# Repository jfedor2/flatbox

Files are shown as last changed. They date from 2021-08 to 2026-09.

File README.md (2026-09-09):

# Flatbox: Low profile hitbox-layout fightstick

This repository contains 3D-printable models, PCB design files and code needed to make an arcade controller that looks like this:

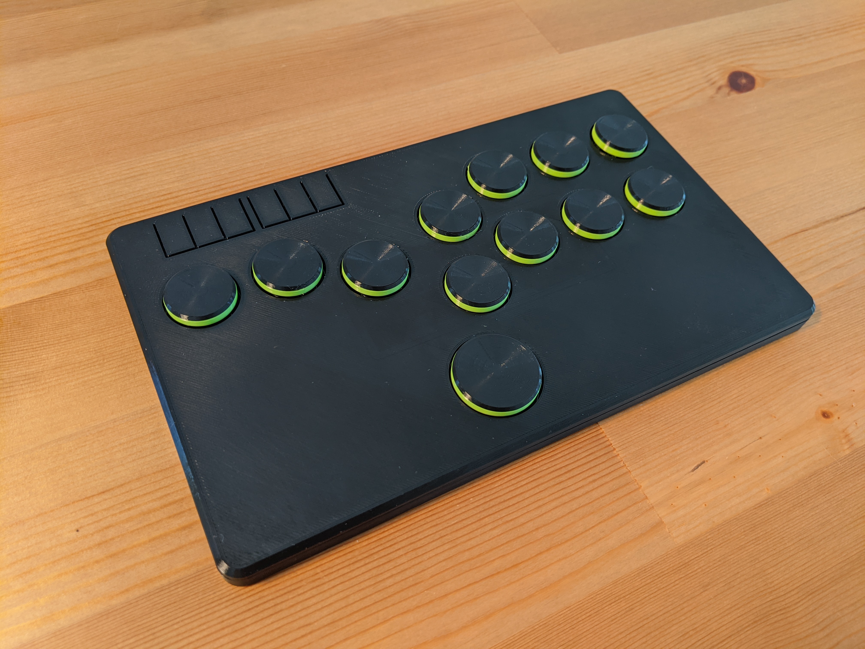
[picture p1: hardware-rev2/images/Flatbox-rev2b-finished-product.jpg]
Assembled Flatbox


There are ten major versions of the Flatbox. They all use Kailh low profile (choc v1) mechanical keyboard switches. The table below lists their main features. See the README for each version for details on how to make them.

version | case dimensions (mm) | compatibility | add-on board | onboard chip | SMT assembly required | firmware
------- | --------------- | ------------- | ------------ | ------------ | --------------------- | --------
[rev1.1](hardware-rev1.1) | 218x128x10 | PC, PS3 | Arduino Pro Micro | - | no | [ATmega32U4](firmware-atmega32u4)
[rev2](hardware-rev2) | 218x130x10 | PC, PS3 | - | ATmega32U4 | yes | [ATmega32U4](firmware-atmega32u4)
[rev3](hardware-rev3) | 218x130x10 | PC, PS3, PS4 or PC, Switch, PS3, PS4, PS5\* | [Brook PS3/PS4](https://www.brookaccessory.com/detail/58690501/) or [P5 mini](https://www.brookaccessory.com/detail/92299183/) | - | yes | [Brook](https://www.brookaccessory.com/download/)
[rev4.1](hardware-rev4.1) | 218x130x11 | PC, PS3, PS4\*, PS5\*, Switch | - | RP2040 | yes | [GP2040-CE](https://gp2040-ce.info/)
[rev5](hardware-rev5) | 218x126x10 | PC, PS3, PS4\*, Switch | [RP2040-Zero](https://www.waveshare.com/rp2040-zero.htm) | - | no | [GP2040-CE](https://gp2040-ce.info/)
[rev6](hardware-rev6) | 218x126x10 | PC, Switch | - | CH552T | yes | [CH552](firmware-ch552)
[rev7.2](hardware-rev7.2) | 218x130x11 | PC, Switch | [Xiao nRF52840 Plus](https://www.seeedstudio.com/Seeed-Studio-XIAO-nRF52840-Plus-p-6359.html) | - | no | [PGF](https://github.com/jfedor2/portable-gamepad-firmware)
[rev8](hardware-rev8) | 218x130x11 | PC, PS3, PS4\*, PS5\*, Switch | - | RP2350 | yes | [GP2040-CE](https://gp2040-ce.info/)
[rev9](hardware-rev9) | 218x130x11 | PC, Switch | - | SAMD21 | yes | [PGF](https://github.com/jfedor2/portable-gamepad-firmware)
[rev10](hardware-rev10) | 218x130x11 | PC, Switch | - | STM32G0B1 | yes | [PGF](https://github.com/jfedor2/portable-gamepad-firmware)

\* - with caveats

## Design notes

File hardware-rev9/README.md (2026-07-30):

# Flatbox rev9

This is rev9 of the Flatbox. In this version the PCB includes the microcontroller (a SAMD21 chip) - everything is built in, you only have to add the switches (and flash the firmware).

There are two variants of the case, version A uses flaps for the option buttons, version B has holes so that you can use buttoncaps on the tact switches:

Flatbox rev9 case variants

To make one you will need:

* [3D printed case parts](3d-printed-case) - top and bottom
* [the PCB](pcb)
* 12x Kailh low profile (choc v1) switches of your choice
* (optionally) 12x Kailh low profile hotswap sockets
* buttoncaps for the action buttons, either [3D printed](../3d-printed-buttoncaps) or (preferably) injection molded (make sure they're the correct size: 22.5mm and 28.5mm)
* for case variant A:
  * 6x 6x6x5mm tact switches
* for case variant B:
  * 6x 6x6x7mm tact switches
  * 6x silicone buttoncaps (like [these](https://www.aliexpress.com/item/32846395636.html) or search for "silicone button caps" on AliExpress; or you can use other caps as long as they fit, the hole diameter is 7.5mm)
* 7x M3x6 flat head (countersunk) screws
* 5x M2x4 screws to secure the PCB to the case
* some kind of rubber feet or non-slip padding for the bottom
* a soldering iron

I printed the case at 0.20mm layer height. The top part should be printed upside-down, the bottom part should be printed as-is. They don't require supports.

I used [JLCPCB](https://jlcpcb.com/) to make the PCB and assemble the SMD parts. The [included files](pcb) can be used with JLCPCB directly. If you want to use some other service, check the file formats that they expect. When ordering from JLCPCB, upload the Gerber zip, leave all the settings at default (you can choose the PCB color), then enable "PCB Assembly" and upload the BOM and CPL files in the next step. PCB thickness should be 1.6mm.

The PCB you get from JLCPCB will look like this:

Flatbox rev9 PCB with SMD parts assembled

The switches can be soldered in directly to the PCB or you can use hotswap sockets.

There are various ways that you can put firmware on the board and make it into a functional controller. Here's what I did. The relevant files are in the [binaries](binaries) folder.

1. Using an ST-Link V2 clone debug interface, put a UF2 bootloader on the board. Wire SWDIO, SWDCLK, RESET and GND lines between the ST-Link and the board and connect the board to a PC over USB for power. Then flash the bootloader with this command:<br>
`openocd -f openocd_stlink_samd21.cfg -c "init; program bootloader-flatbox_rev9-d514d82.bin verify reset; shutdown"`
2. Disconnect the ST-Link from the board.
3. Now when you connect the board to a PC, a USB drive named "FLATBOXREV9" should appear. Copy the [pgf-flatbox_rev9.uf2](https://github.com/jfedor2/portable-gamepad-firmware/releases/latest/download/pgf-flatbox_rev9.uf2) file to that drive. The board should now act as a game controller.

The UF2 firmware file used above is the [Portable Gamepad Firmware](https://github.com/jfedor2/portable-gamepad-firmware). You can find the Flatbox-specific UF2 bootloader modifications [here](https://github.com/jfedor2/uf2-samdx1/tree/flatbox-rev9). The openocd_stlink_samd21.cfg file is taken from [here](https://github.com/todbot/samd21-programming-notes).

You only have to flash the bootloader the first time. If you ever want to flash another UF2 file, press the RESET button twice quickly.

If you want to modify the case or the PCB, check out the files in the [extras](extras) folder.

Flatbox rev9 exploded view of the 3D printed case

PCB design licensed under [CC BY-SA 4.0](https://creativecommons.org/licenses/by-sa/4.0/).

PCB design uses the following libraries:

* [keyswitches.pretty](https://github.com/daprice/keyswitches.pretty) by [daprice](https://github.com/daprice) ([CC BY-SA 4.0](https://creativecommons.org/licenses/by-sa/4.0/))
* [Type-C.pretty](https://github.com/ai03-2725/Type-C.pretty) by [ai03-2725](https://github.com/ai03-2725)

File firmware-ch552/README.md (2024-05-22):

This is gamepad firmware that runs on the CH552T chip. It works with Flatbox [rev6](../hardware-rev6).

It is a minor modification of Stefan Wagner's [CH552-MouseWiggler](https://github.com/wagiminator/CH552-MouseWiggler).

To compile the firmware you need the `sdcc` compiler. To flash the firmware you need the `pyusb` Python module.

To build the firmware, run `make bin`.

To build and flash the firmware onto a board, hold the "BOOT" button while plugging the board into your computer, then run `make flash` immediately after.

To flash an existing binary, hold the "BOOT" button while plugging the board into your computer, then run `python3 tools/chprog.py gamepad.bin` immediately after.

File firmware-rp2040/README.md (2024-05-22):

This is the firmware I originally wrote for the RP2040 versions of the Flatbox ([rev4](../hardware-rev4) and [rev5](../hardware-rev5)). It is very simple and easy to understand and modify. It works with PC and PS3.

Since then, [GP2040-CE](https://gp2040-ce.info/) emerged as the de facto standard firmware for RP2040-based boards. It has many nice features like remappable buttons and configurable SOCD cleaner. You probably just want to use that instead of the firmware here. Go to the [GP2040-CE downloads page](https://gp2040-ce.info/downloads/) and get the UF2 file matching your board (Flatbox rev4 or rev5, *not* the Waveshare RP2040-Zero one, even if your rev5 board uses it).

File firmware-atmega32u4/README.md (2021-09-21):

This is Arduino code for a USB arcade controller, meant to be used with ATmega32U4-based boards like the Arduino Pro Micro.

It works with Flatbox [rev1](../hardware-rev1), [rev1.1](../hardware-rev1.1) and [rev2](../hardware-rev2).

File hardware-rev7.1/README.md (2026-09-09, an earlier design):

# Flatbox rev7.1

_**Please note**: There's a newer version of this Flatbox variant: [rev7.2](../hardware-rev7.2). It uses a Xiao Plus board and doesn't need the I/O expander._

This is rev7.1 of the Flatbox. In this version a [Seeed Studio XIAO nRF52840](https://www.seeedstudio.com/Seeed-XIAO-BLE-nRF52840-p-5201.html) board is soldered onto the main PCB.

There are two variants of the case, version A uses flaps for the option buttons, version B has holes so that you can use buttoncaps on the tact switches:

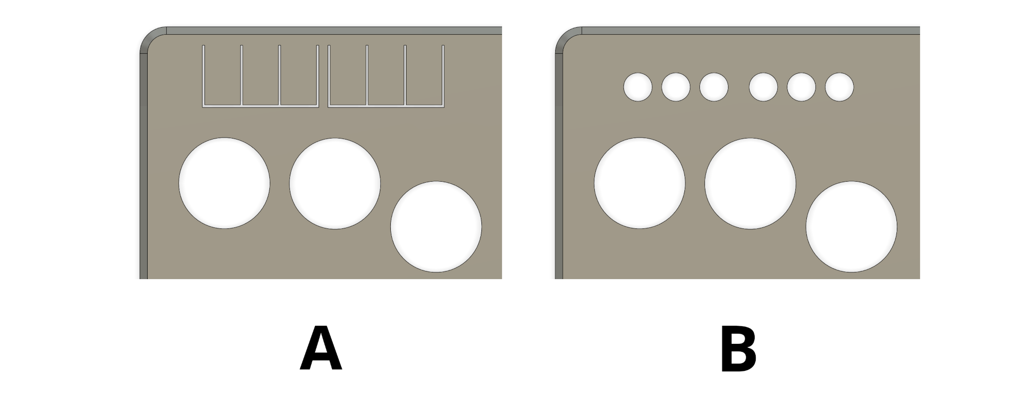
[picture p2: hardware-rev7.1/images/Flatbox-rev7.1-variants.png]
Flatbox rev7.1 case variants


To make one you will need:

* [3D printed case parts](3d-printed-case) - top and bottom
* [the Flatbox PCB](pcb)
* [Seeed Studio XIAO nRF52840](https://www.seeedstudio.com/Seeed-XIAO-BLE-nRF52840-p-5201.html)
* [MCP23S17-E/SP](https://www.microchip.com/en-us/product/mcp23s17) SPI I/O expander
* lipo battery - I used [this 1200mAh one from Pimoroni](https://shop.pimoroni.com/products/lipo-battery-pack?variant=20429082183)
* 12x Kailh low profile (choc v1) switches of your choice
* (optionally) 12x Kailh low profile hotswap sockets
* [3D printed buttoncaps](../3d-printed-buttoncaps)
* 6x 6x6x5mm tact switches
* 7x M3x6 flat head (countersunk) screws
* (optionally) 5x M2x4 screws to secure the PCB to the case
* some kind of rubber feet or non-slip padding for the bottom
* a soldering iron

I think this [lipo battery from Adafruit](https://www.adafruit.com/product/258) is the same thing as the Pimoroni one, though I'm not sure about the cable length.

Make sure you get the MCP23S17 expander in DIP package. Observe pin 1 orientation when soldering.

I printed the case at 0.20mm layer height. The top part should be printed upside-down, the bottom part should be printed as-is. They don't require supports.

The PCB can be ordered from a number of online services using the included [Gerber files](pcb), I used [JLCPCB](https://jlcpcb.com/) (leave all the settings at default, you can choose the PCB color). PCB thickness should be 1.6mm.

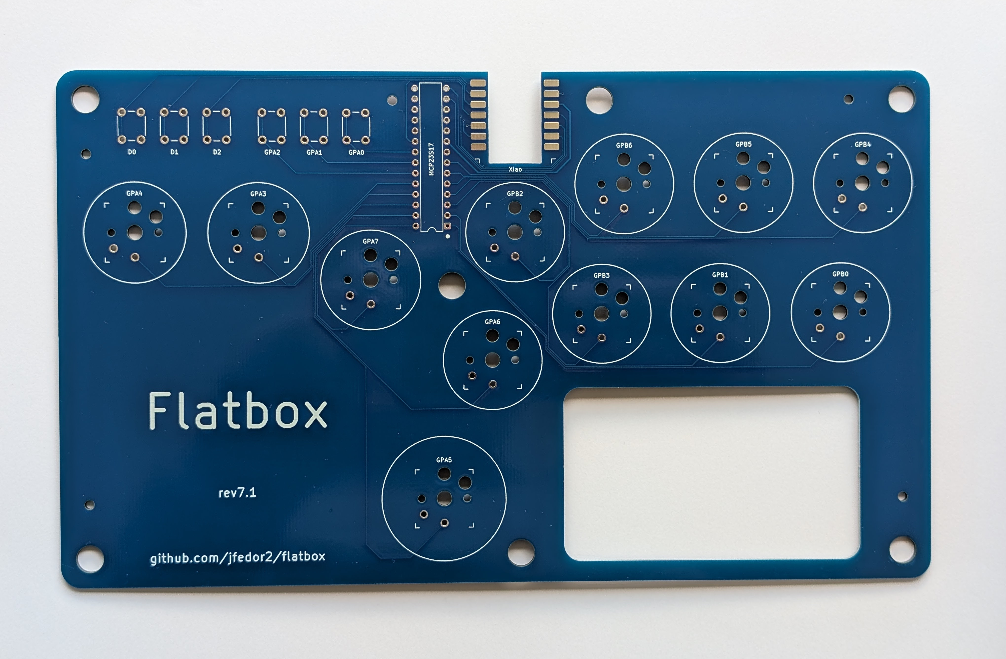
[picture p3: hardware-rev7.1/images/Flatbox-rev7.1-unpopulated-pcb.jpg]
Flatbox rev7 unpopulated PCB


The switches can be soldered in directly to the PCB or you can use hotswap sockets.

You will need to cut off the plug on the battery and solder the wires directly to pads on the bottom of the Xiao board.

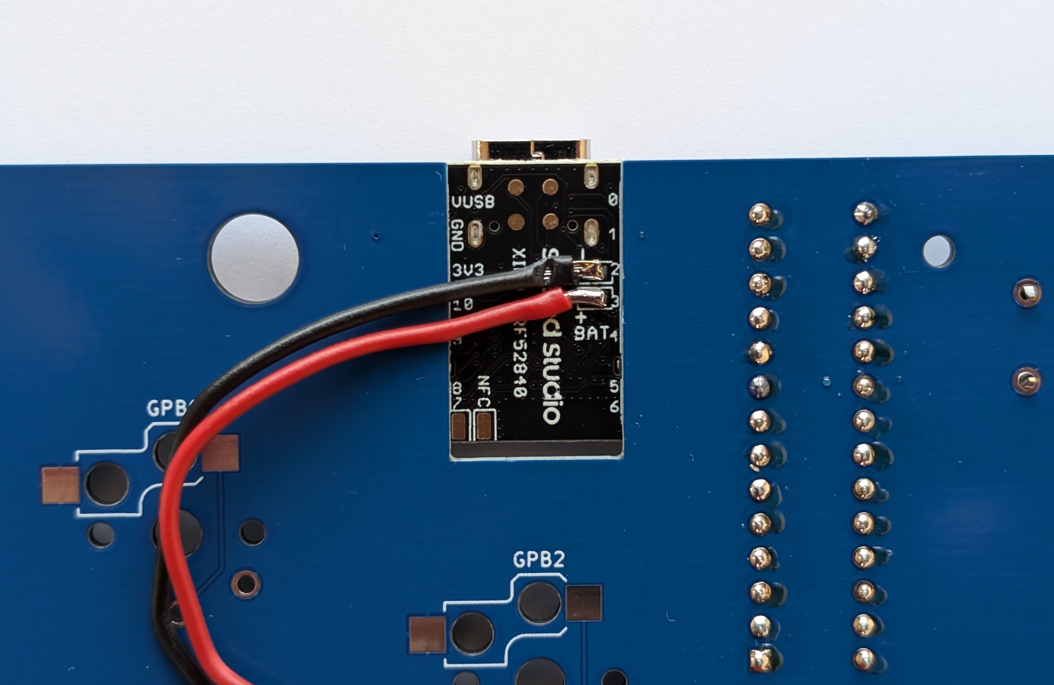
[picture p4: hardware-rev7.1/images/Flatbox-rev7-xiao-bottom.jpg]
Flatbox rev7 battery wiring


To flash the firmware, download the [pgf-flatbox\_rev7.1-nrf52840.uf2](https://github.com/jfedor2/portable-gamepad-firmware/releases/latest/download/pgf-flatbox_rev7.1-nrf52840.uf2) file from the [Portable Gamepad Firmware](https://github.com/jfedor2/portable-gamepad-firmware) repository. Then connect the board to your computer using a USB cable and press the RESET button on the Xiao board twice quickly (the RESET button is really small, next to the USB port). A USB drive should appear on your computer. Copy the `pgf-flatbox_rev7.1-nrf52840.uf2` file to that drive.

See the [Portable Gamepad Firmware](https://github.com/jfedor2/portable-gamepad-firmware) repository for general usage instructions.

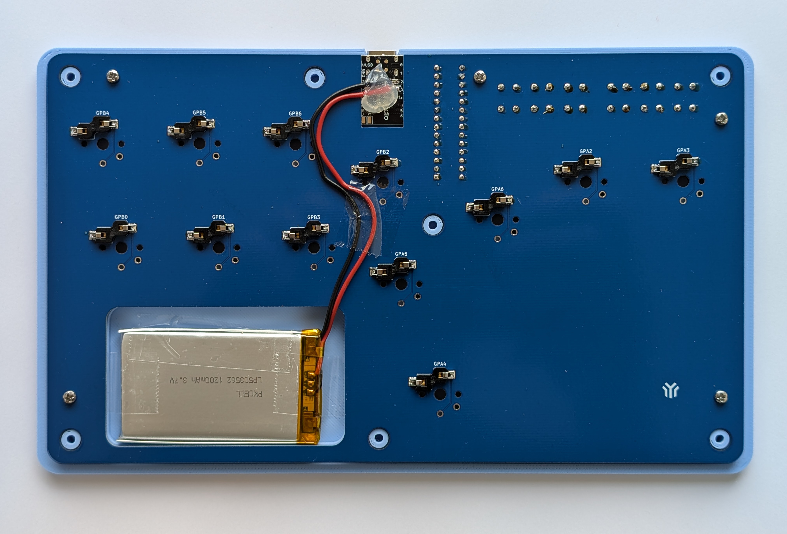
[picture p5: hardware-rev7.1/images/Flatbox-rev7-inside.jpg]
Flatbox rev7 inside the case


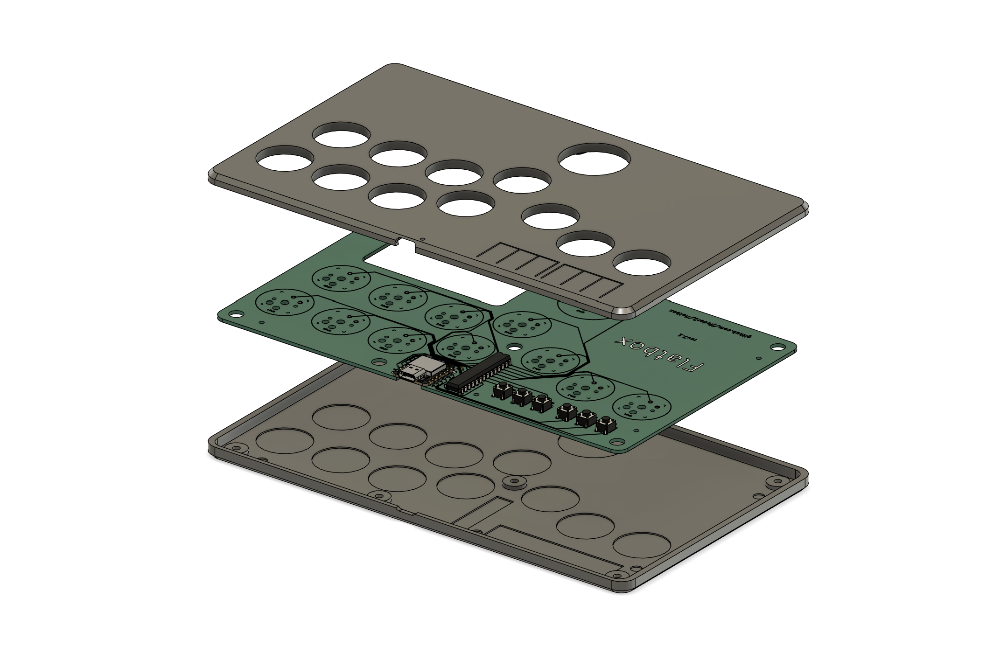
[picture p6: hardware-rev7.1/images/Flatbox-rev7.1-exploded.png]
Flatbox rev7.1 exploded view of the case


PCB design licensed under [CC BY-SA 4.0](https://creativecommons.org/licenses/by-sa/4.0/).

PCB/case design uses the following:

* [keyswitches.pretty](https://github.com/daprice/keyswitches.pretty) by [daprice](https://github.com/daprice) ([CC BY-SA 4.0](https://creativecommons.org/licenses/by-sa/4.0/))
* Xiao STEP file downloaded from [GrabCAD](https://grabcad.com/library/seeed-studio-xiao-nrf52840-sense-1)

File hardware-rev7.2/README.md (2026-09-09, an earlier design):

# Flatbox rev7.2

This is rev7.2 of the Flatbox. In this version a [Seeed Studio XIAO nRF52840 Plus](https://www.seeedstudio.com/Seeed-Studio-XIAO-nRF52840-Plus-p-6359.html) board is soldered onto the main PCB.

There are two variants of the case, version A uses flaps for the option buttons, version B has holes so that you can use buttoncaps on the tact switches:

Flatbox rev7.2 case variants

To make one you will need:

* [3D printed case parts](3d-printed-case) - top and bottom
* [the Flatbox PCB](pcb)
* [Seeed Studio XIAO nRF52840 Plus](https://www.seeedstudio.com/Seeed-Studio-XIAO-nRF52840-Plus-p-6359.html)
* lipo battery - I used [this 1200mAh one from Pimoroni](https://shop.pimoroni.com/products/lipo-battery-pack?variant=20429082183)
* 12x Kailh low profile (choc v1) switches of your choice
* (optionally) 12x Kailh low profile hotswap sockets
* [3D printed buttoncaps](../3d-printed-buttoncaps)
* 6x 6x6x5mm tact switches
* 7x M3x6 flat head (countersunk) screws
* (optionally) 5x M2x4 screws to secure the PCB to the case
* some kind of rubber feet or non-slip padding for the bottom
* a soldering iron

I think this [lipo battery from Adafruit](https://www.adafruit.com/product/258) is the same thing as the Pimoroni one, though I'm not sure about the cable length.

I printed the case at 0.20mm layer height. The top part should be printed upside-down, the bottom part should be printed as-is. They don't require supports.

The PCB can be ordered from a number of online services using the included [Gerber files](pcb), I used [JLCPCB](https://jlcpcb.com/) (leave all the settings at default, you can choose the PCB color). PCB thickness should be 1.6mm.

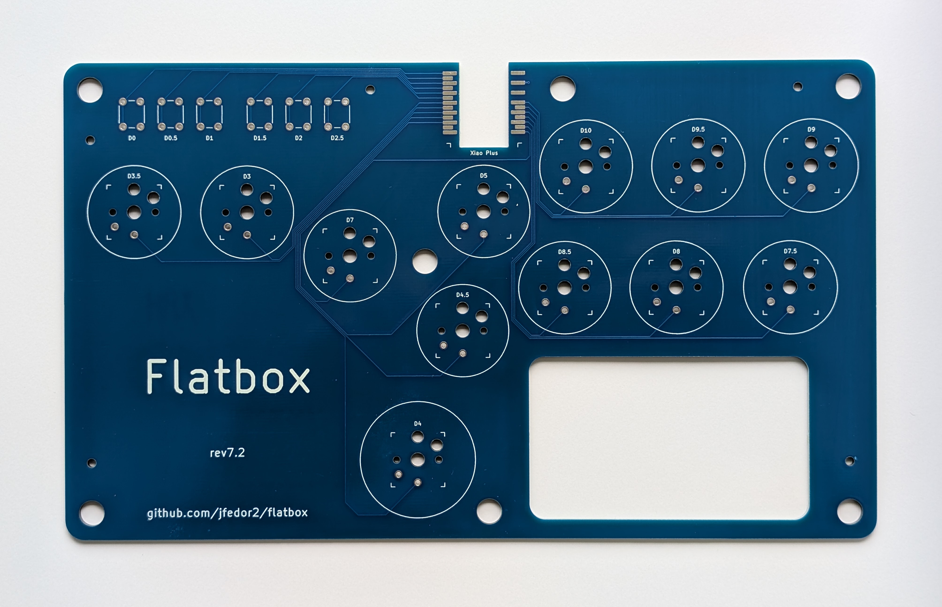
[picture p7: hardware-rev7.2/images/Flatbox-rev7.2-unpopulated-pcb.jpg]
Flatbox rev7.2 unpopulated PCB


The switches can be soldered in directly to the PCB or you can use hotswap sockets.

You will need to cut off the plug on the battery and solder the wires directly to pads on the bottom of the Xiao board.

The castellated pads on the Xiao Plus board are close together so make sure to avoid bridges. When in doubt use flux.

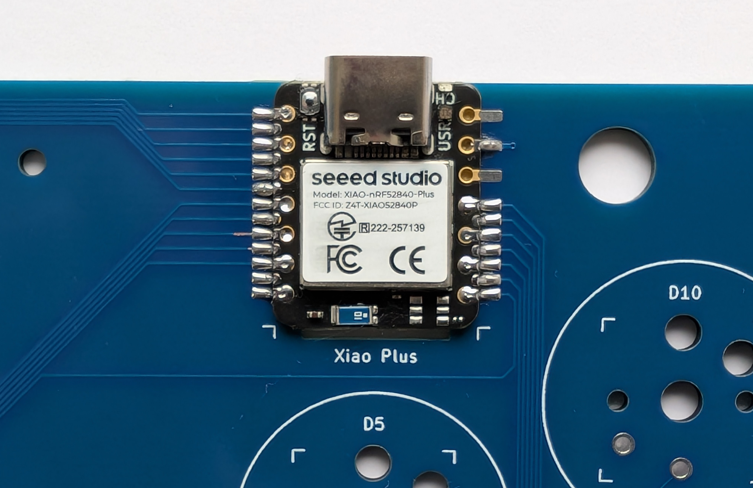
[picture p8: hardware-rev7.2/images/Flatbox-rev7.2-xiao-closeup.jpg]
Flatbox rev7.2 soldered Xiao closeup


To flash the firmware, download the [pgf-flatbox\_rev7.2-nrf52840.uf2](https://github.com/jfedor2/portable-gamepad-firmware/releases/latest/download/pgf-flatbox_rev7.2-nrf52840.uf2) file from the [Portable Gamepad Firmware](https://github.com/jfedor2/portable-gamepad-firmware) repository. Then connect the board to your computer using a USB cable and press the RESET button on the Xiao board twice quickly (the RESET button is really small, next to the USB port). A USB drive should appear on your computer. Copy the `pgf-flatbox_rev7.2-nrf52840.uf2` file to that drive.

See the [Portable Gamepad Firmware](https://github.com/jfedor2/portable-gamepad-firmware) repository for general usage instructions.

Flatbox rev7.2 exploded view of the case

PCB design licensed under [CC BY-SA 4.0](https://creativecommons.org/licenses/by-sa/4.0/).

PCB/case design uses the following:

* [keyswitches.pretty](https://github.com/daprice/keyswitches.pretty) by [daprice](https://github.com/daprice) ([CC BY-SA 4.0](https://creativecommons.org/licenses/by-sa/4.0/))
* Xiao STEP file downloaded from [GrabCAD](https://grabcad.com/library/seeed-studio-xiao-nrf52840-sense-1)

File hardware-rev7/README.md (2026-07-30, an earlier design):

# Flatbox rev7

This is rev7 of the Flatbox. In this version a [Seeed Studio XIAO nRF52840](https://www.seeedstudio.com/Seeed-XIAO-BLE-nRF52840-p-5201.html) board is soldered onto the main PCB.

To make one you will need:

* [3D printed case parts](3d-printed-case) - top and bottom
* [the Flatbox PCB](pcb)
* [Seeed Studio XIAO nRF52840](https://www.seeedstudio.com/Seeed-XIAO-BLE-nRF52840-p-5201.html)
* [MCP23017-E/SP](https://www.microchip.com/en-us/product/mcp23017) I2C I/O expander
* lipo battery - I used [this 1200mAh one from Pimoroni](https://shop.pimoroni.com/products/lipo-battery-pack?variant=20429082183)
* 12x Kailh low profile (choc v1) switches of your choice
* (optionally) 12x Kailh low profile hotswap sockets
* [3D printed buttoncaps](../3d-printed-buttoncaps)
* 6x 6x6x5mm tact switches
* 7x M3x6 flat head (countersunk) screws
* (optionally) 5x M2x4 screws to secure the PCB to the case
* some kind of rubber feet or non-slip padding for the bottom
* a soldering iron

I think this [lipo battery from Adafruit](https://www.adafruit.com/product/258) is the same thing as the Pimoroni one, though I'm not sure about the cable length.

Make sure you get the MCP23017 expander in DIP package. Observe pin 1 orientation when soldering.

I printed the case at 0.20mm layer height. The top part should be printed upside-down, the bottom part should be printed as-is. They don't require supports.

The PCB can be ordered from a number of online services using the included [Gerber files](pcb), I used [JLCPCB](https://jlcpcb.com/) (leave all the settings at default, you can choose the PCB color). PCB thickness should be 1.6mm.

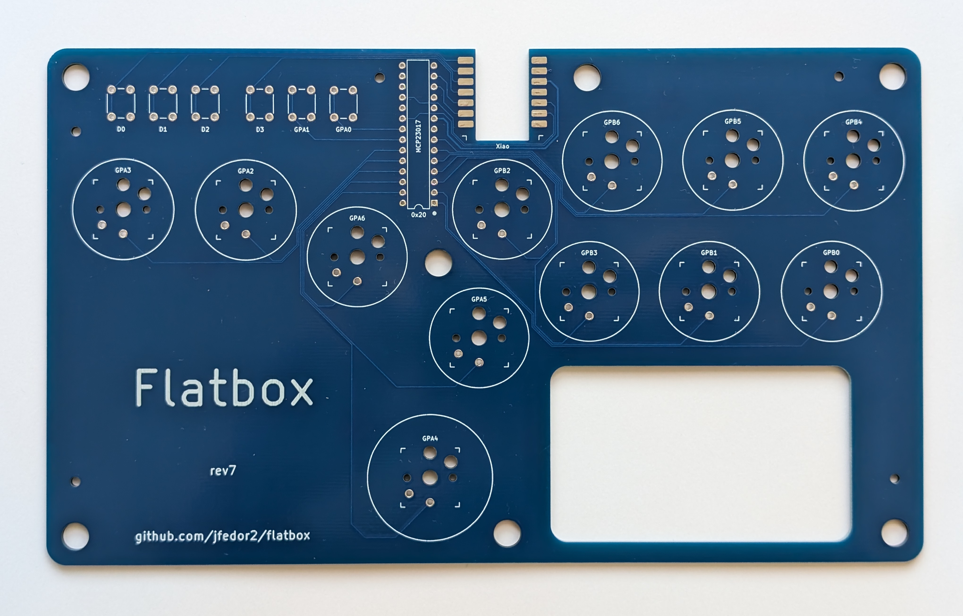
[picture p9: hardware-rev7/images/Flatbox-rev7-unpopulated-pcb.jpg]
Flatbox rev7 unpopulated PCB


The switches can be soldered in directly to the PCB or you can use hotswap sockets.

You will need to cut off the plug on the battery and solder the wires directly to pads on the bottom of the Xiao board.

Flatbox rev7 battery wiring

To flash the firmware, download the [pgf-flatbox\_rev7-nrf52840.uf2](https://github.com/jfedor2/portable-gamepad-firmware/releases/latest/download/pgf-flatbox_rev7-nrf52840.uf2) file from the [Portable Gamepad Firmware](https://github.com/jfedor2/portable-gamepad-firmware) repository. Then connect the board to your computer using a USB cable and press the RESET button on the Xiao board twice quickly (the RESET button is really small, next to the USB port). A USB drive should appear on your computer. Copy the `pgf-flatbox_rev7-nrf52840.uf2` file to that drive.

See the [Portable Gamepad Firmware](https://github.com/jfedor2/portable-gamepad-firmware) repository for general usage instructions.

Flatbox rev7 inside the case

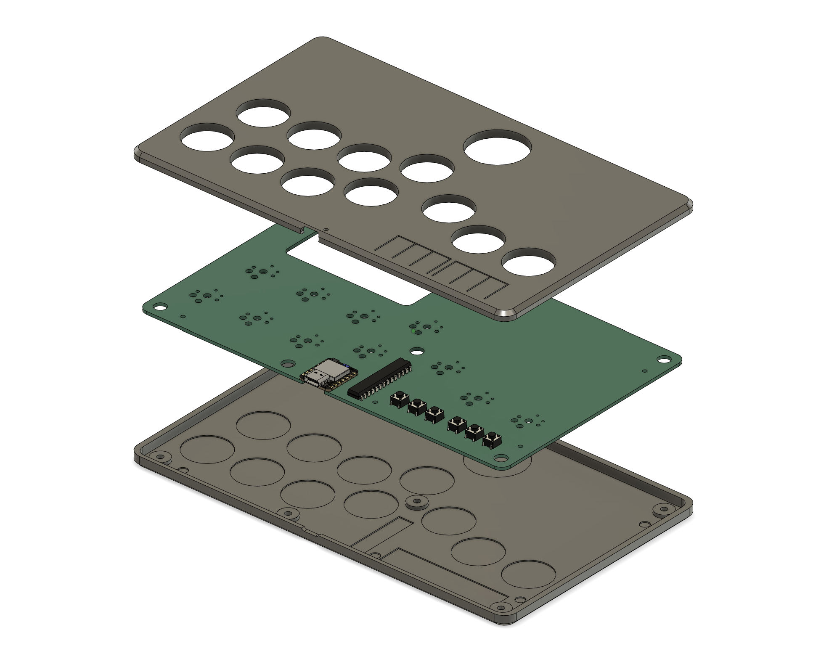
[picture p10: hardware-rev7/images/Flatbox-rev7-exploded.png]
Flatbox rev7 exploded view of the case


PCB design licensed under [CC BY-SA 4.0](https://creativecommons.org/licenses/by-sa/4.0/).

PCB/case design uses the following:

* [keyswitches.pretty](https://github.com/daprice/keyswitches.pretty) by [daprice](https://github.com/daprice) ([CC BY-SA 4.0](https://creativecommons.org/licenses/by-sa/4.0/))
* Xiao STEP file downloaded from [GrabCAD](https://grabcad.com/library/seeed-studio-xiao-nrf52840-sense-1)

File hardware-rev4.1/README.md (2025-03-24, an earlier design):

# Flatbox rev4.1

This is rev4.1 of the Flatbox. In this version the PCB includes the microcontroller - everything is built in, you only have to add the switches (and flash the firmware). It has a USB Type A host port that you can use to plug in authentication dongles or other devices if the firmware you use supports that.

There are two variants of the case, version A uses flaps for the option buttons, version B has holes so that you can use buttoncaps on the tact switches:

Flatbox rev4.1 case variants

To make one you will need:

* [3D printed case parts](3d-printed-case) - top and bottom
* [the PCB](pcb)
* 12x Kailh low profile (choc v1) switches of your choice
* (optionally) 12x Kailh low profile hotswap sockets
* buttoncaps for the action buttons, either [3D printed](../3d-printed-buttoncaps) or (preferably) injection molded (make sure they're the correct size: 22.5mm and 28.5mm)
* for case variant A:
  * 6x 6x6x5mm tact switches
* for case variant B:
  * 6x 6x6x7mm tact switches
  * 6x silicone buttoncaps (like [these](https://www.aliexpress.com/item/32846395636.html) or search for "silicone button caps" on AliExpress; or you can use other caps as long as they fit, the hole diameter is 7.5mm)
* 7x M3x6 flat head (countersunk) screws
* 5x M2x4 screws to secure the PCB to the case
* some kind of rubber feet or non-slip padding for the bottom
* a soldering iron

I printed the case at 0.20mm layer height. The top part should be printed upside-down, the bottom part should be printed as-is. They don't require supports.

I used [JLCPCB](https://jlcpcb.com/) to make the PCB and assemble the SMD parts. The [included files](pcb) can be used with JLCPCB directly. If you want to use some other service, check the file formats that they expect. When ordering from JLCPCB, upload the Gerber zip, leave all the settings at default (you can choose the PCB color), then enable "PCB Assembly" and upload the BOM and CPL files in the next step. PCB thickness should be 1.6mm.

The PCB you get from JLCPCB will look something like this:

Flatbox rev4.1 PCB with SMD parts assembled

The switches can be soldered in directly to the PCB or you can use hotswap sockets.

For the firmware you probably want to use [GP2040-CE](https://gp2040-ce.info/). Go to the [GP2040-CE downloads page](https://gp2040-ce.info/downloads/) and get the UF2 file for Flatbox rev4.

To flash the firmware, connect the PCB to a computer with a USB cable, then press the RESET button while holding the BOOT button on the PCB. A drive named "RPI-RP2" should appear. Copy the UF2 file you downloaded to that drive. That's it.

(Of course you can also use any other RP2040-compatible firmware if you want.)

If you want to use the USB host port and you need to configure it in your firmware, D+ is connected to GPIO20 and D- to GPIO21.

If you want to modify the case or the PCB, check out the files in the [extras](extras) folder.

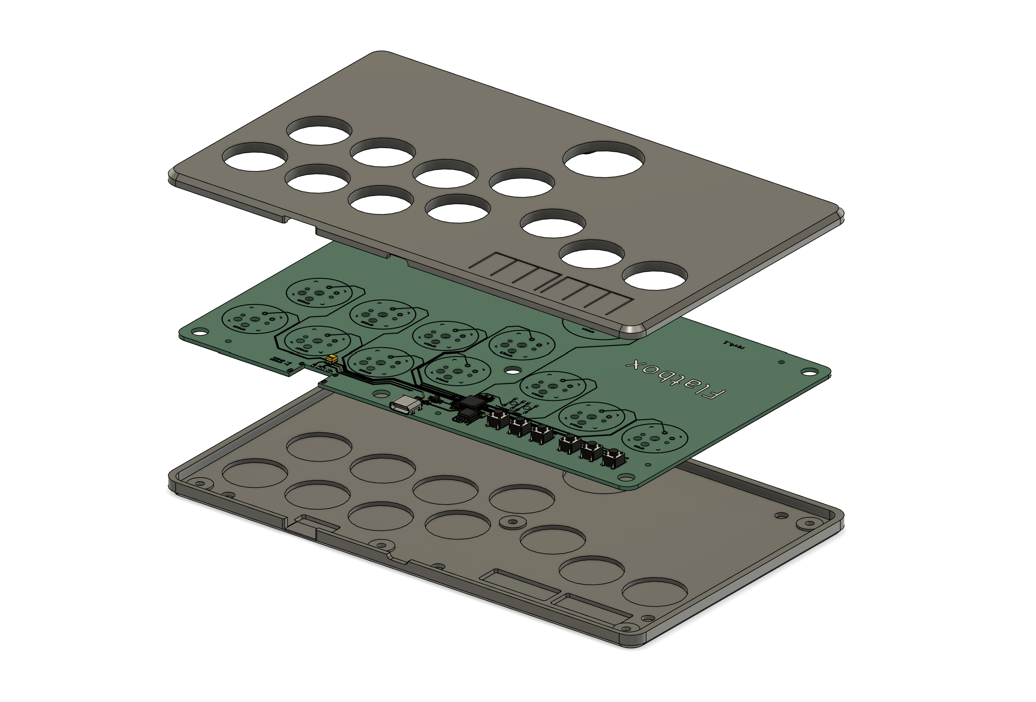
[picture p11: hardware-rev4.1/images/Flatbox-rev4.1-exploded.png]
Flatbox rev4.1 exploded view of the 3D printed case


PCB design licensed under [CC BY-SA 4.0](https://creativecommons.org/licenses/by-sa/4.0/).

PCB design uses the following libraries:

* [keyswitches.pretty](https://github.com/daprice/keyswitches.pretty) by [daprice](https://github.com/daprice) ([CC BY-SA 4.0](https://creativecommons.org/licenses/by-sa/4.0/))
* [Type-C.pretty](https://github.com/ai03-2725/Type-C.pretty) by [ai03-2725](https://github.com/ai03-2725)
* RP2040 library from the [minimal design example](https://datasheets.raspberrypi.org/rp2040/Minimal-KiCAD.zip) from the [Hardware design with RP2040](https://datasheets.raspberrypi.org/rp2040/hardware-design-with-rp2040.pdf) document

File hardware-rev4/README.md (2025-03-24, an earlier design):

# Flatbox rev4

_**Please note**: There's a newer version of this Flatbox variant: [rev4.1](../hardware-rev4.1). If you're starting fresh, it's probably better to make that one._

This is rev4 of the Flatbox. In this version the PCB includes a microcontroller and USB port. Everything is built in, you only have to add the switches (and flash the firmware).

To make one you will need:

* [3D printed case parts](3d-printed-case) - top and bottom
* [the PCB](pcb)
* 12x Kailh low profile (choc v1) switches of your choice
* (optionally) 12x Kailh low profile hotswap sockets
* [3D printed buttoncaps](../3d-printed-buttoncaps)
* 6x 6x6x5mm tact switches
* 7x 3x10mm wood screws
* some kind of rubber feet or non-slip padding for the bottom
* a soldering iron

I printed the case at 0.20mm layer height. The top part should be printed upside-down, the bottom part should be printed as-is. They don't require supports.

I used [JLCPCB](https://jlcpcb.com/) to make the PCB and assemble the SMD parts. The [included files](pcb) can be used with JLCPCB directly. If you want to use some other service, check the file formats that they expect. When ordering from JLCPCB, upload the Gerber zip, leave all the settings at default (you can choose the PCB color), then select "SMT Assembly" and upload the BOM and CPL files. PCB thickness should be 1.6mm.

The PCB you get from JLCPCB will look like this:

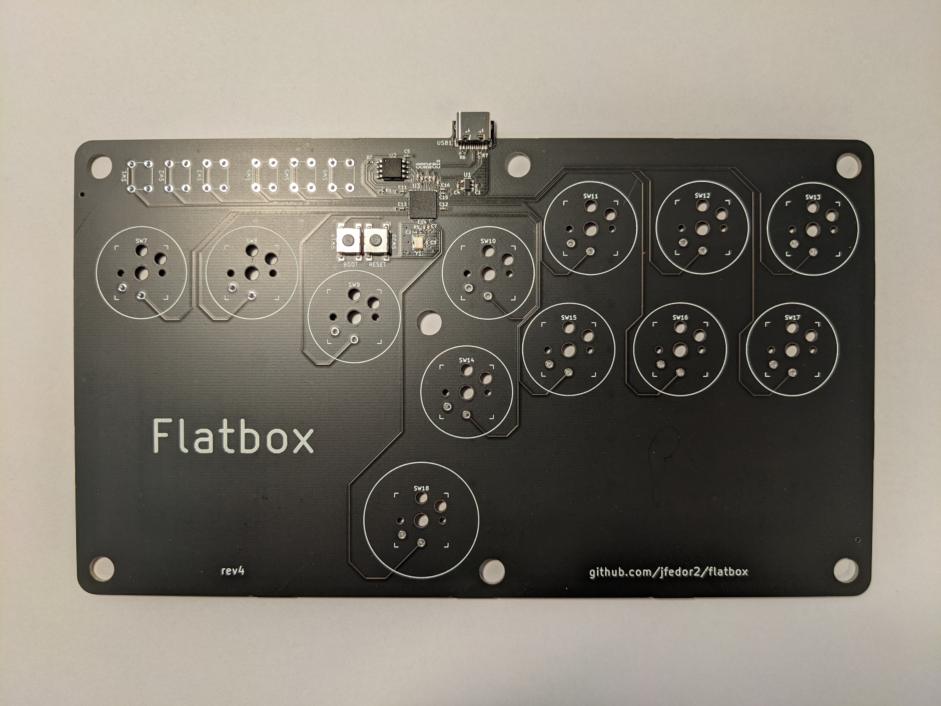
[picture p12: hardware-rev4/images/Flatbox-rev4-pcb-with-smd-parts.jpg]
Flatbox rev4 PCB with SMD parts assembled


The switches can be soldered in directly to the PCB or you can use hotswap sockets. If you want to use hotswap sockets, you will have to print the appropriate bottom part of the case (it's 1mm thicker).

For the firmware you probably want to use [GP2040-CE](https://gp2040-ce.info/). Go to the [GP2040-CE downloads page](https://gp2040-ce.info/downloads/) and get the UF2 file for Flatbox rev4.

To flash the firmware, connect the PCB to a computer with a USB cable, then press the RESET button while holding the BOOT button on the PCB. A drive named "RPI-RP2" should appear. Copy the UF2 file you downloaded to that drive. That's it.

(Of course you can also use any other RP2040-compatible firmware if you want.)

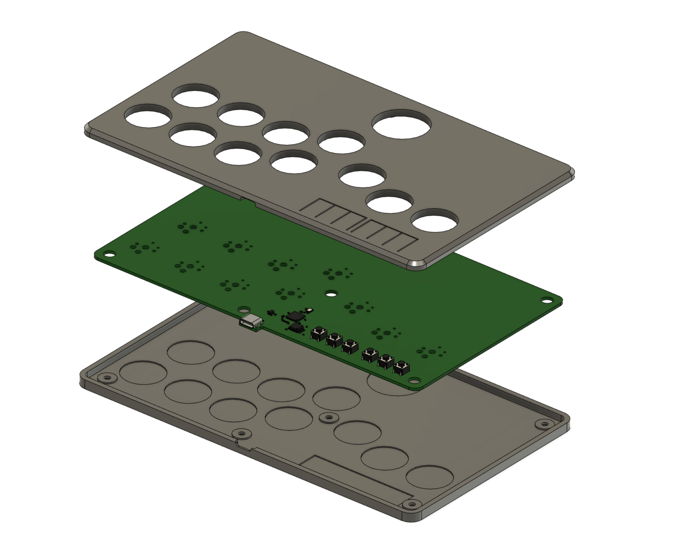
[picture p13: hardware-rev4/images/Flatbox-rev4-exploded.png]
Flatbox rev4 exploded view of the 3D printed case


PCB design licensed under [CC BY-SA 4.0](https://creativecommons.org/licenses/by-sa/4.0/).

PCB design uses the following libraries:

* [keyswitches.pretty](https://github.com/daprice/keyswitches.pretty) by [daprice](https://github.com/daprice) ([CC BY-SA 4.0](https://creativecommons.org/licenses/by-sa/4.0/))
* [Type-C.pretty](https://github.com/ai03-2725/Type-C.pretty) by [ai03-2725](https://github.com/ai03-2725)
* RP2040 library from the [minimal design example](https://datasheets.raspberrypi.org/rp2040/Minimal-KiCAD.zip) from the [Hardware design with RP2040](https://datasheets.raspberrypi.org/rp2040/hardware-design-with-rp2040.pdf) document

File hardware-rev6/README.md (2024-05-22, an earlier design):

# Flatbox rev6

This is rev6 of the Flatbox. In this version the PCB includes a microcontroller and USB port. Everything is built in, you only have to add the switches (and flash the firmware).

To make one you will need:

* [3D printed case parts](3d-printed-case) - top and bottom
* [the PCB](pcb)
* 12x Kailh low profile (choc v1) switches of your choice
* (optionally) 12x Kailh low profile hotswap sockets
* [3D printed buttoncaps](../3d-printed-buttoncaps)
* 2x 6x6x5mm tact switches
* 7x M3x6 flat head (countersunk) screws
* (optionally) 5x M2x4 screws to secure the PCB to the case
* some kind of rubber feet or non-slip padding for the bottom
* a soldering iron

I printed the case at 0.20mm layer height. The top part should be printed upside-down, the bottom part should be printed as-is. They don't require supports.

I used [JLCPCB](https://jlcpcb.com/) to make the PCB and assemble the SMD parts. The [included files](pcb) can be used with JLCPCB directly. If you want to use some other service, check the file formats that they expect. When ordering from JLCPCB, upload the Gerber zip, leave all the settings at default (you can choose the PCB color), then select "SMT Assembly" and upload the BOM and CPL files. PCB thickness should be 1.6mm.

The PCB you get from JLCPCB will look like this:

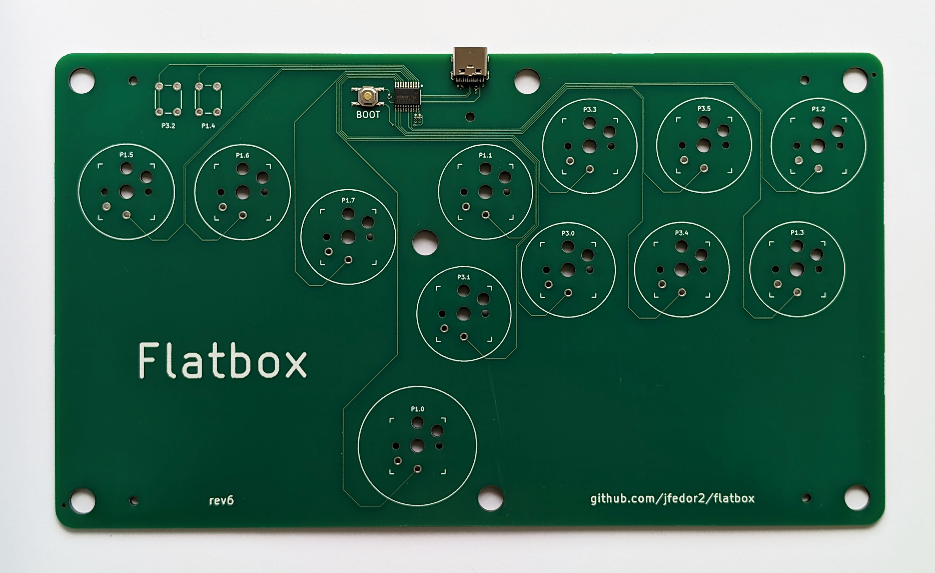
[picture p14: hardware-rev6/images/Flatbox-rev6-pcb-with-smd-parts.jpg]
Flatbox rev6 PCB with SMD parts assembled


The switches can be soldered in directly to the PCB or you can use hotswap sockets. If you want to use hotswap sockets, you will have to print the appropriate bottom part of the case (it's 1mm thicker).

See [here](../firmware-ch552) for firmware information.

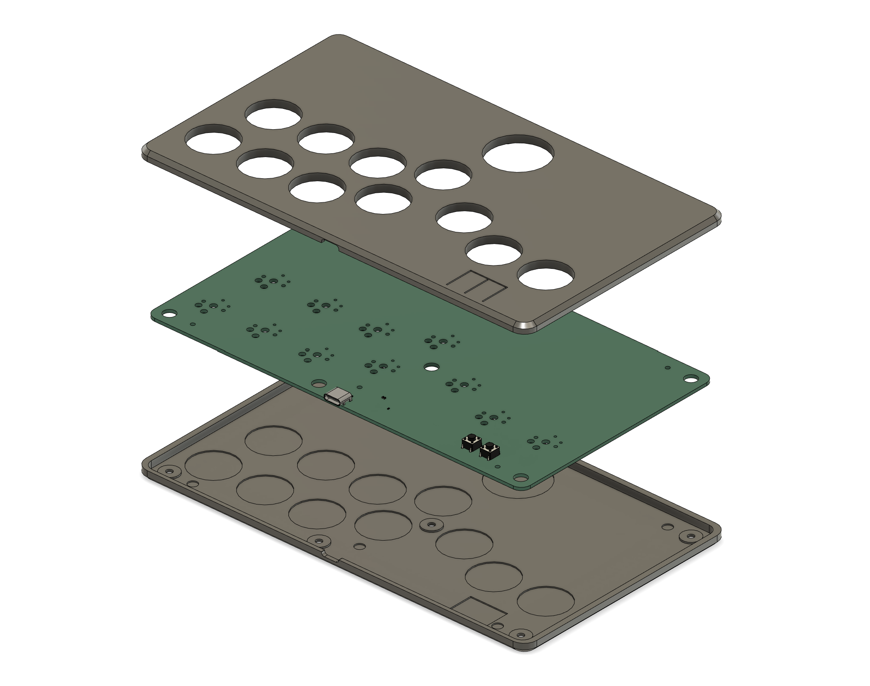
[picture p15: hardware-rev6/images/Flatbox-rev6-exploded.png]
Flatbox rev6 exploded view of the 3D printed case


PCB design licensed under [CC BY-SA 4.0](https://creativecommons.org/licenses/by-sa/4.0/).

PCB design uses the following libraries:

* [keyswitches.pretty](https://github.com/daprice/keyswitches.pretty) by [daprice](https://github.com/daprice) ([CC BY-SA 4.0](https://creativecommons.org/licenses/by-sa/4.0/))
* [Type-C.pretty](https://github.com/ai03-2725/Type-C.pretty) by [ai03-2725](https://github.com/ai03-2725)

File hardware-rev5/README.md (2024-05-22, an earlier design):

# Flatbox rev5

This is rev5 of the Flatbox. In this version an [RP2040-Zero](https://www.waveshare.com/rp2040-zero.htm) board is soldered onto the main PCB.

To make one you will need:

* [3D printed](3d-printed-case) or [CNC machined](cnc-machined-case) case parts - top and bottom
* [the Flatbox PCB](pcb)
* [RP2040-Zero](https://www.waveshare.com/rp2040-zero.htm)
* 12x Kailh low profile (choc v1) switches of your choice
* (optionally) 12x Kailh low profile hotswap sockets
* [3D printed buttoncaps](../3d-printed-buttoncaps)
* 6x tact switches: 6x6x5mm for the 3D printed case and 6x6x7mm or 6x6x8mm for the CNC machined case
* 7x M3x6 flat head screws
* some kind of rubber feet or non-slip padding for the bottom
* a soldering iron

I printed the case at 0.20mm layer height. The top part should be printed upside-down, the bottom part should be printed as-is. They don't require supports.

The CNC machined case can be ordered at [JLCPCB](https://jlcpcb.com/). I used 6061 aluminum. There are various surface finish options like bead blasting and anodizing that you can select. Be sure to select the "threads" option for the top part and upload the PDF file.

The PCB can be ordered from a number of online services using the included [Gerber files](pcb), I used [JLCPCB](https://jlcpcb.com/) (leave all the settings at default, you can choose the PCB color). PCB thickness should be 1.6mm.

The switches can be soldered in directly to the PCB or you can use hotswap sockets. If you want to use hotswap sockets, you will have to print the appropriate bottom part of the case (it's 1mm thicker). The CNC machined case is also hotswap compatible.

For the firmware you probably want to use [GP2040-CE](https://gp2040-ce.info/). Go to the [GP2040-CE downloads page](https://gp2040-ce.info/downloads/) and get the UF2 file for Flatbox rev5. Do not get the file for the Waveshare RP2040-Zero, even though your stick uses it (it has a different pinout).

To flash the firmware, connect the board to a computer with a USB cable, then press the RESET button while holding the BOOT button on the RP2040-Zero. A drive named "RPI-RP2" should appear. Copy the UF2 file you downloaded to that drive. That's it.

(Of course you can also use any other RP2040-compatible firmware if you want.)

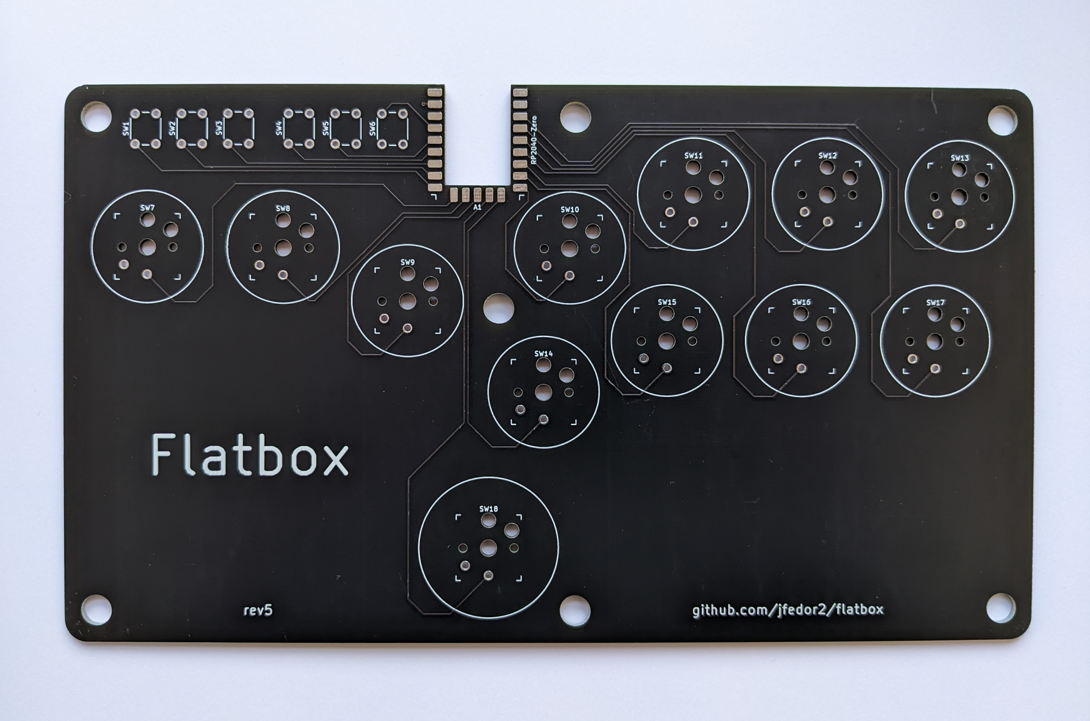
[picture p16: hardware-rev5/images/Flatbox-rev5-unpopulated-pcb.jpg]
Flatbox rev5 unpopulated PCB


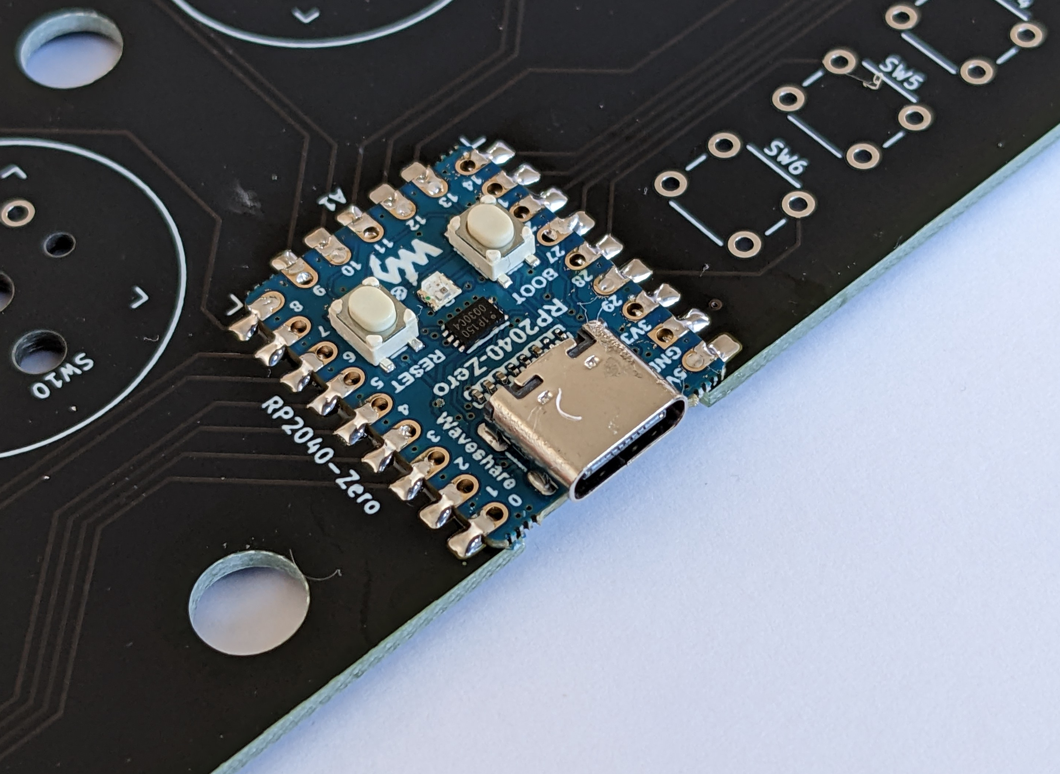
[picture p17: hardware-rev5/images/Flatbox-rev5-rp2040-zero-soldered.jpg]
RP2040-Zero soldered on top of the PCB


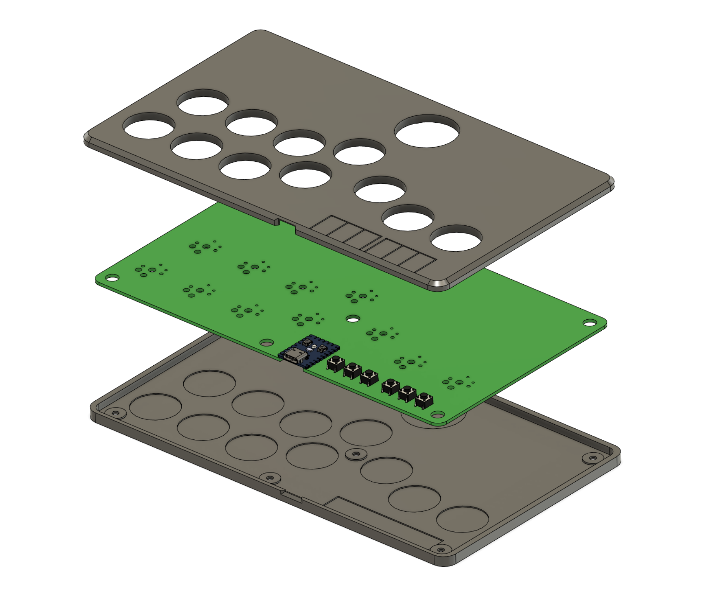
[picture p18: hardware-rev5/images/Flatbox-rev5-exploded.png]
Flatbox rev5 exploded view of the 3D printed case


PCB design licensed under [CC BY-SA 4.0](https://creativecommons.org/licenses/by-sa/4.0/).

PCB design uses the following:

* [keyswitches.pretty](https://github.com/daprice/keyswitches.pretty) by [daprice](https://github.com/daprice) ([CC BY-SA 4.0](https://creativecommons.org/licenses/by-sa/4.0/))
* RP2040-Zero STEP file downloaded from [Waveshare wiki](https://www.waveshare.com/wiki/RP2040-Zero)

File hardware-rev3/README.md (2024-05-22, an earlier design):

# Flatbox rev3

This is rev3 of the Flatbox. In this version the PCB only includes a USB port and you solder a [Brook PS3/PS4 fighting board](https://www.brookaccessory.com/detail/58690501/) or a [Brook P5 mini Fighting Board](https://www.brookaccessory.com/detail/92299183/) onto it (the small 40x40mm ones). That way you get PlayStation compatibility.

To make one you will need:

* [Brook PS3/PS4 fighting board PCB](https://www.brookaccessory.com/detail/58690501/) or [Brook P5 mini Fighting Board](https://www.brookaccessory.com/detail/92299183/)
* [3D printed case parts](3d-printed-case) - top and bottom
* [the Flatbox PCB](pcb)
* 12x Kailh low profile (choc v1) switches of your choice
* (optionally) 12x Kailh low profile hotswap sockets
* [3D printed buttoncaps](../3d-printed-buttoncaps)
* 6x 6x6x5mm tact switches
* 7x 3x10mm wood screws
* some kind of rubber feet or non-slip padding for the bottom
* a soldering iron

I printed the case at 0.20mm layer height. The top part should be printed upside-down, the bottom part should be printed as-is. They don't require supports.

I used [JLCPCB](https://jlcpcb.com/) to make the PCB and assemble the SMD parts. The [included files](pcb) can be used with JLCPCB directly. If you want to use some other service, check the file formats that they expect. When ordering from JLCPCB, upload the Gerber zip, leave all the settings at default (you can choose the PCB color), then select "SMT Assembly" and upload the BOM and CPL files. PCB thickness should be 1.6mm.

The PCB you get from JLCPCB will look like this:

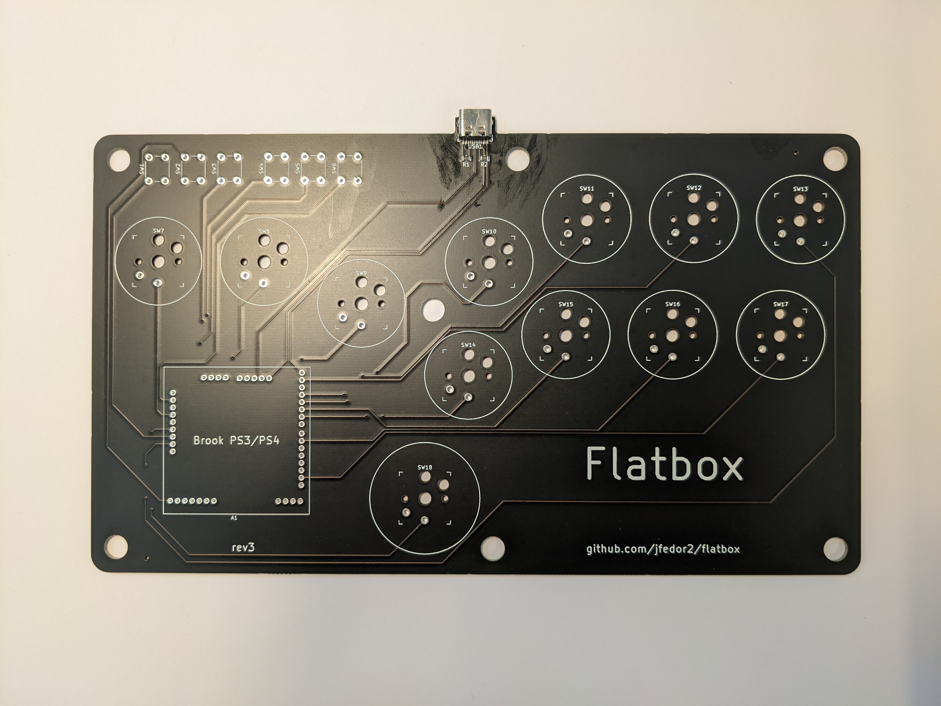
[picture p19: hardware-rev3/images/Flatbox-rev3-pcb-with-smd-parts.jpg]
Flatbox rev3 PCB with SMD parts assembled


The switches can be soldered in directly to the PCB or you can use hotswap sockets. If you want to use hotswap sockets, you will have to print the appropriate bottom part of the case (it's 1mm thicker).

The Brook board has to be soldered directly on top of the PCB, otherwise it won't fit in the case (the plastic base of the pin header can't go between the Brook board and the PCB).

Since this version uses a Brook board, it doesn't use my firmware or any open source firmware, go to [Brook's website](https://www.brookaccessory.com/download/) for firmware updates.

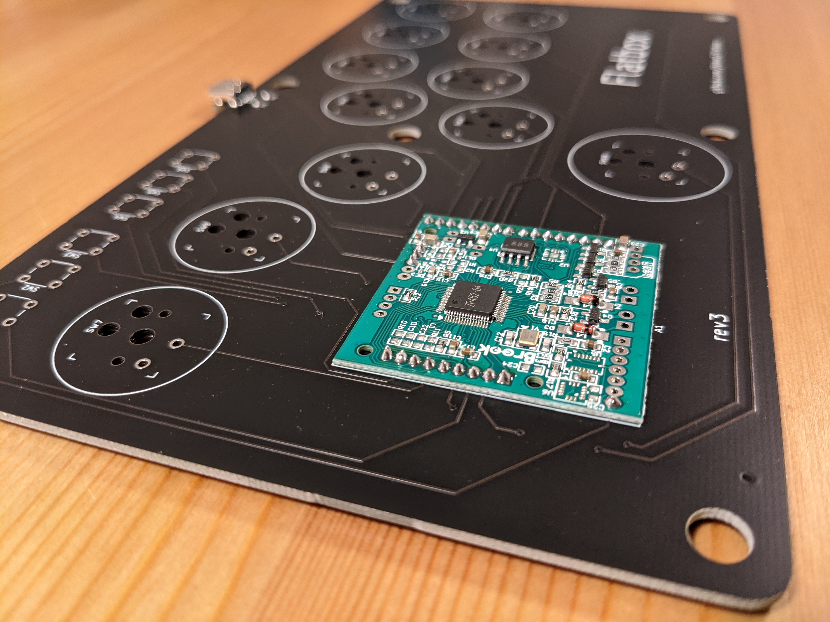
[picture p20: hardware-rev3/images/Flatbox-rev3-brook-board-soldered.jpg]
Flatbox rev3 Brook board soldered onto the PCB


Flatbox rev3 exploded view of the 3D printed case

PCB design licensed under [CC BY-SA 4.0](https://creativecommons.org/licenses/by-sa/4.0/).

PCB design uses the following libraries:

* [keyswitches.pretty](https://github.com/daprice/keyswitches.pretty) by [daprice](https://github.com/daprice) ([CC BY-SA 4.0](https://creativecommons.org/licenses/by-sa/4.0/))
* [Type-C.pretty](https://github.com/ai03-2725/Type-C.pretty) by [ai03-2725](https://github.com/ai03-2725)

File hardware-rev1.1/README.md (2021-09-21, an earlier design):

# Flatbox rev1.1

This is rev1.1 of the Flatbox. In this version an Arduino Pro Micro is soldered onto the main PCB.

To make one you will need:

* [3D printed case parts](3d-printed-case) - top and bottom
* [the Flatbox PCB](pcb)
* Arduino Pro Micro
* 12x Kailh low profile (choc v1) switches of your choice
* (optionally) 12x Kailh low profile hotswap sockets
* [3D printed buttoncaps](../3d-printed-buttoncaps)
* 6x 6x6x5mm tact switches
* 7x 3x10mm wood screws
* some kind of rubber feet or non-slip padding for the bottom
* a soldering iron

I printed the case at 0.20mm layer height. The top part should be printed upside-down, the bottom part should be printed as-is. They don't require supports.

The PCB can be ordered from a number of online services using the included [Gerber files](pcb), I used [JLCPCB](https://jlcpcb.com/) (leave all the settings at default, you can choose the PCB color). PCB thickness should be 1.6mm.

The switches can be soldered in directly to the PCB or you can use hotswap sockets. If you want to use hotswap sockets, you will have to print the appropriate bottom part of the case (it's 1mm thicker).

The Arduino has to be soldered directly on top of the PCB, otherwise it won't fit in the case (the plastic base of the pin header can't go between the Arduino and the PCB).

You don't have to use the [code](../firmware-atmega32u4) included here, you can use any other ATmega32U4-compatible firmware. The included firmware works with the PS3 and PC.

Flatbox rev1.1 unpopulated PCB

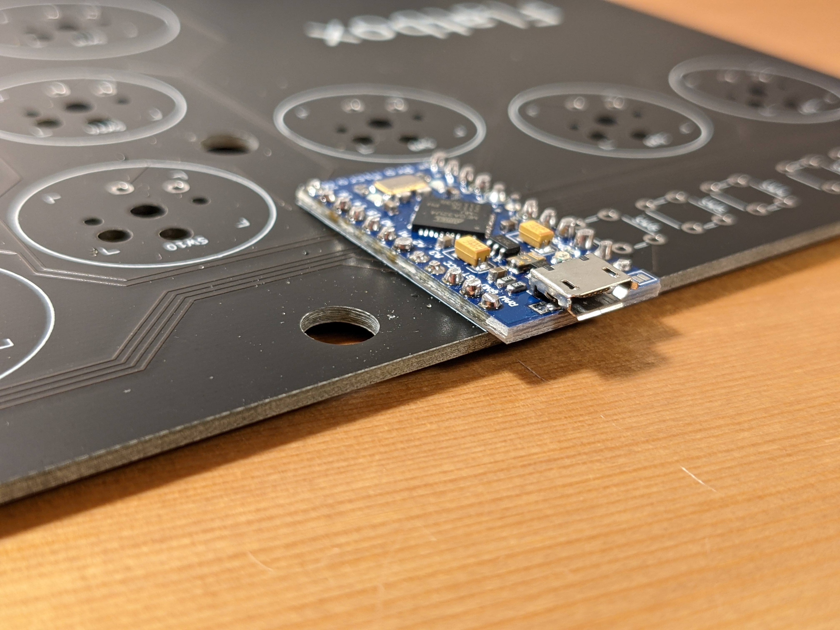
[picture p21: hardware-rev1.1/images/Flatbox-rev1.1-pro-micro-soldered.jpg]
Arduino Pro Micro soldered on top of the PCB


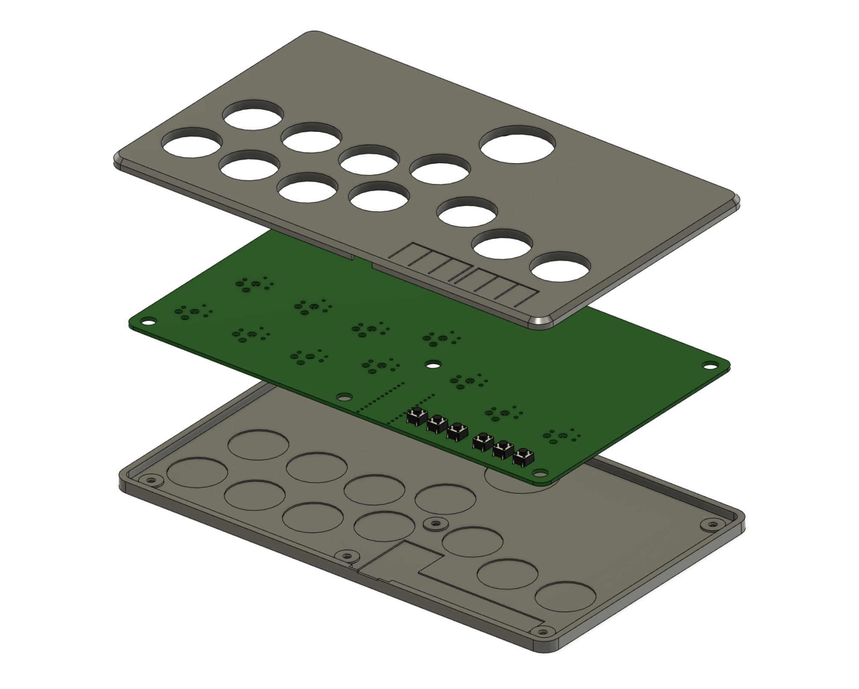
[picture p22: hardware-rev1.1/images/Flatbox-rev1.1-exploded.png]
Flatbox rev1.1 exploded view of the 3D printed case


PCB design licensed under [CC BY-SA 4.0](https://creativecommons.org/licenses/by-sa/4.0/).

PCB design uses the following libraries:

* [keyswitches.pretty](https://github.com/daprice/keyswitches.pretty) by [daprice](https://github.com/daprice) ([CC BY-SA 4.0](https://creativecommons.org/licenses/by-sa/4.0/))
* [ProMicroKiCad](https://github.com/Biacco42/ProMicroKiCad) by [Biacco42](https://github.com/Biacco42), derived from [teensy\_library](https://github.com/XenGi/teensy_library) by Ricardo Band ([MIT License](https://opensource.org/licenses/mit-license.php))

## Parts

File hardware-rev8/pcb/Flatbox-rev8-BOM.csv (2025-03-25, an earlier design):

Value | Reference | Footprint | LCSC
100n | C1,C3,C4,C5,C6,C7,C8,C9,C10,C18 | Capacitor_SMD:C_0402_1005Metric | C1525
4.7u | C2,C11,C12,C13 | Capacitor_SMD:C_0402_1005Metric,lib:C_0402_1005Metric_small_pads | C23733
1u | C14,C15 | Capacitor_SMD:C_0402_1005Metric | C52923
15p | C16,C17 | Capacitor_SMD:C_0402_1005Metric | C1548
100u | C19 | Capacitor_Tantalum_SMD:CP_EIA-3528-21_Kemet-B | C16133
500m | F1 | Fuse:Fuse_0805_2012Metric | C2833485
3.3u | L1 | lib:L_pol_2016 | C42411119
33 | R1 | Resistor_SMD:R_0402_1005Metric | C25105
27 | R2,R3 | Resistor_SMD:R_0402_1005Metric | C138021
1k | R4,R6,R8 | Resistor_SMD:R_0402_1005Metric | C11702
22 | R5,R7 | Resistor_SMD:R_0402_1005Metric | C102906
10k | R9 | Resistor_SMD:R_0402_1005Metric | C25744
5.1k | R10,R11 | Resistor_SMD:R_0402_1005Metric | C25905
SW_Push | SW19,SW20 | SW:C318884 | C318884
RP2350_60QFN | U1 | lib:RP2350-QFN-60-1EP_7x7_P0.4mm_EP3.4x3.4mm_ThermalVias | C42411118
TLV73333PDBV | U2 | SOT-23-5:SOT-23-5 | C134139
W25Q128JVS | U3 | SOIC:SOIC-8_5.23x5.23mm_P1.27mm | C97521
~ | U4 | ECMF02-4CMX8:ECMF02-4CMX8 | C717678
HRO-TYPE-C-31-M-12 | USB1 | Type-C:HRO-TYPE-C-31-M-12-Assembly | C165948
USB_A | USB2 | Type-A:C2763302 | C2763302
ABM8-272-T3 | Y1 | Crystal:Crystal_SMD_3225-4Pin_3.2x2.5mm | C20625731

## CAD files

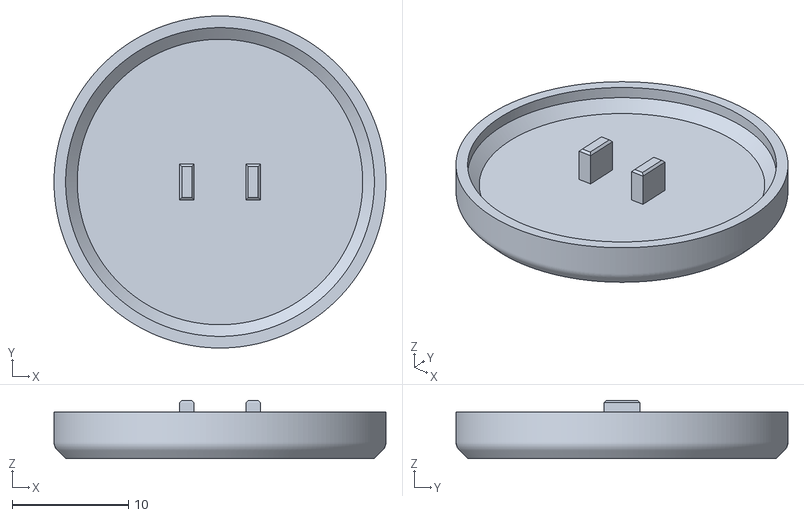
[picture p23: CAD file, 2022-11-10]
3d-printed-buttoncaps/ButtoncapBig.stl
28.5 x 28.5 x 5.00

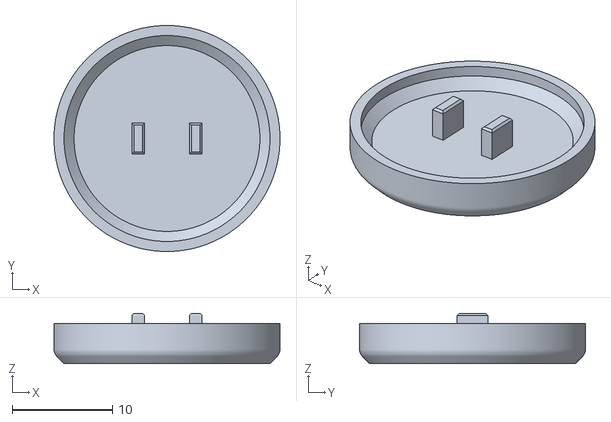
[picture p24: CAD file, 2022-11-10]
3d-printed-buttoncaps/Buttoncap.stl
22.5 x 22.5 x 5.00

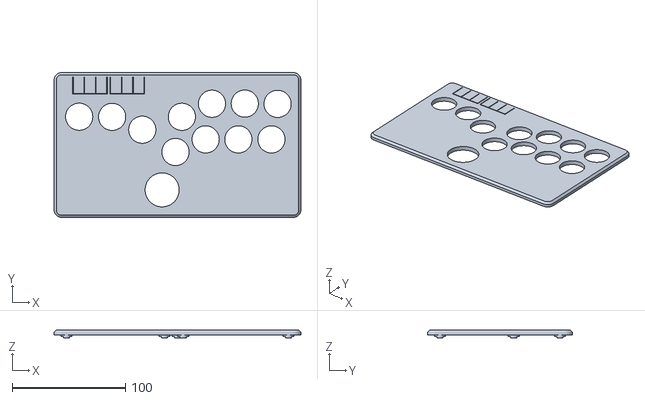
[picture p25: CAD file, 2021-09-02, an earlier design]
hardware-rev1.1/3d-printed-case/Flatbox-rev1.1-Top.stl
218.0 x 128.0 x 7.20

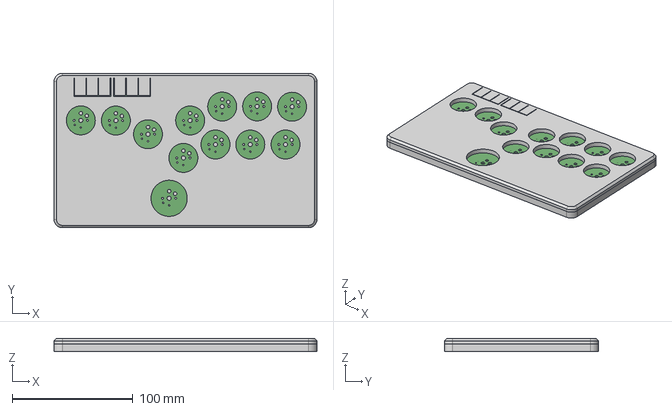
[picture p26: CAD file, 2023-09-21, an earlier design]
hardware-rev1.1/extras/Flatbox-rev1.1-case-hotswap.step
218.0 x 128.0 x 10.8 mm

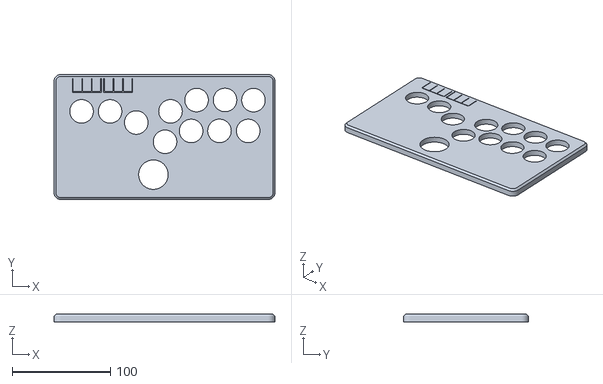
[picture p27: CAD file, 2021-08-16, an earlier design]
hardware-rev1/3d-printed-case/Flatbox-rev1b-Top.stl
225.2 x 127.4 x 7.80

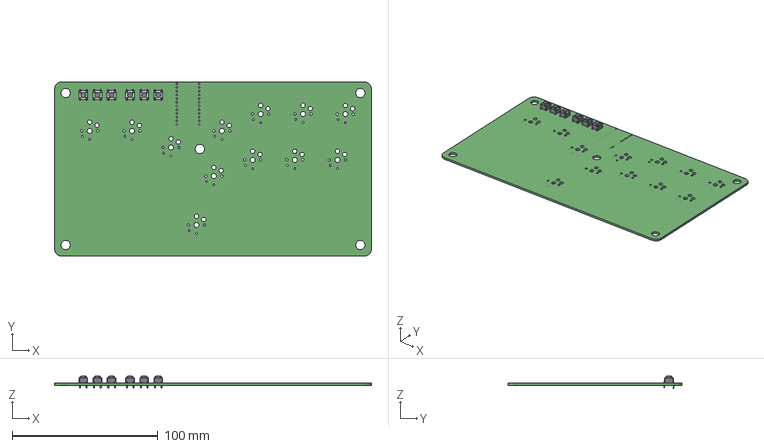
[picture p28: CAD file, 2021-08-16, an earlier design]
hardware-rev1/extras/Flatbox-rev1b-pcb.step
217.2 x 119.4 x 8.50 mm

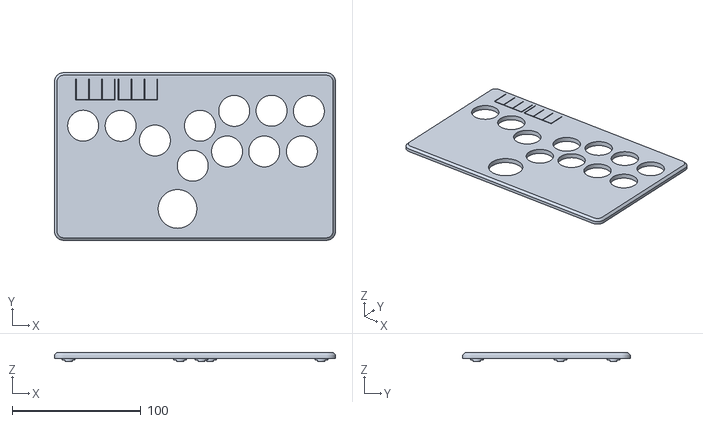
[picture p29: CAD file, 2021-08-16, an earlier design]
hardware-rev2/3d-printed-case/Flatbox-rev2b-Top.stl
218.0 x 130.1 x 7.20

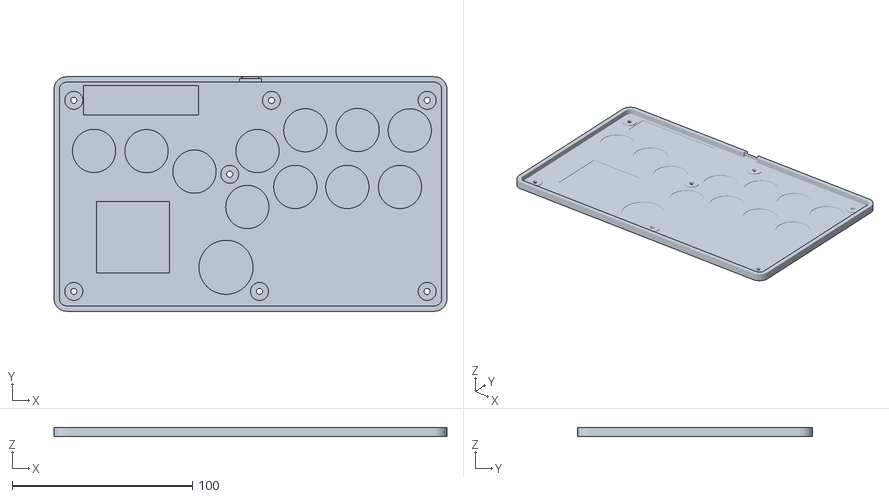
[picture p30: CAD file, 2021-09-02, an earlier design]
hardware-rev3/3d-printed-case/Flatbox-rev3-Bottom.stl
218.0 x 130.1 x 5.20

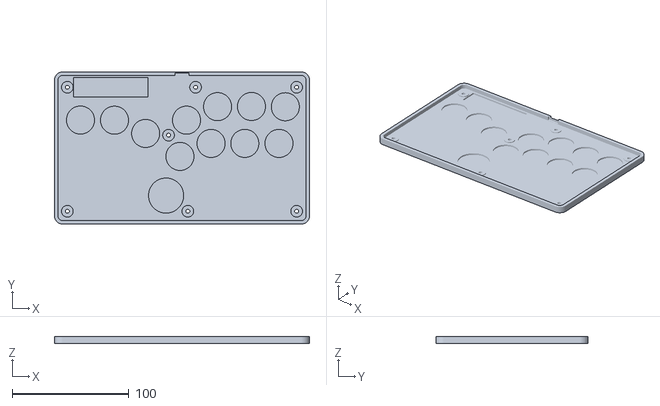
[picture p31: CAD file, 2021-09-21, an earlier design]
hardware-rev4/3d-printed-case/Flatbox-rev4-Bottom-hotswap.stl
218.0 x 130.1 x 6.20

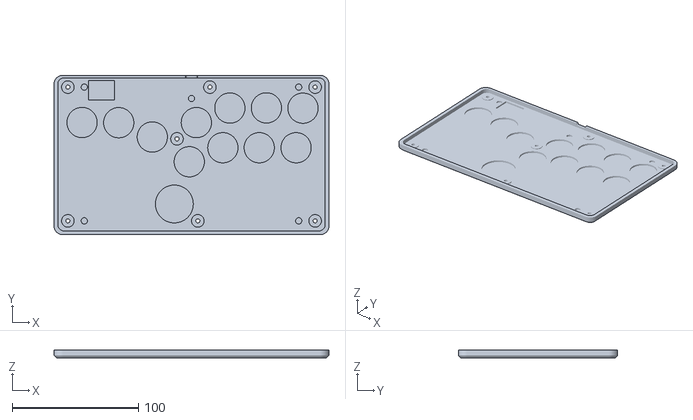
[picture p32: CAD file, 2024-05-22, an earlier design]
hardware-rev6/3d-printed-case/Flatbox-rev6-Bottom-hotswap.stl
218.0 x 126.4 x 6.20

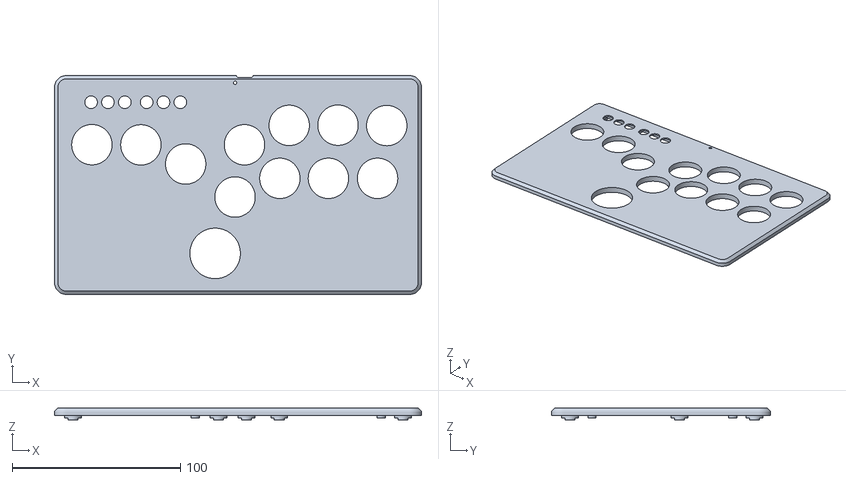
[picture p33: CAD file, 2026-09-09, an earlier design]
hardware-rev7.1/3d-printed-case/Flatbox-rev7.1-Top-B.stl
218.0 x 130.0 x 7.20

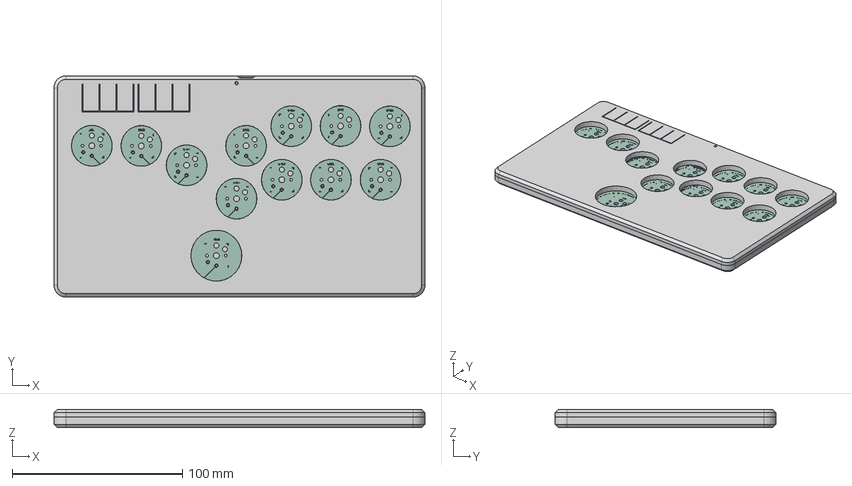
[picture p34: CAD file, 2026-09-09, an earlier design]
hardware-rev7.1/extras/Flatbox-rev7.1-case-A.step
218.0 x 130.0 x 10.8 mm
BOSS-EXTRUDE14_8_
BOSS-EXTRUDE7_4_
BOSS-EXTRUDE7_3_
BOSS-EXTRUDE14_4_
BOSS-EXTRUDE14_2_
BOSS-EXTRUDE14_11_
BOSS-EXTRUDE7_7_
BOSS-EXTRUDE14_9_
BOSS-EXTRUDE14_3_
BOSS-EXTRUDE14_7_
MIRROR2
BOSS-EXTRUDE14_5_
BOSS-EXTRUDE14_12_
BOSS-EXTRUDE7_8_
BOSS-EXTRUDE7_1_
BOSS-EXTRUDE14_10_
BOSS-EXTRUDE7_9_
BOSS-EXTRUDE14_6_
BOSS-EXTRUDE14_1_
BOSS-EXTRUDE7_6_
BOSS-EXTRUDE7_2_
CUT-EXTRUDE5
BOSS-EXTRUDE7_5_
Shield
Pins
CAP x 2
ANT1
Silkscreen
CAP 3
LED
USR
MSM261D3526H1CPM
SW_PUSH_6mm_h5mm_6 x 6
DIP-28_W7.62mm_1
FlaAA14_copper
FlaAA14_pad
FlaAA14_via
FlaAA14_silkscreen
FlaAA14_silkscreen_1
FlaAA14_PCB

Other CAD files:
hardware-rev2/extras/Flatbox-rev2b-case-hotswap.step
hardware-rev3/extras/Flatbox-rev3-case-hotswap.step
hardware-rev4/extras/Flatbox-rev4-case-hotswap.step
hardware-rev5/3d-printed-case/Flatbox-rev5-Top.stl
hardware-rev5/cnc-machined-case/Flatbox-rev5-CNC-Top.step
hardware-rev6/extras/Flatbox-rev6-case-hotswap.step
hardware-rev1.1/3d-printed-case/Flatbox-rev1.1-Bottom-hotswap.stl
hardware-rev1.1/3d-printed-case/Flatbox-rev1.1-Bottom.stl
hardware-rev1.1/extras/Flatbox-rev1.1-case.step
hardware-rev1.1/extras/Flatbox-rev1.1-pcb.step
hardware-rev1/3d-printed-case/Flatbox-rev1b-Bottom-hotswap.stl
hardware-rev1/3d-printed-case/Flatbox-rev1b-Bottom.stl
hardware-rev2/3d-printed-case/Flatbox-rev2b-Bottom-hotswap.stl
hardware-rev2/3d-printed-case/Flatbox-rev2b-Bottom.stl
hardware-rev2/extras/Flatbox-rev2b-case.step
hardware-rev3/3d-printed-case/Flatbox-rev3-Bottom-hotswap.stl
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

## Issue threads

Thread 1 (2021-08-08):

Hi. will be there a 218mm version? for ender3

neoyagami, 2021-08-08:
Hi.
the new design is great. sadly my ender3 is 8mm too small to print it,
so...

will be there a revison for ender 3 and similar (in size) printers?

jfedor2, 2021-08-08:
Rev2 case is 218mm wide and should fit on an Ender 3 (you might have to disable skirt/brim). It is only compatible with rev2 PCB though.

I'm not currently planning to do a 218mm rev1, but who knows.

jfedor2, 2021-08-28:
I actually did a redesign of the rev1 PCB to fit a 218mm wide case. I'm currently waiting for the PCBs to arrive and will post the files once I verify everything works. Should be in a week or so.

jfedor2, 2021-09-02:
I just published rev1.1 with a 218mm wide case. Hopefully it fits on your printer. Good luck.

Closed 2021-08-28.

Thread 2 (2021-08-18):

Repo history rewrite..?

JonnyHaystack, 2021-08-18:
Hi there, it appears you just rewrote the repo history 2 days ago erasing everything from before? I notice that you changed the tactile buttons to be 5x5x5mm now, with the case being redesigned to have parts that flex and act as button tops. Are there any other changes?

Would have been a lot nicer to preserve history and have commit messages describing what has changed, because I didn't even realise for a while. I just ordered 5 of the rev1 PCB the other day and I also ordered 5x5x8mm tactile switches already, so the new case design won't work with those and the old one seems to be gone now.

Thanks for sharing this project by the way, it's really awesome!

jfedor2, 2021-08-18:
Hi, yes, the repository's history has been rewritten and I'm sorry about that.

It's not that I'm not aware how git works, it was done specifically to stop hosting certain files.

If you're halfway through building the original version and don't want to switch to the new one I'm sure you'll figure something out. There were no other changes aside from the buttons. The PCB files weren't modified.

Again, sorry for the trouble.

JonnyHaystack, 2021-08-18:
Thanks for the reply, I understand :)

Closed 2021-08-18.

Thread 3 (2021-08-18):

Error to compile the firmware.

levibarrocas, 2021-08-18:
It's probably my mistake somewhere BUT when I try to compile I am getting this issue.

```
Flatbox.ino: In function 'void sendReport()':

Flatbox:192:5: error: 'HID' was not declared in this scope

     HID().SendReport(1, &report, sizeof(report));

     ^~~

Flatbox.ino:192:5: note: suggested alternative: 'PIND'

     HID().SendReport(1, &report, sizeof(report));

     ^~~

     PIND

Flatbox.ino: In function 'void setup()':

Flatbox:198:10: error: 'HIDSubDescriptor' does not name a type; did you mean 'hidReportDescriptor'?

   static HIDSubDescriptor node(hidReportDescriptor, sizeof(hidReportDescriptor));

          ^~~~~~~~~~~~~~~~

          hidReportDescriptor

Flatbox:199:3: error: 'HID' was not declared in this scope

   HID().AppendDescriptor(&node);

   ^~~

Flatbox.ino:199:3: note: suggested alternative: 'PIND'

   HID().AppendDescriptor(&node);

   ^~~

   PIND

Flatbox:199:27: error: 'node' was not declared in this scope

   HID().AppendDescriptor(&node);

                           ^~~~

Flatbox.ino:199:27: note: suggested alternative: 'tone'

   HID().AppendDescriptor(&node);

                           ^~~~

                           tone

exit status 1

'HID' was not declared in this scope

```

jfedor2, 2021-08-18:
Did you install the SparkFun Pro Micro board definition (addon) and select the Pro Micro as the board in the "Tools" menu?

Here's a walkthrough from SparkFun:

https://learn.sparkfun.com/tutorials/pro-micro--fio-v3-hookup-guide#installing-windows

(Not sure if all the driver stuff is necessary as I'm not using Windows for this. But the addon in the Board Manager is definitely necessary.)

Closed 2022-01-12.

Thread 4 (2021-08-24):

Any recomendations for 3d filaments?

neoyagami, 2021-08-24:
Hi, im havinhg some troubles with the buttons.?

pla+ one week of use were enoght to break some
petg is hard to put them (those little thingys that secure them on the switch breaks a lot)

any tips in this regard?

jfedor2, 2021-09-03:
I'm afraid I don't have any silver bullet solutions to this problem.

However I have noticed that I have made the stems (legs) on the buttoncaps a little too long. They are 4mm when they should probably be 3mm long. This means that the caps don't go into the switches fully and when pressed they don't rest on the switch, instead putting more stress on the stems than necessary. I'm not sure how much of a difference this makes in practice, but shortening the stems might help with durability. I will try and update the models after I do some more testing, but in the meantime it's easy to do with side cutters.

When it comes to precise fit, every printer might be calibrated differently so it might be worthwhile to try and scale the models a few percent up or down (possibly using the "XY size compensation" function).

hurik, 2022-09-20:
@neoyagami
I used ABS for the button caps, but I can't say anything about the durability at the moment.
I had problems with PLA, PETG and Resin. The legs were always not printed very good and I had to use a scalpel to get them to fit. Don't know why it is working so good with ABS ...

hurik, 2022-09-22:
> However I have noticed that I have made the stems (legs) on the buttoncaps a little too long. They are 4mm when they should probably be 3mm long. This means that the caps don't go into the switches fully and when pressed they don't rest on the switch, instead putting more stress on the stems than necessary. I'm not sure how much of a difference this makes in practice, but shortening the stems might help with durability. I will try and update the models after I do some more testing, but in the meantime it's easy to do with side cutters.

I made some the legs of the buttons 0,5mm shorter, to prevent problems because of not perfect prints. Here are the files: [3d-printed-buttoncaps_3p5mm_legs.zip](https://github.com/jfedor2/flatbox/files/9621085/3d-printed-buttoncaps_3p5mm_legs.zip) (Had to upload them as ZIP, because .stl is not allowed. @jfedor2 I also can make an pull request when you want ...)

Soundtoxin, 2023-02-19:
I haven't broken any caps during use yet (although I have yet to really spend a lot of time playing with the Flatbox), but I have broken 3 caps while removing them from switches. One or both of the stems breaks off in the switch. It seems I cannot safely remove the caps at all once they're on. Also, to get the broken plastic out of the switch, I've been melting the side of the broken keycap to the part of the plastic inside the switch with a soldering iron (Pinecil v2) set to 220C. After 10 seconds or so cooling it should be solid enough to pull out the broken bit of plastic (takes a lot of force). May need to attempt the melting part a couple times.
I made the Flatbox rev5, not sure if the keycaps differed between revisions. Looking at the commit history, I think I already used the updated buttoncaps with the shorter stems (I did my builds this year). I've been using Inland brand PLA+ in various colors and printing on an Ender 3 v2 (I have not tried printing other materials on this printer before).

jfedor2, 2023-03-12:
To anyone having issues with printing the buttoncaps on FDM printers, here's another option, order these from JLCPCB:

https://github.com/TheTrainGoes/GP2040-Projects/blob/main/Open%20Source%20Buttons/Choc%20v1/Flatbox%20JLC%20sprue.stl

Choose 9000R or Black resin. It should be very cheap, like 2 or 3 USD for a whole set.

(Unfortunately you can't combine shipping when ordering PCBs and 3D prints at JLCPCB.)

jfedor2, 2024-12-02:
For anyone still having issues with 3D printed buttoncaps, you can now get correctly sized injection-molded buttoncaps on AliExpress.

For example I've had success with these:

https://www.aliexpress.com/item/1005006980269582.html

Make sure you get the 22.5/28.5mm ones.

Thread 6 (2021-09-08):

Differences between Rev1 and Rev1.1

KaneBlueriverCL, 2021-09-08:
I saw the model was updated, I assume at a quick glance that the size of the case was standarized vs. newer revisions? If so, is the PCB size also changed? Thanks for your time!

jfedor2, 2021-09-08:
That's right. Compared to rev1 the case is slightly narrower so it should now fit on Ender 3 printers. The PCB size also changed to accommodate this (rev1 and rev1.1 aren't compatible with regard to cases). There's more mounting screw holes and slightly more clearance above and below the PCB in the case.

Closed 2021-09-20.

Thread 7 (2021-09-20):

Rev 2 additional material requirements

huynhwi, 2021-09-20:
when making the rev2, the list of materials needed seem incomplete. It looks like you need a usb-c female header. Is there any other materials needed to make this board?

jfedor2, 2021-09-20:
The USB connector is part of the SMT assembly BOM along with the ATmega32U4 chip and all the other components. If you order the PCB with SMT assembly from JLCPCB (or some other place) then you don't need to get those individual parts yourself. If you want to do the assembly yourself then sure, add the entire BOM to the list of parts needed.

Closed 2021-09-20.

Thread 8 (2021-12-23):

Consider RP2040-Zero variant

JonnyHaystack, 2021-12-23:
I've just seen this tiny Pico alternative https://www.aliexpress.com/item/1005003504006451.html which looks like it should be easy to design around and would allow for a much cheaper non-SMD RP2040 version of the flatbox. It has a variant that comes with pin headers as well, which would make the soldering really easy because if you had holes for all the pins on your PCB the builder would only have to solder on one side. Also it has USB C!

jfedor2, 2022-11-10:
An RP2040-Zero based rev5 is now released!

d75cce5

mytokat84, 2022-11-10:
Hello, why you dont use 0.96 inç screen and leds?

TheTrainGoes, 2023-02-21:
@mytokat84 with a 0.96" OLED screen added you would need to adjust the pinout to ensure a good I2C pair.

With the current setup you would be limited to choosing either OLED or RGB but not both as you would be short one pin.

There are additional pads on the back of the Zero you could use for this but they are a pain to tap into.

mytokat84, 2023-02-21:
but you can add oled and rgb same time if you cancell L3 and R3 Buttons. Isnt it? L3 and R3 is not necessary to playing any fighting game.. Actually I draw a PCB with oled and I just couldnt add RGB because I dont know which SMD part must be used on rp2040 zero. I researced pico fighting boards rgb outputs on pcb bu I couldnt understand that why there is no connections 2 pieces of 5 volt outputs on 4 pin rgb outputs.

TheTrainGoes, 2023-02-21:
@mytokat84 you can replace L3 and R3 with an OLED if you like.  I would need to check the pins and make sure they can be used as a proper pair for the I2C line.  You would also need to add two resistors on the SDA and SCL lines (I use 4.7k).

For the RGB line you need to to have a 5v logic shifter on the data line (move from 3.3v to 5v).  You will also need a cap and a resistor (100nF and 10k).

Closed 2022-11-10.

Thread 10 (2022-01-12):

release the working files for the cases?

satorusaka, 2022-01-12:
I'm building a few of rev 1.1 Flatboxes but I've bought usb-c version of the pro micro. it is slightly longer than the original pro micro so it wont fit. im thinking if you can release the working files so i can modify it to fit. thanks!

jfedor2, 2022-01-12:
I added STEP files for the case models. You should be able to work with that.

satorusaka, 2022-01-13:
Alright! Thanks a lot!

JonnyHaystack, 2022-02-05:
@satorusaka Did you make that modification successfully yet? When you do, please could you share it? 😄 I also wanted to use some of the USB C pro micros I bought, because I used Elite Cs in the first one I made but those are very expensive.

satorusaka, 2022-02-06:
> @satorusaka Did you make that modification successfully yet? When you do, please could you share it? 😄 I also wanted to use some of the USB C pro micros I bought, because I used Elite Cs in the first one I made but those are very expensive.

yeah I've made a few other adjustments to the case including making it compatible with a USB-C Pro Micro. The screw holes have been changed to use m3x8 screws, I've also changed the holes to fit a round-head hex screw flush to the bottom of the case, because of that the case is thicker at 12mm instead of 10mm.

I've also added a lip around the side walls for it to align it self when I put it together.

Here's the .3mf and .step files.
[Flatbox-rev1.1-case usb-c.zip](https://github.com/jfedor2/flatbox/files/8010622/Flatbox-rev1.1-case.usb-c.zip)

JonnyHaystack, 2022-02-06:
Thanks! Will check it out :smile:

natsumi, 2023-02-18:
@satorusaka Are you able to make the screw hold changes to the rev4 case?  It would be nice if the rev4 was also able to use m3x8 screws and have a flush screw

Closed 2022-01-13.

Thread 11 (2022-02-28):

Could this be updated to support either Lailh v2/Cherry/Gateron low profile?

CallMeAreks, 2022-02-28:
These switches can use the keycap with the cross-style form. This opens much more options to choose from, like [these](https://es.aliexpress.com/item/1005003327722072.html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,scm-url:1007.40050.266918.0,pvid:8e6ef45b-c3c9-4167-b235-4970c6424a87,tpp_buckets:668%232846%238107%231934&pdp_ext_f=%257B%2522sku_id%2522%253A%252212000026795931939%2522%252C%2522sceneId%2522%253A%252230050%2522%257D&pdp_pi=-1%253B212.84%253B-1%253B-1%2540salePrice%253BMXN%253Brecommend-recommend):

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

tdpssn, 2022-03-10:
+1 to this suggestion.

Looking at the specs, the V1's appear to be 13.8mm x 13.8mm, so I'm assuming thats the opening on the current box?

V2's are 13.95mm x 13.95mm so it's not too much of a change, but I'm not sure if I'm reading the specs right, as I've never CAD'd anything.

Specs at bottom of respective pages
V1 http://www.kailh.com/en/Products/Ks/CS/321.html vs
V2 http://www.kailh.com/en/Products/Ks/CS/755.html

CallMeAreks, 2022-03-10:
The size I don't think it's too big of a change but probably  it also requires changing the position of the holes where the hotswap sockets/switches are inserted and soldered.

StdVectorBool, 2022-10-29:
The regular [footprint overlay](https://deskthority.net/wiki/Kailh_PG1353_series) shows the V2 actuator pins are compatible with V1 but:
1. Central pin is larger (5mm diameter)
2. Extra unconnected stabilizer pin (opposite corner from actuators)

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

Other libraries support dual V1/V2 footprints by enlarging the central pin and adding the extra stabilizer:
* [V1 / V2 solder](https://github.com/perigoso/keyswitch-kicad-library/blob/main/library/footprints/Switch_Keyboard_Kailh.pretty/SW_Kailh_Choc_V1V2.kicad_mod)
* [V1 / V2 hotswap](https://github.com/perigoso/keyswitch-kicad-library/blob/main/library/footprints/Switch_Keyboard_Hotswap_Kailh.pretty/SW_Hotswap_Kailh_Choc_V1V2.kicad_mod)

but this overlay example shows the new stabilizer unfortunately interferes with the elegant Optional Hotswap design:
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

Instead of producing two variants (solder vs hotswap) of a new Rev (for Choc V2), it might be faster to just enlarge that center drill to 5mm and flush cut the new stabilizer (or disassemble the switch and remove it).

StdVectorBool, 2022-11-10:
Will update with photos after my JLCPCB order arrives. :crossed_fingers:

StdVectorBool, 2022-11-15:
Manually removed the 3rd unconnected pin rather than flush cutting:
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

Lines up flush with the 5mm center:
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

@jfedor2 would you prefer a PR for the rev4 directory instead of forking? Thinking about committing the KiCAD ZIP extracted so it's clear this is a footprint-only change.

StdVectorBool, 2022-11-15:
Still missing a soldering iron but will post photos of dry-assembly when my buttons arrive.  I didn't modify the 3D printed button caps and ordered the Sinoaracde buttons linked by the OP.

StdVectorBool, 2022-11-18:
Dry assembly, still waiting on a soldering iron:
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

Don't have the V1s button/switch to compare but the Sinoarcade buttons protrude 4-6 mm from the 3D printed case.
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

@jfedor2 Any chance you can provide the source CAD files for the STL? Trying to think about how to raise the surface to recess the Sinoarcade caps while still allowing the tact switches to work.

jfedor2, 2022-11-18:
@StdVectorBool Thank you for the pictures. There's a STEP file of the case in the "extras" folder, let me know if that works for you. I can probably get you the Fusion 360 file as well if that's what you're using.

StdVectorBool, 2022-11-27:
@tdpssn @CallMeAreks
Updated Gerber file available in my fork:
https://github.com/StdVectorBool/flatbox/tree/master/hardware-rev4

You'll need to remove the 3rd unconnected pin.

SuperPrower, 2022-12-15:
Are those low-profile v2 switches compatible with old ('choc') hotswap sockets?

StdVectorBool, 2022-12-15:
Yes, Choc V1 and Choc V2 use same hotswap sockets.  Only minor difference is PCB footprint for stabilizers.

SuperPrower, 2022-12-16:
Good to know, thanks. Did you have a chance to solder the switches on? I wonder how stable they are without that pin.

StdVectorBool, 2022-12-16:
I stuck with the hotswap sockets and did not solder the switches.  The socket keeps them flat against the PCB so they're stable on 2-axis, but if you intentionally twist the button there is a small amount of play in the 3rd direction.  Time will tell.

SuperPrower, 2022-12-16:
Thanks, that's what I wanted to hear. I've ordered all the components and the boards, will write about my experience once I've built everything

SuperPrower, 2023-01-19:
Okay, it took a few attempts to get a 3d-printed case done, but I have finished my build of @StdVectorBool 's version.
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

I've used FreeCAD to modify the top part of the case from the step file. I've did three things:
1. Raised the walls (and the mounts) by 3mm, so that the buttons won't stick too high above the surface and so that you could do moves like sliding your finger across multiple buttons with comfort and not pop the switch out of sockets. For why this could be useful, see https://www.youtube.com/watch?v=6OULtbPO4fw

This, however, proved to be too much of a raise, at least a little bit. I'm by no means a sophisticated leverless controller user, so I don't know which height level would be comfortable, but I'm going to try and sand the walls back down a little bit over time:
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
I imagine that 2-2.5mm additional height would be a sweet spot.

2. Made a cutout in the cylinder parts to fit a brass inserts. I don't like the idea of using a wood screw, since I imagine that the controller would need maintenance, fixes or improvements over time. I've managed to comfortably fit an m2 brass insert and connect the pieces with m2x6mm screws.

3. Since the buttons from Sinoarcade are smaller than the holes, I've reduced the size of their holes slightly - they are now 22mm and 27.8mm for the small buttons and large button respectively. That was just enough tolerance to have almost no visible gaps between the case and the buttons, while still giving enough room to press and tilt the buttons and not have them stuck under the case. I imagine that there is a good scientific way to calculate that tolerance, but it worked out for me, with average quality PETG printing.

There are a few problems that I couldn't solve with my limited CAD knowledge:
1. The printed flap buttons couldn't reach tactile switches anymore, duh. I've ordered a set of tactile switches that are 9.5mm tall from the PCB to the top of the button, this was too tall. I should've measure proper height in the CAD, buuut I just nibbled and sanded them with cutters and files.
2. USB-C port now has a hole on top of it, since I couldn't easily raise it's 'arch' along with the rest of the walls, with how its cutout integrated into the rest of the case:
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

So, in the end, I don't think it's just enough to have a modified PCB. There is some (more) work that would need to go into making a case fit a proposed combination of switches and buttons. If anyone is interested, I'm attaching my FreeCAD file, though there is nothing much of interest:
[top.zip](https://github.com/jfedor2/flatbox/files/10452340/top.zip)

SuperPrower, 2023-01-20:
Here is a v2 of the top part of the case. It's a bit more organized for a FreeCAD file, should be easier to edit (hopefully...). Don't know when I'll get to print it and try it out, since I don't own a 3D printer and did the printing at local hackspace, but if anyone wants to give it a try, here are the FreeCAD and stl files:
[top2.zip](https://github.com/jfedor2/flatbox/files/10462079/top2.zip)

Changes:
1. The case is only risen by 2mm instead of 3mm. Don't like the feel of 3mm, and that I can't slide across the buttons without my finger catching the edge of the button hole. And, judging by how other people's flatboxes (with v1 switch) look, I think this should be more or less optimal without buttons sticking out too much. I still have no idea how tall buttons "should" be above the case. Regardless, this can be easily adjusted.
2. Through the magic of the druids, I covered up old USB-C cutout and recreated it a bit higher. Since it's only higher by the same 2mm, it should cover the USB-C just fine, like before, without getting in the way or leaving a hole:
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
3. Slightly adjusted the paddings for button holes, increased it not by much (around ~0.05mm), just halved the difference between button radius and the hole radius. Didn't like how close the tolerance turned out with the PETG. Again, should be easy to adjust if needed.

(On that topic, I find the keys somewhat small for my larger fingers. If anyone knows where to buy larger, proper 24 and 30mm keys, on Ali or in Europe, please let me know. Yes, printing them is an option, but I like the quality of manufactured buttons)

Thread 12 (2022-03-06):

What is the pcb size for the rev 4?

suyash691, 2022-03-06:
The printing service I am using is asking for PCB size (dimensions) but it isn't listed anywhere on the repo

jfedor2, 2022-03-06:
The dimensions are 210x124.5mm.

suyash691, 2022-03-07:
Thanks!

Closed 2022-03-07.

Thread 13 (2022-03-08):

PCB design alternatives?

PutPasswordHere, 2022-03-08:
Don't have much experience with PCB design. I've been checking JLCPCB the past couple months, and a couple parts have been out of stock. Would it be possible to replace some of the parts with alternatives? Would it require a new gerber file?
(this is specifically for rev4)
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

jfedor2, 2022-04-11:
If it's a part in a standard package like the resistor (or even the voltage regulator) then you can search JLCPCB inventory for a replacement with the same package and specs. For common parts it shouldn't be a problem and you can use the same Gerber files. If it's the RP2040 or the USB connector that's out of stock then I'm afraid the only option is to wait until it's in stock again.

PutPasswordHere, 2022-04-11:
Appreciate the response. Wasn't sure how lenient some of the parts could be (probably something I could have researched more myself, sorry). Was able to find a time when everything was in stock and snagged them. Thanks for the designs and effort.

Closed 2022-11-10.

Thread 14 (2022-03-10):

Any chance for a Rev5 with Brook Zero PI Fighting Board

tdpssn, 2022-03-10:
It's a little cheaper to source than the Brook PS4/PS3 board and more current, though would take some work on the PCB design

jfedor2, 2022-03-11:
From what I can see that board is PC/PS3/Switch only? Also quite large.

MukiEX, 2022-09-22:
Yeah, the Fighting Zero board is better for assembling a full fightstick, as it's an easy manual setup with screw-in terminals. Kind of a moot point if you already have one with an Arduino or RP2040 option available.

Conceivably, one potential runner would be a LOLIN32 variant w/ a tiny LiPo battery for a wireless Switch/PC version.

Closed 2022-11-10.

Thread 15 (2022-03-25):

3D Printing Question

LuminarySC, 2022-03-25:
Hi,

Just a quick question about 3D printing the case. Did you opt for 100% infil on the print or did you find a lower infill % was good enough?

Many thanks,

Lumi

jfedor2, 2022-03-25:
Hi,

High infill is not necessary. I used whatever the default was in my slicer profile (15% I think).

LuminarySC, 2022-03-25:
Hi that's great, thank you very much. Can't wait to get this all set up

Closed 2022-03-25.

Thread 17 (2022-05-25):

Won't Detect or Power After Firmware Flash and Unplug

ktrieun, 2022-05-25:
### Expected Behavior:
After flashing the firmware, I should be able to unplug the controller and have the controller be detected once it is plugged in again.

### Actual Behavior:
It initially detects the controller immediately after flashing the firmware according to the instructions. Once device is unplugged form PC, Flatbox is not detected by computer.

### Steps to Reproduce the Problem:
1. Plug USB into Flatbox PCB and PC
2. Press the RESET switch while holding down the BOOT switch
3. Mount and open "RPI-RP2"
4. Copy "flatbox-rev4.uf2" to "RPI-RP2"
5. Unplug controller from PC
6. Plug controller back into PC

### Specifications
Version: Flatbox Rev4
Platform: Windows 10 21H2 & EndeavourOS

jfedor2, 2022-05-25:
Perhaps an issue with the flash chip on your board?

ktrieun, 2022-05-25:
I believe this might be the issue. I've gotten 2 out of the 5 board to work and am waiting on parts to replace.

Closed 2022-07-28.

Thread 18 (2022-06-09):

About the choice of switch

swhan111, 2022-06-09:
hello.
Thanks to your work, I am having fun making controllers.
I have a question about the choice of switch.
Please forgive me for my lack of knowledge about PCB.
1. Can I use Kailh Low Profile Backlight Switch on your PCB?
2. If 1 is possible, does the LED work normally?

Wait for your reply.
thank you

jfedor2, 2022-06-09:
Do you have a link for the switch you have in mind?

In any case, this PCB has no support for LEDs so that's unlikely to work.

swhan111, 2022-06-09:
Thank you so much for your quick reply.

https://www.aliexpress.com/item/4000419542482.html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

I purchased "choc red" from the products in the link above.
And I think this shouldn't be a problem.

However, I have one more question.
First of all, I don't know much about PCBs.
I have nevertheless completed my order with JLCPCB according to your
detailed description, but I have a question about an unresolved issue while
talking to JLCPCB today.

JLCPCB has sent me an email with the following contents.

================
Hi Sir or madam,
Well got your order with many thanks.
Sorry to bother you, but there is one thing that we want to confirm with
you about your SMT order before proceeding.
Since we are not so sure about the polarities of the components are correct
or not. Could you please kindly check if the polarities and placements of
the components are correct in the below picture? Is it okay to proceed with
production?
Your early reply will be highly appreciated, thank you so much!
================

JLCPCB sent the image I attached along with the above e-mail content.
When you check the image sent by JLCPCB, please check whether it is
configured correctly in terms of "polarity" and "placement".

Thanks again for your reply.

2022년 6월 9일 (목) 오후 8:29, Jacek Fedoryński ***@***.***>님이 작성:

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

jfedor2, 2022-06-09:
The switch should work fine (again, no LED).

As for JLCPCB, I didn't have this issue when I ordered my PCBs, they just fixed the orientations and placement of the components on their side without consulting with me. (It's a necessary step because JLCPCB uses a different convention for their parts library than KiCAD.)

I'm not seeing the image you attached, perhaps post it via GitHub's web interface instead of email.

swhan111, 2022-06-09:
I will upload the image through GitHub's web interface. I ask for your confirmation.
thank yo
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
u

jfedor2, 2022-06-09:
Orientation of U3 looks wrong, pin 1 (red dot) should be top-left.

The rest looks OK I think.

swhan111, 2022-06-10:
Sorry, but I want to ask you one more question.

Are cherry MX switches completely incompatible with current PCB layouts?

If it is not possible to use cherry MX switches in your PCB layout, is it okay if I try to modify your work so that the cherry MX switches are compatible?

thank you

jfedor2, 2022-06-10:
They're incompatible, the footprint of the switch is different.

And sure, go ahead, that's why I provide the files!

Closed 2022-06-10.

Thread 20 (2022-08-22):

More of a question

jh0nny2k, 2022-08-22:
How snug is the PCB inside the case? I would like to use your 1.1 design, but with an Arduino pro micro with USB C. This one is 1 mm taller than the micro b connector one.

Do you think it would fit?

Thanks for the great design files, really love your work.

jfedor2, 2022-08-23:
Vertical space above the (Flatbox) PCB is 4 mm. I'd try it, worst case scenario you will have to make the cutout bigger with a file or something.

jh0nny2k, 2022-08-23:
Thank you. Appreciate the reply. One last question. How slow is the arduino? Is it that slow compared to the other 2? I want to pick this option because it is the cheapest. The board asembly is 45 euros plus 15 euros the boards. Just the boards is 15 euros.

Am i trading that much?

jh0nny2k, 2022-08-23:
i was looking trough your design for the rev 4 :) you must have a big brain:))) you must be really smart. the design is so great. congrats dude, this is some piece of art.

jfedor2, 2022-08-24:
I'm not sure if I ever tested input lag on the Pro Micro version. I'd have to check. In any case, if you want the verified as-good-as-it-gets latency of the RP2040 version, but keep the cost down, you could probably use the rev1.1 PCB with an RP2040-based board that has a Pro Micro-compatible shape. Both Adafruit and SparkFun make one, probably others as well:

https://www.adafruit.com/product/5302

https://www.sparkfun.com/products/18288

I haven't tested this, but I think it should work. You'd probably have to reconfigure the pin numbers in the firmware, but if you use GP2040 you can do that without recompiling anything.

I'm currently considering a variant that would use an RP2040-Zero board (as suggested in #8), which should also be a cheap option.

jh0nny2k, 2022-08-24:
Thank you for the advices. Really appreciate it. I'll give it a try. See how it fits

jh0nny2k, 2022-08-31:
If i may ask, are the buttons 24's and 30 for the jump? I found a shop in Spain selling buttons for kaihl's 11 24's and one 30 for 8 euro. That is mighty cheap. Cheaper than jlcpcb

jfedor2, 2022-08-31:
Yeah, the small ones are 24 and the big one is 30.

Can you post a link to the store?

When ordering on JLCPCB it would probably be better to combine all buttons into one model. I haven't tried but I've seen people do it.

jh0nny2k, 2022-08-31:
https://karboxarcade.com/products/karbox-button-keycaps-set?variant=43003221770479 take a look

jfedor2, 2022-08-31:
As far as I can tell these should work great. Their controller uses the same type of switches.

Closed 2022-11-10.

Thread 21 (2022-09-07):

Just a question

Blkcofkaiju, 2022-09-07:
Just wondering if you'd do a noir style for the button layout? Or would changing the pcb be a hassle?
Sorry if it's a silly question

jfedor2, 2022-09-07:
It's enough of a hassle that I won't do it for you, but all the necessary files are available if you want to attempt it yourself. It would be a matter of dragging some footprints in KiCad to get the layout you want and modifying the case models so that the holes are in the right places.

Blkcofkaiju, 2022-09-07:
Ill give it a go :) thanks for the quick response!
Appreciate your design here, looks really nifty

Soundtoxin, 2023-02-19:
@Blkcofkaiju
> Ill give it a go :) thanks for the quick response! Appreciate your design here, looks really nifty

Did you ever make this change? I would be interested for future builds. (I have already built 10 of the current Flatbox rev5)

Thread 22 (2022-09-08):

Quick Question Regarding Resistors

piuzera, 2022-09-08:
Greetings!

First of all, thank you for this great project. I recently ordered 5 units from JLCPCB and unfortunately, they seem to be missing the R3 and R4 resistors. I can't power up and flash the memory because of this, most likely. I wish the reason is this, otherwise I just lost a ton of money :(

Below is an image of the PCB:

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

Can you enlighten me on what resistor to buy for these slots? I will solder them myself to save the PCBs.

Thanks in advance!

jfedor2, 2022-09-08:
My guess is that it won't make a difference.

Closed 2022-09-08.

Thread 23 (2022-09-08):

flat box rev4 not detected as controller after firmware loaded

SudoKelvi, 2022-09-08:
After loading firmware onto the rev4 flatbox, it simply loops back to opening as RPI-RP2 rather than being detected as a controller.

So to reproduce:

1. Connect rev4 via USB
2. Bolt boot + reset
3. Copy pre-compiled firmware to RPI-RP2
4. Windows unmounts and remounts RPI-RP2
5. Disconnect and reconnect simply re-mounts RPI-RP2 rather than being detected as a controller

Another bizarre thing is that I dont actually need to hold boot and reset, it always just opens RPI-RP2 by default?

jfedor2, 2022-09-09:
Maybe something wrong with the flash chip? Or I guess it would also behave like that if the BOOT button was stuck in the pressed position or shorted somehow, but it seems less likely. Do you have another board to see if it acts the same?

SudoKelvi, 2022-09-09:
I checked the boot and reset buttons and they seem good? Basically did a simple continuity check and I only get a beep when the button was pressed. I'll check other boards and see what might be up.

SudoKelvi, 2022-10-09:
Okay, so it was definitely the board. Trying another and it worked so I'll figure it out later.

If I can pivot to a new problem: using the latest firmware, sw2 doesn't seem to work? Using a continuity tester, the switch works, and when pressed I get a signal from ground to the RP2040. I think the input is not being used in firmware?

jfedor2, 2022-10-10:
> If I can pivot to a new problem: using the latest firmware, sw2 doesn't seem to work? Using a continuity tester, the switch works, and when pressed I get a signal from ground to the RP2040. I think the input is not being used in firmware?

Yeah, I guess I ran out of ideas for what to map that button to so it's unused in the default firmware.

But it's connected to the RP2040 so it's usable if you flash some other firmware.

Closed 2022-11-10.

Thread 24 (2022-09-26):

Soldering PCB of rev3

JarTheHead, 2022-09-26:
I saw that you need to directly solder the Brook pcb. Will using connecting pins interfere with the case?

jfedor2, 2022-09-26:
Use pins, but without the plastic spacer thing between the boards. The Brook board has to sit directly on the Flatbox PCB or it will not fit in the case.

Closed 2022-11-10.

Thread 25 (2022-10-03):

Flatbox detected, buttons presses not registering

MorroMorro, 2022-10-03:
Hi J,

Put a switch on the board to test.  I added the firmware just fine. Windows is detecting it as flatbox rev4.

Was detecting the button press just fine and then suddenly stopped. Now I've tried 3 boards, 5-6 switches, and non register the button presses. It was working then all of a sudden stopped, so I don't think it's a hardware issue. Any ideas I can try to troubleshoot this issue?

When I pull up the controller as a drive, should the uf2 file still be there? When I add it, it closes the drive. If I reopen it and it's no longer present. Not sure if that's as intended.

jfedor2, 2022-10-04:
Yeah, the UF2 file copying works as you described, that's normal.

Are you testing the buttons in joy.cpl?

Have you tried alternative firmware like GP2040?

MorroMorro, 2022-10-04:
Morning J. Yeah, I've been testing in joy.cpl. Flatbox looks amazing btw.

Will try alternate firmware and report back. For GP2040, hate to bother but I'm terrible at this stuff, do I just drop all the files and src folder from https://github.com/jfedor2/flatbox/tree/master/firmware-rp2040 onto the controller "drive"?

MorroMorro, 2022-10-04:
No issue at all. I'm just bad at applying switches. J is a hero.

jfedor2, 2022-10-04:
Glad to hear you got it working.

For future reference, the alternative GP2040 firmware can be downloaded from here:

https://github.com/FeralAI/GP2040/releases/download/v0.4.3/GP2040-FlatboxRev4_v0.4.3.uf2

And then you flash it the same way.

Let me know when you make the video!

Closed 2022-10-04.

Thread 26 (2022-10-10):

start button not getting detected rev1.1

jh0nny2k, 2022-10-10:
Hi,

I have soldered 2 pcb's and on both of them the start buttons is not getting detected. Being that anyway i have to configure these in steam i just skipped the button in the configuration process. The button presses are also not registered on the micro itself. for all other buttons the led flashes for the start button there is no flash.

Thing is i connected the button directly to the pin (ran a wire) and it still didn't register, Wich is weird. Any suggestions?

Side question, can't the micro be coded to be detected as a 360 controller by windows?

Kind regards

jfedor2, 2022-10-12:
I don't really have any ideas. Does this happen on two different Pro Micros? Do the other pins work as they should? Do you have "Pro Micro" selected in the boards menu?

As for emulating a 360 controller, there are firmwares that run on a Pro Micro and support XInput. I haven't tried them, but here's an example: https://github.com/fluffymadness/ATMega32U4-XINPUT-Fightstick

jh0nny2k, 2022-10-12:
/*
 *  Project     Arduino XInput Library
 *  @author     David Madison
 *  @link       github.com/dmadison/ArduinoXInput
 *  @license    MIT - Copyright (c) 2019 David Madison
 *
 * Permission is hereby granted, free of charge, to any person obtaining a copy
 * of this software and associated documentation files (the "Software"), to deal
 * in the Software without restriction, including without limitation the rights
 * to use, copy, modify, merge, publish, distribute, sublicense, and/or sell
 * copies of the Software, and to permit persons to whom the Software is
 * furnished to do so, subject to the following conditions:
 *
 * The above copyright notice and this permission notice shall be included in
 * all copies or substantial portions of the Software.
 *
 * THE SOFTWARE IS PROVIDED "AS IS", WITHOUT WARRANTY OF ANY KIND, EXPRESS OR
 * IMPLIED, INCLUDING BUT NOT LIMITED TO THE WARRANTIES OF MERCHANTABILITY,
 * FITNESS FOR A PARTICULAR PURPOSE AND NONINFRINGEMENT. IN NO EVENT SHALL THE
 * AUTHORS OR COPYRIGHT HOLDERS BE LIABLE FOR ANY CLAIM, DAMAGES OR OTHER
 * LIABILITY, WHETHER IN AN ACTION OF CONTRACT, TORT OR OTHERWISE, ARISING FROM,
 * OUT OF OR IN CONNECTION WITH THE SOFTWARE OR THE USE OR OTHER DEALINGS IN
 * THE SOFTWARE.
 *
 *  Example:      GamepadPins
 *  Description:  Uses all of the available pin inputs to build a 'complete'
 *                Xbox gamepad, with both analog joysticks, both triggers,
 *                and all of the main buttons.
 *
 *                * Joysticks should be your typical 10k dual potentiometers.
 *                  To prevent random values caused by floating inputs,
                    joysticks are disabled by default.
 *                * Triggers can be either analog (pots) or digital (buttons).
 *                  Set the 'TriggerButtons' variable to change between the two.
 *                * Buttons use the internal pull-ups and should be connected
 *                  directly to ground.
 *
 *                These pins are designed around the Leonardo's layout. You
 *                may need to change the pin numbers if you're using a
 *                different board type
 *
 */

#include <XInput.h>

// Setup
const boolean UseLeftJoystick   = false;  // set to true to enable left joystick
const boolean InvertLeftYAxis   = false;  // set to true to use inverted left joy Y

const boolean UseRightJoystick  = false;  // set to true to enable right joystick
const boolean InvertRightYAxis  = false;  // set to true to use inverted right joy Y

const boolean UseTriggerButtons = true;   // set to false if using analog triggers

const int ADC_Max = 1023;  // 10 bit

// Joystick Pins
const int Pin_LeftJoyX  = 0;
const int Pin_LeftJoyY  = 0;
const int Pin_RightJoyX = 1;
const int Pin_RightJoyY = 1;

// Trigger Pins
const int Pin_TriggerL = A2;
const int Pin_TriggerR = A0;

// Button Pins
const int Pin_ButtonA = 10;
const int Pin_ButtonB = 14;
const int Pin_ButtonX = 16;
const int Pin_ButtonY = 15;

const int Pin_ButtonLB = A3;
const int Pin_ButtonRB = A1;

const int Pin_ButtonBack  = 2;
const int Pin_ButtonStart = 3;

const int Pin_ButtonL3 = 4;
const int Pin_ButtonR3 = 5;

// Directional Pad Pins
const int Pin_DpadUp    = 9;
const int Pin_DpadDown  = 7;
const int Pin_DpadLeft  = 6;
const int Pin_DpadRight = 8;

void setup() {
	// If using buttons for the triggers, use internal pull-up resistors
	if (UseTriggerButtons == true) {
		pinMode(Pin_TriggerL, INPUT_PULLUP);
		pinMode(Pin_TriggerR, INPUT_PULLUP);
	}
	// If using potentiometers for the triggers, set range
	else {
		XInput.setTriggerRange(0, ADC_Max);
	}

	// Set buttons as inputs, using internal pull-up resistors
	pinMode(Pin_ButtonA, INPUT_PULLUP);
	pinMode(Pin_ButtonB, INPUT_PULLUP);
	pinMode(Pin_ButtonX, INPUT_PULLUP);
	pinMode(Pin_ButtonY, INPUT_PULLUP);

	pinMode(Pin_ButtonLB, INPUT_PULLUP);
	pinMode(Pin_ButtonRB, INPUT_PULLUP);

	pinMode(Pin_ButtonBack, INPUT_PULLUP);
	pinMode(Pin_ButtonStart, INPUT_PULLUP);

	pinMode(Pin_ButtonL3, INPUT_PULLUP);
	pinMode(Pin_ButtonR3, INPUT_PULLUP);

	pinMode(Pin_DpadUp, INPUT_PULLUP);
	pinMode(Pin_DpadDown, INPUT_PULLUP);
	pinMode(Pin_DpadLeft, INPUT_PULLUP);
	pinMode(Pin_DpadRight, INPUT_PULLUP);

	XInput.setJoystickRange(0, ADC_Max);  // Set joystick range to the ADC
	XInput.setAutoSend(false);  // Wait for all controls before sending

	XInput.begin();
}

void loop() {
	// Read pin values and store in variables
	// (Note the "!" to invert the state, because LOW = pressed)
	boolean buttonA = !digitalRead(Pin_ButtonA);
	boolean buttonB = !digitalRead(Pin_ButtonB);
	boolean buttonX = !digitalRead(Pin_ButtonX);
	boolean buttonY = !digitalRead(Pin_ButtonY);

	boolean buttonLB = !digitalRead(Pin_ButtonLB);
	boolean buttonRB = !digitalRead(Pin_ButtonRB);

	boolean buttonBack  = !digitalRead(Pin_ButtonBack);
	boolean buttonStart = !digitalRead(Pin_ButtonStart);

	boolean buttonL3 = !digitalRead(Pin_ButtonL3);
	boolean buttonR3 = !digitalRead(Pin_ButtonR3);

	boolean dpadUp    = !digitalRead(Pin_DpadUp);
	boolean dpadDown  = !digitalRead(Pin_DpadDown);
	boolean dpadLeft  = !digitalRead(Pin_DpadLeft);
	boolean dpadRight = !digitalRead(Pin_DpadRight);

	// Set XInput buttons
	XInput.setButton(BUTTON_A, buttonA);
	XInput.setButton(BUTTON_B, buttonB);
	XInput.setButton(BUTTON_X, buttonX);
	XInput.setButton(BUTTON_Y, buttonY);

	XInput.setButton(BUTTON_LB, buttonLB);
	XInput.setButton(BUTTON_RB, buttonRB);

	XInput.setButton(BUTTON_BACK, buttonBack);
	XInput.setButton(BUTTON_START, buttonStart);

	XInput.setButton(BUTTON_L3, buttonL3);
	XInput.setButton(BUTTON_R3, buttonR3);

	// Set XInput DPAD values
	XInput.setDpad(dpadUp, dpadDown, dpadLeft, dpadRight);

	// Set XInput trigger values
	if (UseTriggerButtons == true) {
		// Read trigger buttons
		boolean triggerLeft  = !digitalRead(Pin_TriggerL);
		boolean triggerRight = !digitalRead(Pin_TriggerR);

		// Set the triggers as if they were buttons
		XInput.setButton(TRIGGER_LEFT, triggerLeft);
		XInput.setButton(TRIGGER_RIGHT, triggerRight);
	}
	else {
		// Read trigger potentiometer values
		int triggerLeft  = analogRead(Pin_TriggerL);
		int triggerRight = analogRead(Pin_TriggerR);

		// Set the trigger values as analog
		XInput.setTrigger(TRIGGER_LEFT, triggerLeft);
		XInput.setTrigger(TRIGGER_RIGHT, triggerRight);
	}

	// Set left joystick
	if (UseLeftJoystick == true) {
		int leftJoyX = analogRead(Pin_LeftJoyX);
		int leftJoyY = analogRead(Pin_LeftJoyY);

		// White lie here... most generic joysticks are typically
		// inverted by default. If the "Invert" variable is false
		// then we'll take the opposite value with 'not' (!).
		boolean invert = !InvertLeftYAxis;

		XInput.setJoystickX(JOY_LEFT, leftJoyX);
		XInput.setJoystickY(JOY_LEFT, leftJoyY, invert);
	}

	// Set right joystick
	if (UseRightJoystick == true) {
		int rightJoyX = analogRead(Pin_RightJoyX);
		int rightJoyY = analogRead(Pin_RightJoyY);

		boolean invert = !InvertRightYAxis;

		XInput.setJoystickX(JOY_RIGHT, rightJoyX);
		XInput.setJoystickY(JOY_RIGHT, rightJoyY, invert);
	}

	// Send control data to the computer
	XInput.send();
}

jh0nny2k, 2022-10-12:
I modified the above to make it work. Till now it works okey, no complaints. i just lost the pin 0 and 1 buttons, not sure what i could possibly map on them. plus not sure how to map the Xbox button as i just modified the pins in the above programing :)

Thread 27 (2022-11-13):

Question regarding flash chip alternatives

piuzera, 2022-11-13:
Greetings!

I recently ordered a new batch of PCBs and it seems like the flash chip of two of them are having issues. I can flash the software included in the repo and everything works properly but once I unplug and replug, the controller is no longer recognized.

I suspect this is because of a faulty flash chip. Are there any alternatives for the "Winbond Elec W25Q128JVSIQ"? This part is not available in my country and importing it would be very expensive.

Thanks!

jfedor2, 2022-11-13:
I don't want to give a recommendation that I didn't test personally, but in general you need a Quad SPI, XIP, 3.3V part (in the same package, obviously). GigaDevice GD25Q128ES* maybe? It doesn't have to be 16 MB. The Pico only has 2 MB.

But based on your symptoms the flash chip seems to work, but maybe not 100% right. Even immediately after you flash it, it's already running from flash, it's just that it doesn't go through the normal bootloader in that scenario. At least that's how I understand it. You might try recompiling the firmware, changing some parameters. Some more info here:

https://forums.raspberrypi.com/viewtopic.php?p=1874492&sid=cdb260577d9bb4485fe8c3cebe2c94fa#p1874492

piuzera, 2022-11-14:
Thank you for your help! I'll try out different flashing methods to see if there's any change. Hopefully I don't have to order new parts.

jfedor2, 2022-11-18:
Some other folks asked me about the same issue, it seems to be more widespread.

You can try flashing this firmware and see if it helps.

[flatbox-rev4-flashtest.zip](https://github.com/jfedor2/flatbox/files/10043833/flatbox-rev4-flashtest.zip)

piuzera, 2022-11-18:
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

Indeed, this file is working properly, the flatbox is surviving the power cycle. What kind of changes did you make to it? I'd like to test it on GP2040 too, I customized some settings from it and I'd like to fix it too.

jfedor2, 2022-11-19:
I will push the changes when I have some time, but I just followed advice from that forum thread and compiled it with the following settings in a board file:

```
// On some samples, the xosc can take longer to stabilize than is usual
#ifndef PICO_XOSC_STARTUP_DELAY_MULTIPLIER
#define PICO_XOSC_STARTUP_DELAY_MULTIPLIER 64
#endif

// Use slower generic flash access
#define PICO_BOOT_STAGE2_CHOOSE_GENERIC_03H 1

#ifndef PICO_FLASH_SPI_CLKDIV
#define PICO_FLASH_SPI_CLKDIV 4
#endif

#ifndef PICO_FLASH_SIZE_BYTES
#define PICO_FLASH_SIZE_BYTES (2 * 1024 * 1024)
#endif

// All boards have B1 RP2040
#ifndef PICO_RP2040_B0_SUPPORTED
#define PICO_RP2040_B0_SUPPORTED 0
#endif
```

(It's likely one of the first three, or a combination of them.)

jfedor2, 2022-11-23:
After some more testing by other users I now think it's the crystal oscillator part that's problematic, not the flash chip. The latest firmware has a workaround for that (PICO_XOSC_STARTUP_DELAY_MULTIPLIER 64, as mentioned above).

piuzera, 2022-11-29:
Thanks! It now works flawlessly. I'll be closing the issue.

Closed 2022-11-29.

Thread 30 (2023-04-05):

2040 Zero firmware issues

skadoodlee, 2023-04-05:
I want to install 2040zero on the PCB in reverse, with the type-c interface facing downwards, which can save some space and make it thinner. But I can't write firmware, I can only wrap the wire around the PCB once. I hope you can share a new firmware for 2040 zero, which can be installed backwards on the PCB. Thank you.

skadoodlee, 2023-04-05:
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

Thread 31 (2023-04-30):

Flatbox-rev5-kicad.zip cannot be loaded

SonicZH, 2023-04-30:
The Kicad zip file cannot be processed by easyeda, just wondering if it is an issue for this particular software only

jfedor2, 2023-04-30:
It works with rev4 files so I'm guessing EasyEDA doesn't support KiCad 6+.

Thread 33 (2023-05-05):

Replaced button won't work

jahmal995, 2023-05-05:
One of my buttons snapped off so I replaced it with another free button. Clicked right in and doesn't register at all. Each other button is still fine. Can some one help?

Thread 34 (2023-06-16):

boot and reset switches are missing from .step file [Rev4]

oct2pus, 2023-06-16:
i was making a custom case for the flatbox and noticed after i had printed the first prototype that I failed to factor in the reset and boot switches, i then noticed that they were missing from the included step file as well.

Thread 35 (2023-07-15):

how to get to web loader and Switch 2 Rev 5

JBones866, 2023-07-15:
What button is it to hold down to enter the web configurator on this pin out ?

Also have built 2 separate boards now and it doesnt seem like I get any response from SW2 is this normal, what is the default setup for this switch ?

Thanks !

jfedor2, 2023-07-15:
The firmware in this repository is not GP2040. There is no webconfig. And yeah, SW2 does nothing by default.

If you want GP2040-CE, flash this firmware and then hold the first button from the left in the top row when plugging in to enter webconfig:

https://github.com/OpenStickCommunity/GP2040-CE/releases/download/v0.7.2/GP2040-CE_0.7.2_FlatboxRev5.uf2

JBones866, 2023-07-15:
Thanks, was going crazy trying to trouble sw2 !

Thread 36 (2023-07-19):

Improve tactile button layout

Soundtoxin, 2023-07-19:
I think there is room for improvement in how the tactile buttons are laid out. Something to differentiate every other key by touch would help (sorta like how piano keys have some separation by the black keys).
I was thinking something like an added texture or height difference in the case above them (maybe a line or a dome like homing keys on keyboards). It may also help to put some space between the first three and last three on the PCB so you can feel a gap and know where you are.
I've been playing a lot of PC games with my Flatbox rev 5 the last few weeks and the third button from the left is used for the Steam button on the Steam Deck, which is pretty important (accept game invite, join someone's game manually, quit game, etc.). It's very difficult to find quickly and hit blindly. I often second-guess myself and go back and slowly feel out the buttons one by one trying to make sure I'm on the third one.
If anyone has done some sort of mod to theirs to help with telling apart the buttons, I'd be interested in hearing about that as well.  Maybe I could stick something textured on some of my buttons, like a small piece of sandpaper or grip tape.
I'd say besides the keycaps breaking, this is probably the biggest weakness of the Flatbox I've noticed.
I also find that these buttons are a bit hard to press. I was playing Hammerwatch, where the map is on the Select button by default and is something you need to reference pretty often, and I found it somewhat slow/exhausting to keep pressing Select. I did finally just end up shifting my bindings around and finding a spot for the map on one of the main buttons instead as a workaround. I'm not sure if the main source of the difficulty in actuation is from the inner button itself or the way the case flexes to press the button. I'm using Choc Silvers for my main buttons on the Flatbox, but I'm also used to typing on a keyboard with Kailh Box Navy switches which are fairly heavy but still much easier to press than these tactile buttons.

jfedor2, 2023-07-19:
Yeah, that's a valid point.

You can always remap the button so the one you need is easier to find.

There are also versions of the case where the buttons stick out. Check out the OpenStickCommunity Discord.

Soundtoxin, 2023-07-19:
I don't use Discord. Do you know if any of those cases are available publicly elsewhere? GitHub, Thingiverse, Printables, etc.? For now I'll probably see what sort of small mod I can do rather than print a whole new top to try and fix it, but if I ever built another batch of 5 or 10, I'd hopefully have a better solution by then.

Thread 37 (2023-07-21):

New Rev5 Oled and RGB

mytokat84, 2023-07-21:
I m using raspberry pi pico and gp2040-ce in my arcadestick. I didnt use any capasitor and resistor on it. Connected oled screen to SDA, SCL and +3v on pico. It worked well. I connected ws2812 led strip same way pin 28 for data, GND and 5v.  There was 100 nf capasitors on led strip and it works very well for 1 years. So, For these reasons, I will not use 4.7k capacitors, 330k capacitors and logic level shifters in my circuit. I tested and took very well results for 1 years.

I made hitbox before just with oled screen. Now, I want to make a fork from flatbox rev5 with rgb and oled. I made its schematics and pcb via kicad7 and I m taking so much errors when I check PCB from DRC.

Can anyone help me about fixing that PCB's wiring and footprints or can anyone make REV5 RGB and Oled.

Thank you in advance.

Note: I cancelled L3 and R3 for oled screen SDA and SCL pins.

Closed 2023-07-27.

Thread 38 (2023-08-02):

Question: Is the PCB needed?

HCury, 2023-08-02:
I remember seeing your first itteration was just a Arduino. Do I need the PCB? Can I just solder directly into the arduino? Is there a way to make the arduino work with the ps5?

jfedor2, 2023-08-02:
This project _is_ the PCB. You can make a Slimbox instead if you want.

There is no way to make an Arduino work with the PS5 that I know of. Apart from using an external adapter.

Closed 2023-08-02.

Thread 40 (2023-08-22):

Rev3 PCB Pin Header Sizes Not Listed

Styggy, 2023-08-22:
Hi, I've tried my best to find which pins are appropriate for soldering as the standard pins I'd use for an Arduino don't want to fit into the Rev3 board and it's not listed anywhere in the documentation.

I'm assuming a 2.5mm pitch with a .5mm pin would be small enough but I just want to be sure before I proceed, thank you. The standard size pins fit the brook PCB but not the custom PCB itself.

jfedor2, 2023-08-22:
Pitch is 2.0mm. When you say the pins don't fit the PCB, do you mean that a single pin won't go through the hole? I think the ones I used were 0.5mm.

Styggy, 2023-08-22:
Yeah they won't go through, that's what I needed though, thanks for the quick response.

Closed 2023-08-22.

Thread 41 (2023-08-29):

Where is the circular button file

dron-one, 2023-08-29:
I can't find the 3D file of the button, only the shell, I am Xiao Bai, please tell me how to get this. Did you refer to the file again?

marcelo-franceschini, 2023-08-29:
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

Did you take a look at the project's root folder?

marcelo-franceschini, 2023-08-29:
Did you take a look at the project's root folder?

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

dron-one, 2023-08-29:
谢谢您。但是按钮是两个脚的，我们按钮接口不是圆形十字的吗，接不上

dron-one, 2023-08-29:
Thank you very much. But the button is two feet, our button interface is not round cross, can not connect

marcelo-franceschini, 2023-08-29:
Two feet?
Our button?
Are you using a translator to convert from an Asian language to English?

dron-one, 2023-08-29:
This button requires a specific mechanical shaft to work。

dron-one, 2023-08-29:
If you want to use a hot-swappable mechanical shaft, which make and model can be used?

marcelo-franceschini, 2023-08-29:
The buttons would be the same model. You would change only the bottom piece.

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

dron-one, 2023-08-29:
Got it. Thank you

marcelo-franceschini, 2023-08-29:
> Got it. Thank you

You're welcome! Could you please close this issue? Thanks

dron-one, 2023-08-29:
okThank you

Closed 2023-08-29.

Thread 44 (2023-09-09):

Switches don't fit

SquidRadio, 2023-09-09:
In the instructions, one of the parts listed are "12x Kailh low profile (choc v1) switches of your choice", but when I place the switches to the board, the center piece on the switch is too large to fit within the PCB, which prevents the switches from being solderable or fitting properly in the flatbox at all.

I am using the CPG135301D01 v1 switches with the cross-hatch port, rather than the v2 with the two-prong port. I have the rev4 version of the PCBs.

Is there something I am missing? A visual guide would be helpful as well for newcomers to the project.

jfedor2, 2023-09-09:
You have v2 switches.

SquidRadio, 2023-09-09:
And the v2 switches won't work. Makes sense.

Is there a switch that you recommend? I am new to this sort of project and don't want to end up buying the wrong thing again, as the label on Amazon did say v1 switches, and the listing doesn't have a link to any specific set.

JarTheHead, 2023-09-10:
> Is there a switch that you recommend?

I personally use the Choc V1 crystal red switches (normal red is basically the same). I got them from [Aliexpress](https://www.aliexpress.us/item/3256805260407528.html). There doesn't seem to be any Amazon fulfilled ones.

Closed 2023-09-09.

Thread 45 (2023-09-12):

Case top heat-set inserts don't fit

StellaTerra, 2023-09-12:
The model for the case top has 2.8mm diameter openings for the screws.
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
The instructions call for M3 screws, which have a diameter of 3.0mm. The instructions don't yet call for heat-set inserts, but following this video, I thought they would be appropriate: https://youtu.be/mK5Ez4Nguuw?si=9YgIthzJSPQkv2V7&t=352
When the inserts arrived, and I tried to heat-set them into the case top, and it mangled the print pretty bad. Looking back at the video, it looks like there is a wider area within the hole, and then a narrower area below, which is not present in the STL. In doing some research, it looks like they start at 3.5mm outer diameter and get bigger from there. I don't think these will ever fit well in a 2.8mm hole, no matter how well printed. After a while I put a screw into one of the inserts and jammed it in with a soldering iron, but I don't think the holes are going to line up well with the bottom anymore.
Can I get some clarification on the instructions, are you expecting the use of heat-set inserts? Is the M3 a typo, and we're supposed to be using M2 screws? Do you recommend drilling out the screw holes so that the inserts fit better? Is there a possibility the STL was supposed to have printed threading that is missing?

jfedor2, 2023-09-12:
The instructions don't call for heat inserts, there is no typo. Just drive the screw into the plastic. If the hole was 3mm, it wouldn't really hold a 3mm wide screw, would it?

JarTheHead, 2023-09-12:
> The instructions don't yet call for heat-set inserts, but following this video, I thought they would be appropriate: https://youtu.be/mK5Ez4Nguuw?si=9YgIthzJSPQkv2V7&t=352

The video you shared appears to be using an SGF Bridget case, a fork of the Flatbox that uses M2 Heatset inserts

StellaTerra, 2023-09-12:
Yes, my bad. Thank you for the clarification.

Closed 2023-09-12.

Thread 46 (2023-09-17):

Rev4 cnc files

kirkegaard, 2023-09-17:
Is there a chance that rev5 cnc files will work for rev4 boards, or could they be modified to fit rev4?

jfedor2, 2023-09-17:
They won't fit as is, but the difference between the 3D printable models and the CNC ones is small, it's only a different size of the screw holes and the aux buttons are round holes instead of the rectangular flaps. Probably better to start with rev4 files and modify those. Keep in mind the STEP files in the extras folder might be for the non-hotswap version.

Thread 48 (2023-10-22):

Button mapping for tact switches

TheGor1lla, 2023-10-22:
Just soldered my own flatbox and tested out all the buttons.  For the 6 switches I get from left to right: Start, Back, none, none, L3, R3

The soldering looks fine, but before I remove them I wanted to ask which buttons they are mapped to.

jfedor2, 2023-10-22:
In XInput mode one of the remaining buttons is Guide (Home) and the other is not mapped. In PS4 mode it's Touchpad.

TheGor1lla, 2023-10-22:
Home was blocked by my graphic cards software actions. Thanks for the answer!

Closed 2023-10-22.

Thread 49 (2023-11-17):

Trouble with rev5 files

ECkeys, 2023-11-17:
I don’t know if it’s just me but the cnc files for rev5 won’t upload to jlcpcb, says it’s not the right format.

Lookattheflowerz, 2023-12-25:
Need to rename the file

ShaneMraz, 2024-05-07:
Anyone having issues with jlcpdb not recognizing any files, do not download from GitHub through a browser.  Clone the repository and then upload any files for part building.

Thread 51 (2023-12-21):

Future plans: USB passthrough?

Soundtoxin, 2023-12-21:
Are there any plans yet for a rev 6? It seems like USB passthrough is a killer feature now, seen on some of the recent Haute42 leverless controllers. I haven't seen a DIY option with this yet and it seems important for PS5 and Xbox support going forward. I also think the little screens we're seeing on more controllers are quite useful for seeing what mode you're in and what some of your settings are. There's also the recent trend of including extra buttons like seen on the Haute42 M16. Both for an extra up button and for LS/RS or other buttons you may want to use for macros in games like SF6. The upcoming GP2040-CE release (RC out now) sounds like it's going to make button remapping a lot more powerful as well.
Changing switches to something that can take different keycaps (as discussed in another issue) also seems worth doing considering the common problem of printed choc v1 keycaps breaking off in switches.

Soundtoxin, 2025-09-10:
I believe newer revisions have the USB A port now. Closing.

Closed 2025-09-10.

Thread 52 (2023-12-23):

Key chatter / double-pressing problem on multiple Flatbox builds

Soundtoxin, 2023-12-23:
Have you run into erroneous double-presses on any Flatbox rev 5s you've built? What are some possible causes? To test, you can bind letters and such to keyboard mode keys in GP2040-CE and type in a text editor, or in xinput mode you can use something like Steam's virtual keyboard in the chat and see if you're getting multiple letters per press or if your dpad buttons move multiple places on the virtual keyboard.
I've run into this issue on at least two Flatboxes, I suspect all 10 I built have this issue but they're no longer all in my hands to test.
I do *not* have the issue on a Haute42 G16 from Aliexpress running the same firmware, or on an Open-Frame1 I built running HayBox firmware. The G16 and Frame1 have MX-style switches in common while the Flatbox uses chocs. Everything mentioned uses hotswap sockets.
The latest RC GP2040-CE firmware added a debounce setting in the web configurator that I played with a bit. Default is 5ms. If I crank it all the way up to 120ms it solves most of the chatter (I tried many lesser amounts along the way with less luck), but that's a ton of latency and shouldn't be necessary. I'm trying to track down what went wrong but there are so many variable.
One Flatbox I tested is using choc silvers and another is using choc whites.

Soundtoxin, 2023-12-23:
Someone I spoke with said that maybe the MCU (RP2040-Zero) is lacking the proper suppression to deal with USB noise.

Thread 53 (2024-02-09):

Question about LED's for the Choc switches.

ItsReLLiK, 2024-02-09:
Does the PCB support lighting? If so, what RGB LED's work with the low profile Choc switches?

jfedor2, 2024-02-09:
No, sorry.

ItsReLLiK, 2024-02-20:
Found the RGB version, closing this issue since it's irrelevant.

Closed 2024-02-20.

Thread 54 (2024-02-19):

Firmware not working

ItsReLLiK, 2024-02-19:
So, I downloaded the GP2040-CE firmware for the flatbox rev 5 and none of the keys function how they are supposed to at all. It looks like the pinout is the stock Waveshare RP2040 configuration. Do you have any suggestions or maybe an older working version for download?

jfedor2, 2024-02-19:
You probably flashed the RP2040-Zero firmware first, realized it's not the right one, then flashed the rev5 firmware. Unfortunately the way this works is that the Zero configuration survives the second flash. You can flash the flash_nuke.uf2 file then flash the rev5 firmware or reconfigure the pins manually in webconfig.

ItsReLLiK, 2024-02-19:
This worked, I did flash the other firmware first without even thinking about it.

For anyone else, after you flash nuke it, you have to unplug it and plug it back in or it won't take. I tried doing it without unplugging the board a couple times and was unsuccessful.

Closed 2024-02-19.

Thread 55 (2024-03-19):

Flipped layout?

Zyphyx, 2024-03-19:
Is the rev1.1 pcb designed such that I can flip the layout and solder the switches and buttons on the other side?

jfedor2, 2024-03-19:
I don't think so.

Zyphyx, 2024-03-19:
Do you have a layout where it's left handed instead? i.e. directionals on the right hand

jfedor2, 2024-03-19:
Not for rev1.1, but there's a version of rev5:

https://github.com/SkylaHila/flatbox-southpaw

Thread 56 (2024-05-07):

JLCPCB CPL Missing data

statikg11, 2024-05-07:
When uploading cpl file on JLCPCb error message below is generating. any solutions?

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

jfedor2, 2024-05-07:
These are the keyboard and tact switches, they're not assembled by JLCPCB, so just ignore it and continue.

(They shouldn't be in the BOM file in the first place.)

statikg11, 2024-05-08:
so what files should i drop here
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

jfedor2, 2024-05-08:
I just meant I shouldn't have included those entries in that file. Use the same files and just click "continue".

statikg11, 2024-05-08:
Ok so use the cpl file twice?

jfedor2, 2024-05-08:
No, use BOM and CPL files as you did and just click "continue".

statikg11, 2024-05-11:
Thank you. I was able to upload all required files turns out it was an error with the website. Customer support was able to troubleshoot it and resolve.

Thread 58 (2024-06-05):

KiCad files

laurazard, 2024-06-05:
Hiya,

I'm trying to make some changes to the PCB so I can play around/print my own (and also learn about PCB design), but I've only found the Gerber files. Since (it seems) KiCad is being used for the PCB design, I was wondering if it would be possible to share the KiCad files for the different revisions? I'm particularly interested in the rev. 1 files, but all/either of them would be a great start.

Thanks! (and please let me know if this isn't possible for one reason or another, or if I just missed them 😅).

jfedor2, 2024-06-05:
The KiCad files are in the "extras" folder for each revision.

laurazard, 2024-06-05:
Duh 🤦‍♀️ I think I might've checked that folder for [rev 1](https://github.com/jfedor2/flatbox/tree/master/hardware-rev1/extras), which doesn't include the KiCad project files, just a step file, but I didn't check the others. Thanks!

Closed 2024-06-05.

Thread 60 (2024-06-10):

Rev3 soldering help

sashraf16, 2024-06-10:
Hello,

First off, thanks for creating this project, I'm sure it'll work amazing, right after I have it fully set up.

I'm having some difficulty with the soldering potion. I have my flatbox PCB, and my P5 mini board, but the headers seem too large to pass through the PCB, and two far spaced to pass through either the P5 or the PCB. Am I approaching this incorrectly? Just using standard 0.1"/2.54mm single row headers.

Thanks!

sashraf16, 2024-06-10:
I found this [issue](https://github.com/jfedor2/flatbox/issues/24), seems to be similar, but I'm still not sure if I just use strength to force the pin through the PCB and if I have to manually separate the entire row of headers to try and make the gap between them smaller to fit the pattern on the board

jfedor2, 2024-06-10:
I think you need 2mm pitch headers, not 2.54mm.

sashraf16, 2024-06-10:
Oh I see, that would make sense.

Would something like this be worth trying?
[Amazon](uxcell a15062900ux0315 40Pin 2 mm Single Row Straight Male Header Connector Strip 18 Pcs https://a.co/d/i4g4bGV)

And to clarify, each hole should be soldered, correct?

jfedor2, 2024-06-10:
Yeah, looks like it.

I think some of the holes are not used, but it won't hurt to solder them too.

sashraf16, 2024-06-10:
Sweet I will try that and update here so it can be closed out, I think that should fix the issue. Will try to give it an attempt in the next couple of days

sashraf16, 2024-06-12:
I think the 2mm worked, I was able to (at least try) solder the boards together. I think we can close this issue, but I was wondering if you knew how to flash the firmware? I guess I hold reset and boot, as per Brook, but not sure which those are. Unless I'm completely off.

jfedor2, 2024-06-12:
I don't know, but surely the board came with some version of the firmware already flashed, right?

sashraf16, 2024-06-12:
I think it's a soldering issue, gonna take some time to sort this out. Thanks for all the help and clarification otherwise!

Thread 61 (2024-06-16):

Switches not working, Checked with multimeter

R-Bit-Git, 2024-06-16:
Hey Everybody,

I was hoping to get some help from people smarter than me. I'm having issues with some switches not working, namely switches sw2, sw5 ,sw6 (labels from PCB). sw1 worked momentarily but has since stopped.

The PCB connections between the poles were checked with a multi-meter before soldering the switches in, all worked. The connections were checked again after the switches were soldered in, all worked. after Connecting the RP2040-Zero the connection were checked between the switch pole and the RP pole and after pressing the button the signal came through. Some connections didn't work but after rechecking and adding to the solder the connections worked.

When connected to my PC and using the online gamepadtester (Found here https://hardwaretester.com/gamepad) the aforementioned switches didn't work. I wouldn't mind not having the use of them this being my first build and all, I could make do, however missing the sw2 makes it impossible to open the web configurator to rebind the keys from the current odd layout

any ideas or a nudge in the right direction would be greatly appreciated.

Regards

RBG

jfedor2, 2024-06-16:
What firmware did you flash?

You can always get into webconfig by flashing this by the way:

https://github.com/jfedor2/force_webconfig

R-Bit-Git, 2024-06-16:
I flashed the GP2040-CE_0.7.9_WaveshareZero

thanks for the webconfig, will give it a go.

jfedor2, 2024-06-16:
That's not the right firmware, you should have used the Flatbox rev5 one.

Probably easiest to wipe the board by flashing flash_nuke.uf2 and flash the correct firmware.

If you want to go to webconfig with the current firmware, just flash the force_webconfig.uf2 file same way you flashed the firmware (hold BOOT etc.). It will not change the firmware, just go to webconfig once.

R-Bit-Git, 2024-06-16:
Thank you so much that seems to have fixed it, sorry about the rookie error with the firmware, and thanks for the work you've done :D

Closed 2024-06-16.

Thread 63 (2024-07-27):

Rev5 　none of the buttons work

yaaabooo, 2024-07-27:
Sorry for my poor English, but I need some help.
I'm wondering why none of the buttons are connected to the GND.
Is this ok? It works when connected to the GND.

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

jfedor2, 2024-07-27:
All the buttons are connected to GND on the bottom layer.

Make sure this soldering point is OK:

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

yaaabooo, 2024-07-27:
I only saw the surface.
now I understood the layer structure. And the cause was my soldering mistake.
I appreciate your help.

Closed 2024-07-27.

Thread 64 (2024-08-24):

Flatbox rev5 registering as Hori.Pokken controller

BusFinn, 2024-08-24:
I bought a rev5 flatbox online a year or so ago, it originally registered through steam that it was an Xbox controller but at some point it started registering as a horri.pokken controller. I’ve flashed the controller and done the updates on the controller and have had no luck. I would really like to use this on other consoles other than my PC but I don’t think it’ll work if it keeps registering as the horri.pokken controller.

jfedor2, 2024-08-24:
You can switch modes by holding specific buttons while plugging the stick in or through webconfig.

https://gp2040-ce.info/usage/

BusFinn, 2024-08-24:
Thanks, I’ll try that and get back to you

BusFinn, 2024-08-25:
Yep that worked thanks so much!

Closed 2024-08-25.

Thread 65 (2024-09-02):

Rev4 vs. Rev5 Case

justin-delano, 2024-09-02:
Is the 3D printed case the same for Rev4 and Rev5? I printed Rev5, but now want to buy a Rev4 PCB. Thanks!

jfedor2, 2024-09-02:
No, the cases aren't compatible.

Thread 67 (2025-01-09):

rev4 , parts not looking aligned

cchoi27, 2025-01-09:
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

Hello, I'm unfamiliar with SMT assembly, so I'm not 100% sure what I am doing.
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
I receive this error.
I noticed that the parts are not alighed correctly, ie, the USB should be moved down and the U2 is rotated. Some of the resistors are misaligned as well.
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

Is this an error on JLCPCB's visualization? Should I fix them manually ? I'm hesitant to change anything because I assume the same CPL worked for others.

jfedor2, 2025-01-12:
It's true that the positions/orientations are not quite right on some of the components. I should really come back to it and fix them.

That said, these are the exact files that I have used with success, the way it has always worked is a human looked at these files and corrected the orientations before manufacturing. Maybe they're trying to automate the process more, I haven't ordered these in a while.

(The reason they're "incorrect" is some KiCad libraries use different origin conventions for the footprint than what JLCPCB uses. But that's no excuse since everyone is going to be ordering these from JLC.)

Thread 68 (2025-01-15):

Rev 2 firmware not compliling in arduino IDE

EnAtOSU, 2025-01-15:
Unsure if this is me or not. online ide and desktop has same issue of 'HID' was not declared in this scope, when trying to compile. This is without any edits to code.

jfedor2, 2025-01-15:
Did you select the right board in the menu?

EnAtOSU, 2025-01-15:
I guess I am unsure. Does the documentation say somewhere which board I should select?

jfedor2, 2025-01-15:
The one that you're using preferably.

jfedor2, 2025-01-15:
Arduino Pro Micro or any ATmega32U4-based really.

EnAtOSU, 2025-01-15:
that seems to have worked, thank you.

Closed 2025-01-15.

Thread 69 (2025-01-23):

Some questions regarding newer revisions (rev6 onwards)

adilahmeddev, 2025-01-23:
Hey, I was wondering why you decided to move away from the RP2040 boards? I can make some guesses for rev7 because of the complications around using bluetooth with gp2040ce.

Is my assumption correct? and what about rev6?

Thanks for all of your work on this project

jfedor2, 2025-01-24:
Don't worry, I still love the RP2040.

adilahmeddev, 2025-01-25:
Glad to hear it.

What was your motivation in using the CH552 for rev6 for example? Any particular reason or just exploring different options?

jfedor2, 2025-01-25:
I liked how few components that design uses.

adilahmeddev, 2025-01-25:
makes sense, thank you

Closed 2025-01-25.

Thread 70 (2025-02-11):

button step file?

bearzfgc, 2025-02-11:
Any chance there's a step file for the buttons? if not no worries, i might also be blind

jfedor2, 2025-02-15:
Here are the STEP files for the buttoncaps. I'll add them to the repository later.

[buttoncaps.zip](https://github.com/user-attachments/files/18807133/buttoncaps.zip)

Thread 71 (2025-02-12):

Rev 2 firmware attempts to call digitalread on analog only pins

EnAtOSU, 2025-02-12:
the switches connected to PF4 through PF7 are analog only pins, was able to fix firmware by calling analog read on those pins.

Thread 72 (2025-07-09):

pre assembly?

zendon180, 2025-07-09:
im thinking about building a REV9 and im fine with soldering the hotswap things and the buttons but idk about the other small things. im on jlcpcb and i just wanna know if it will work if i press pcb assembly.
thanks

jfedor2, 2025-07-14:
Yes, JLC can do the SMT assembly for you.

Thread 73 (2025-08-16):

Rev 9 Additional Button Firmware

abra04, 2025-08-16:
I want to add an extra button to the Rev9 and wanted to know if/how Id be able to do any firmware modifications to do it. Sorry if this is a basic question, Im a beginner and couldn't quite parse where Id be able to mod the firmware in the readme. Thanks!

jfedor2, 2025-08-16:
It runs a custom build of CircuitPython where all the pins are exposed through the board module with names like board.UP, board.DOWN, board.L1 etc. You'd likely have to add your new buttons there. Then modify the Python code to make the button do whatever you want it to do.

<https://github.com/jfedor2/circuitpython/blob/flatbox-rev9/ports/atmel-samd/boards/flatbox_rev9/pins.c>

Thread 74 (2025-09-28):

Rev 9 Firmware Flashing Additional Instructions

HuddyP, 2025-09-28:
Are there extra steps in preparing the board for flashing the firmware on the Rev 9 that should to be added to the README for newer builders? From what I've tried to research, getting OpenOCD set up for commands to register in CMD to complete the first few steps has been a huge pain point that I cannot get figured out as somebody that's unfamiliar with flashing firmware for these kinds of boards

jfedor2, 2025-09-28:
No, these are all the steps.

ReggaeUlli, 2025-09-28:
I just did it yesterday. After downloading openocd you need to add it to path, so that the command is found. Otherwise you call the openocd exe with its full path. Then i did not get openocd to run as it said it "could not open the device".

the problem for me was that i needed to install drivers for my USB Debug interface.

So i plugged it in via USB and then in file Explorer within this USB device. There was a folder with drivers i manually needed to install. But this will be different for each different brand.

Those are the only two steps i needed which are not in the Dokumentation, but i think AS they are Plattform dependent for Installation and brand dependent for the drivers it is not so helpful to add.

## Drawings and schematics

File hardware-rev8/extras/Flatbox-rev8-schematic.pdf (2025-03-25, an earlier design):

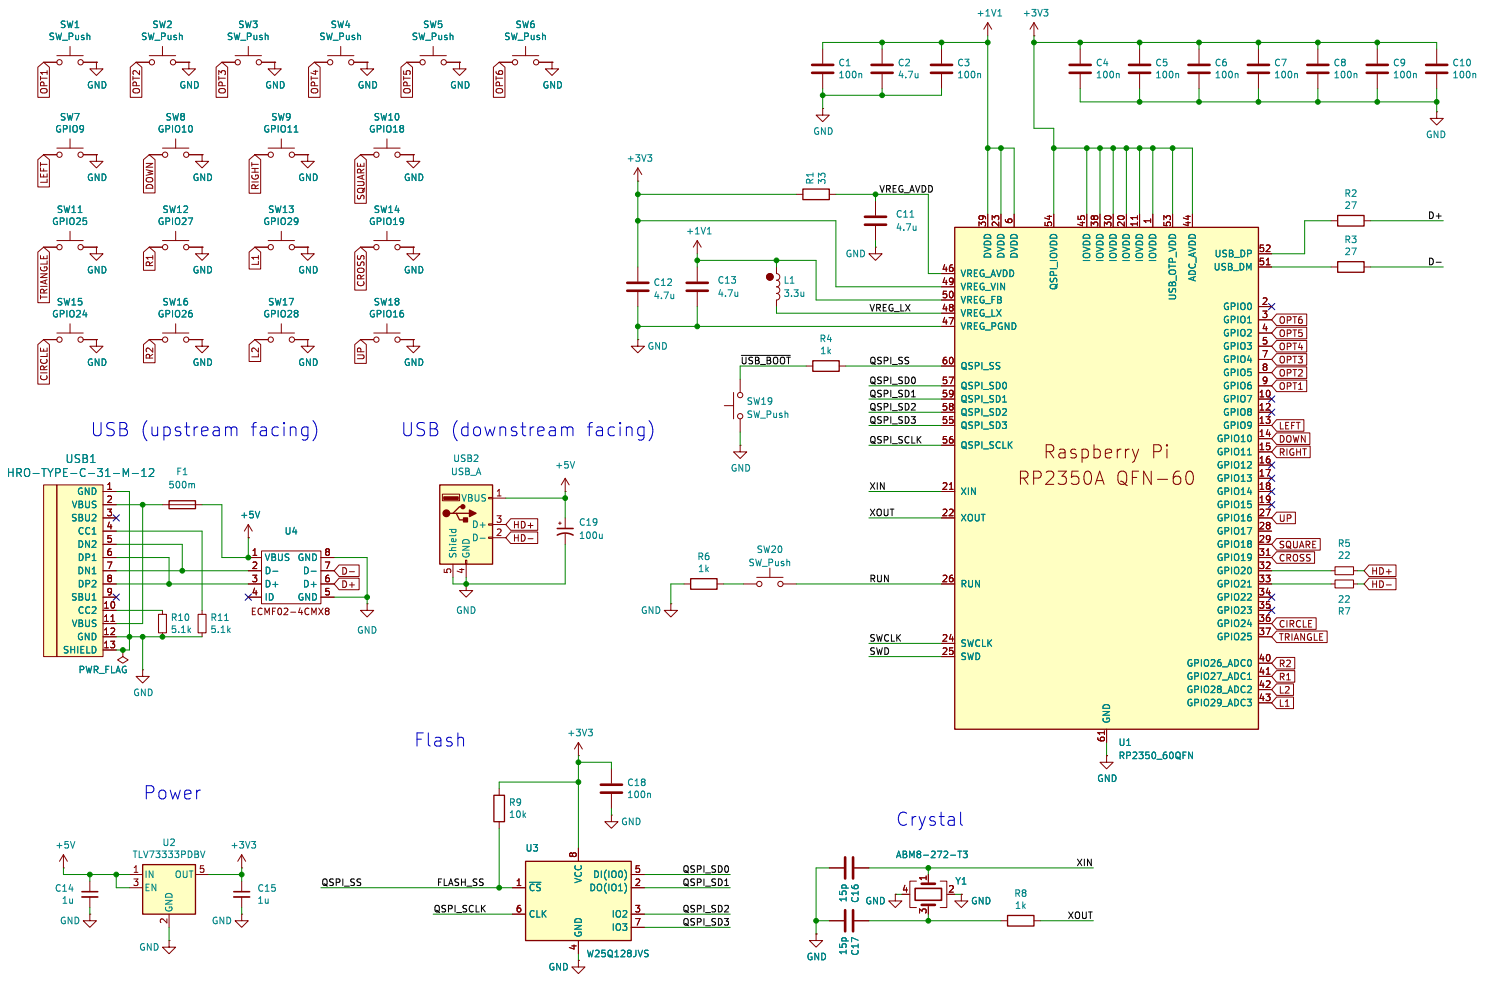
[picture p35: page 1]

100n SW5 SW_Push GND GND GND GND

6 QSPI_IOVDD 54 IOVDD 45 IOVDD 38 GND 61 IOVDD 30 IOVDD 20 IOVDD 11 IOVDD

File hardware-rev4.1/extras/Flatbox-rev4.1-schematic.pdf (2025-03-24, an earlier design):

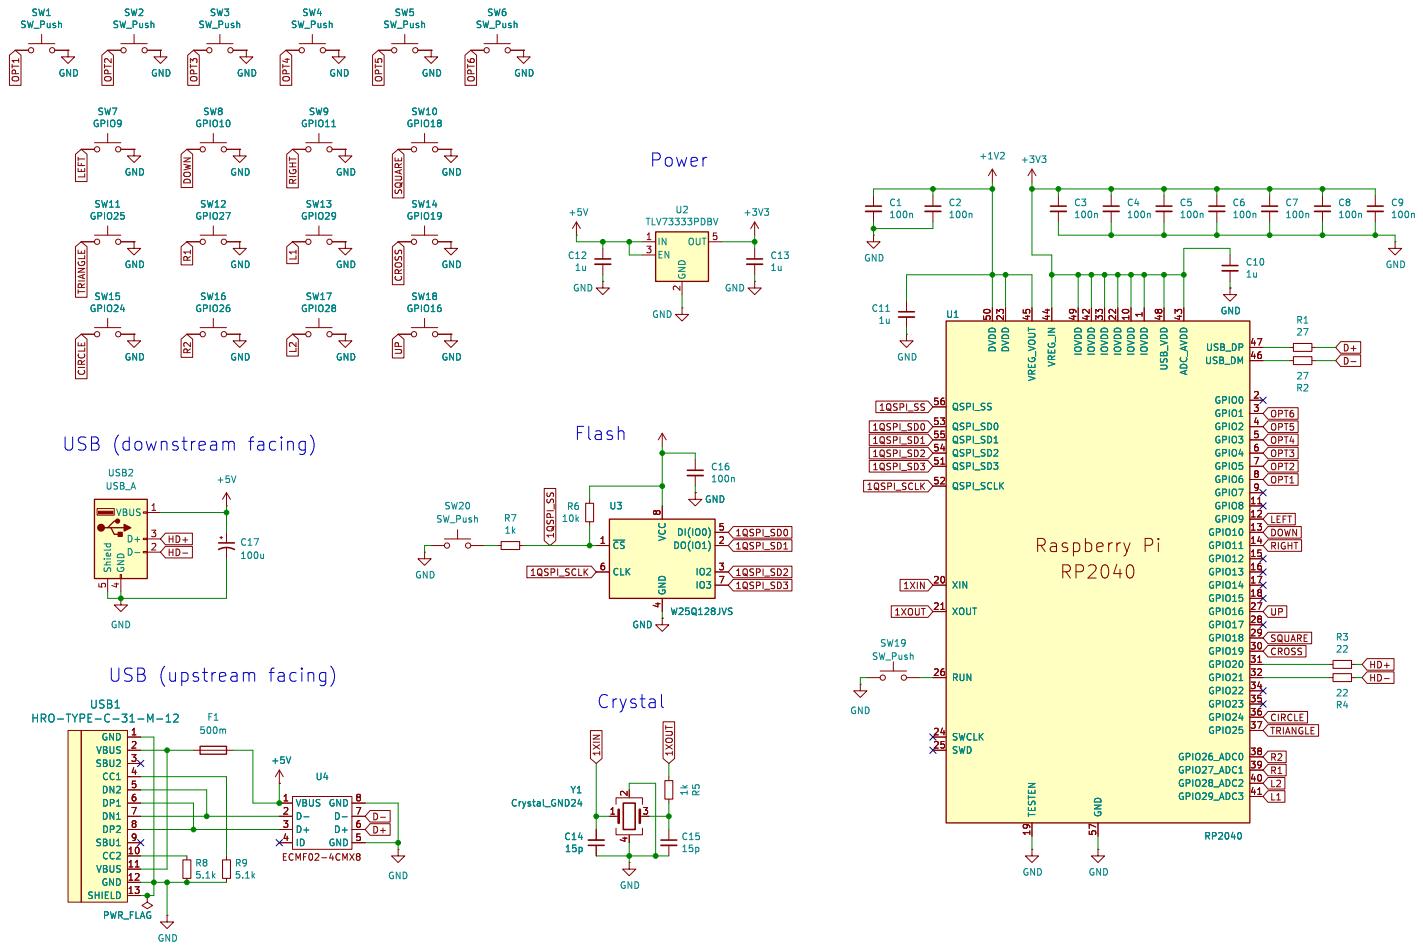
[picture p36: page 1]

2 OUT 5 U2 TLV73333PDBV GND GND GND

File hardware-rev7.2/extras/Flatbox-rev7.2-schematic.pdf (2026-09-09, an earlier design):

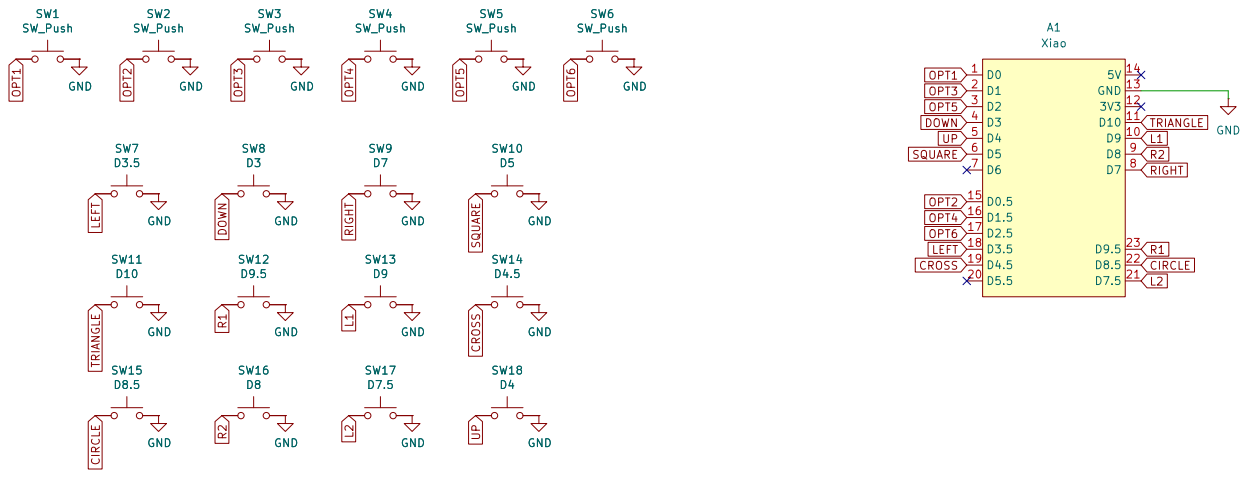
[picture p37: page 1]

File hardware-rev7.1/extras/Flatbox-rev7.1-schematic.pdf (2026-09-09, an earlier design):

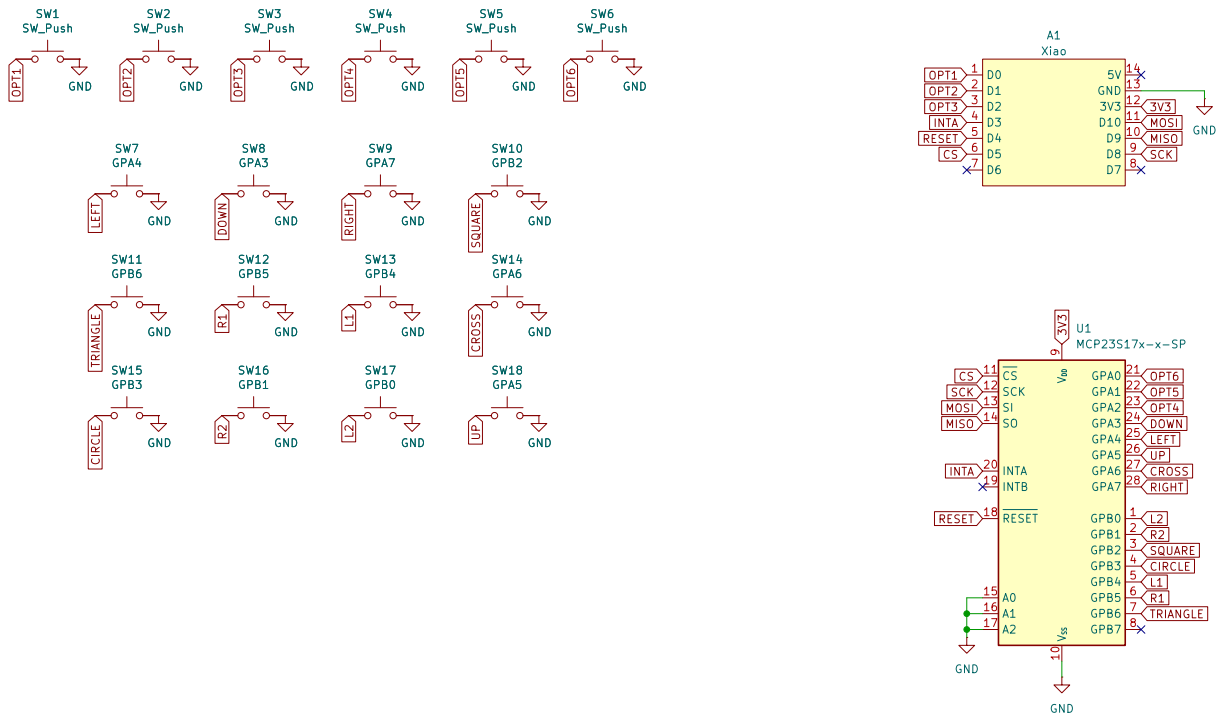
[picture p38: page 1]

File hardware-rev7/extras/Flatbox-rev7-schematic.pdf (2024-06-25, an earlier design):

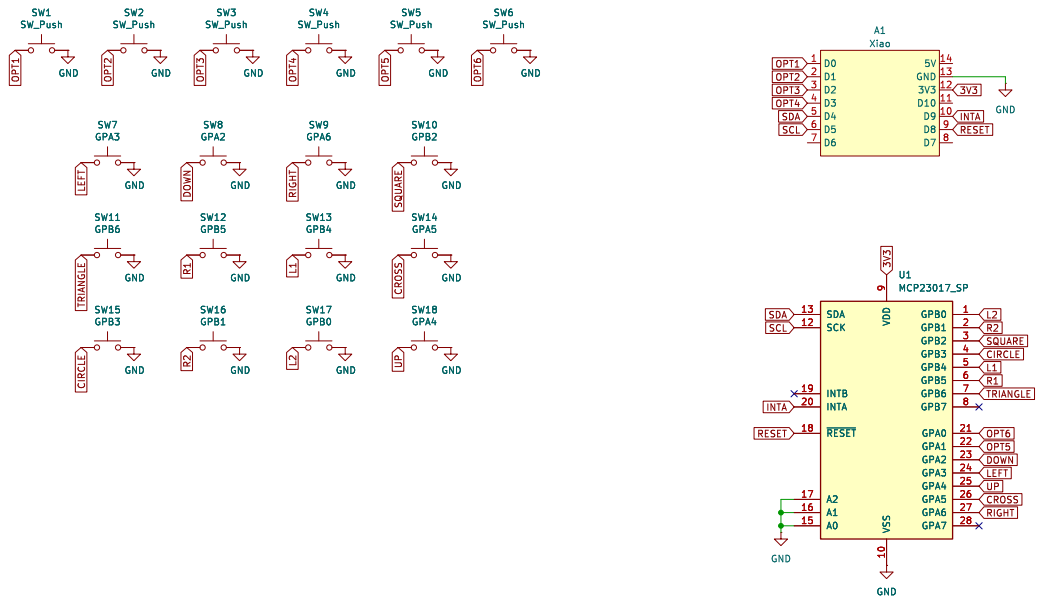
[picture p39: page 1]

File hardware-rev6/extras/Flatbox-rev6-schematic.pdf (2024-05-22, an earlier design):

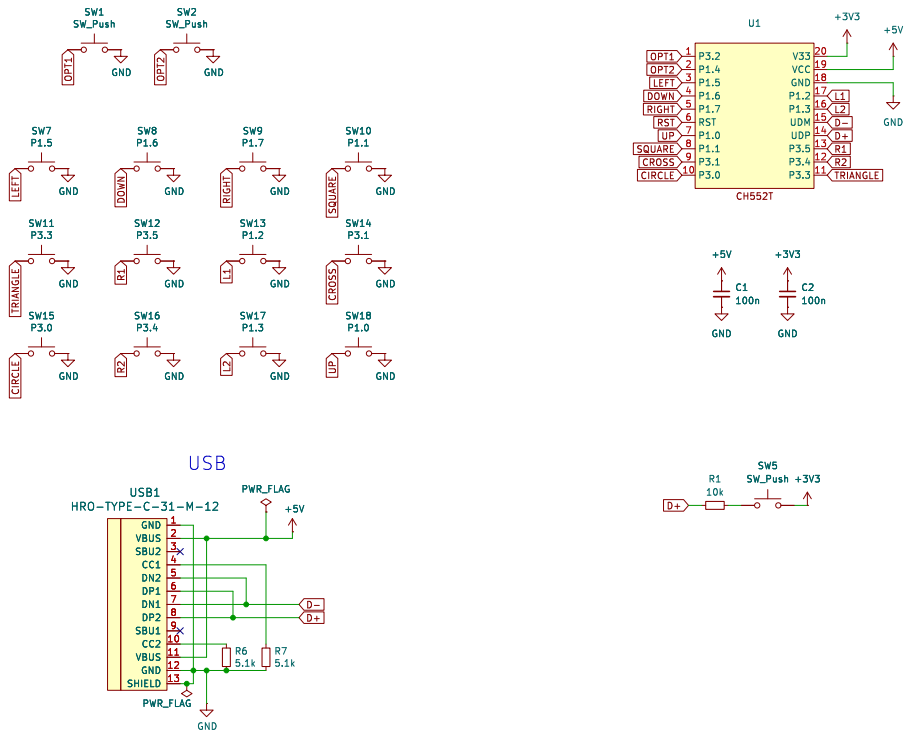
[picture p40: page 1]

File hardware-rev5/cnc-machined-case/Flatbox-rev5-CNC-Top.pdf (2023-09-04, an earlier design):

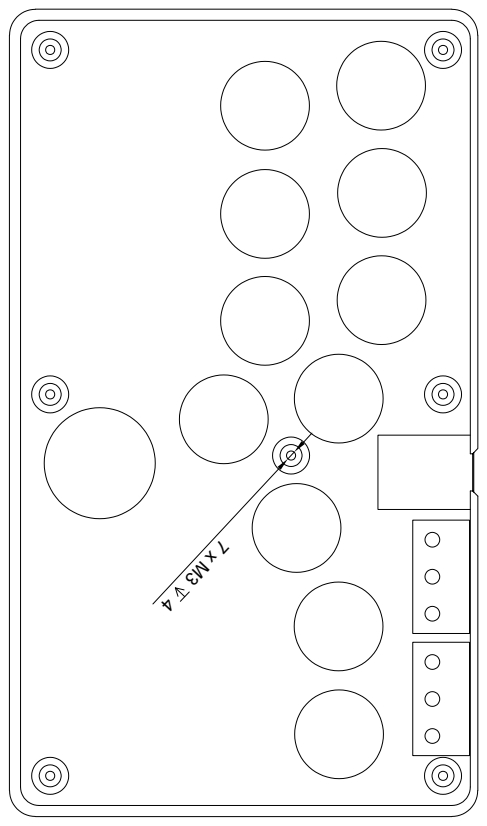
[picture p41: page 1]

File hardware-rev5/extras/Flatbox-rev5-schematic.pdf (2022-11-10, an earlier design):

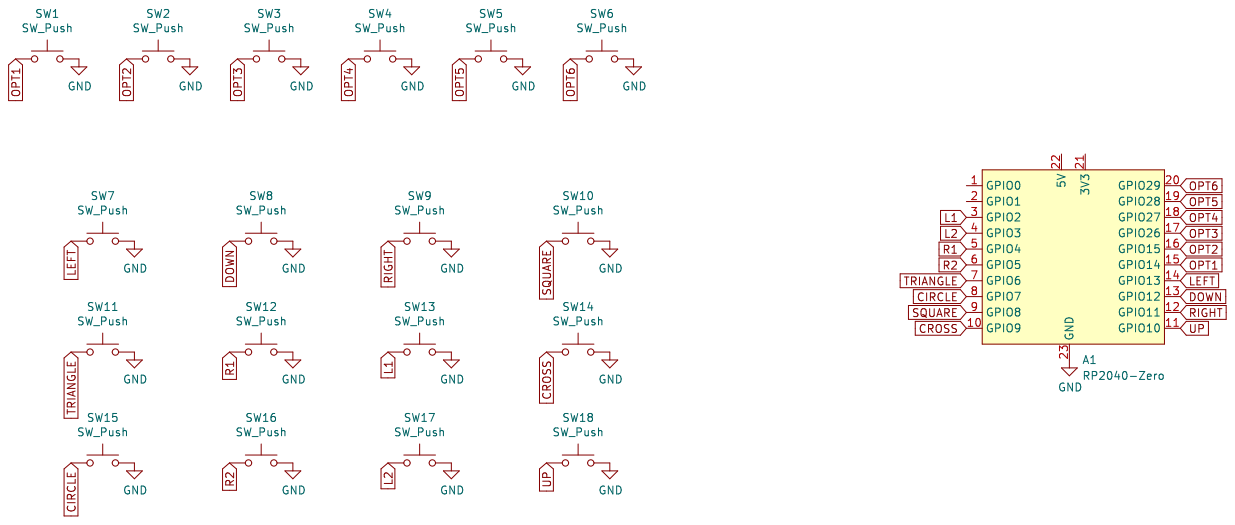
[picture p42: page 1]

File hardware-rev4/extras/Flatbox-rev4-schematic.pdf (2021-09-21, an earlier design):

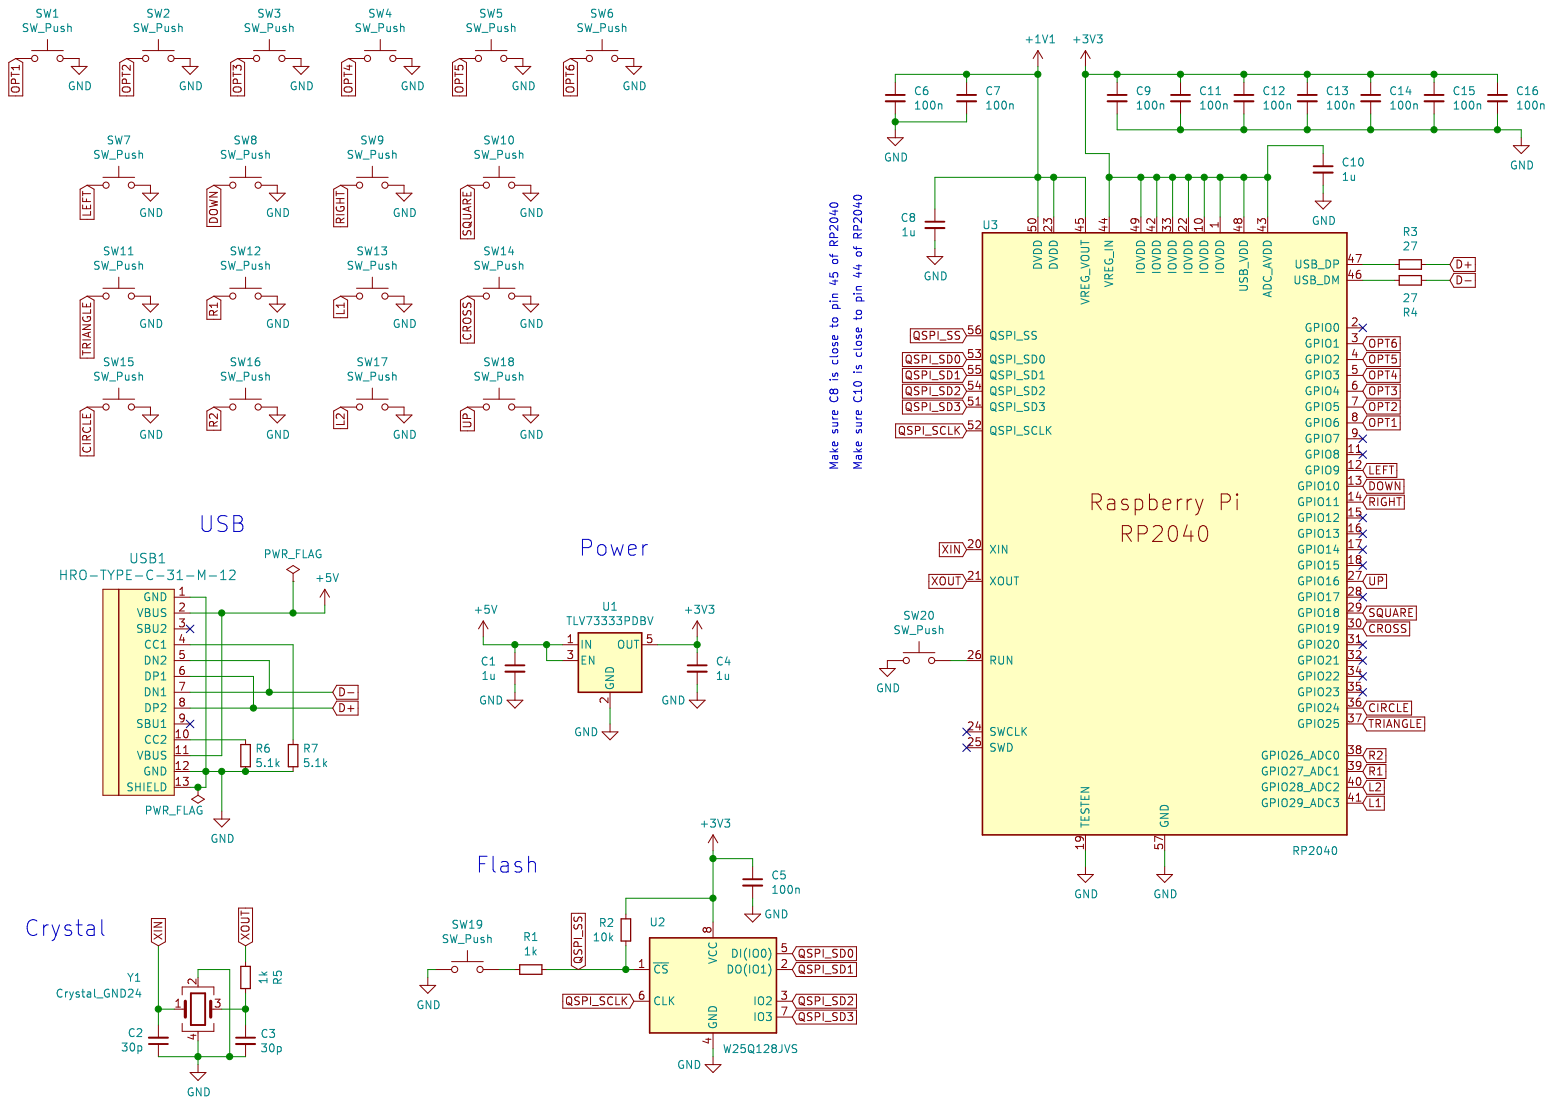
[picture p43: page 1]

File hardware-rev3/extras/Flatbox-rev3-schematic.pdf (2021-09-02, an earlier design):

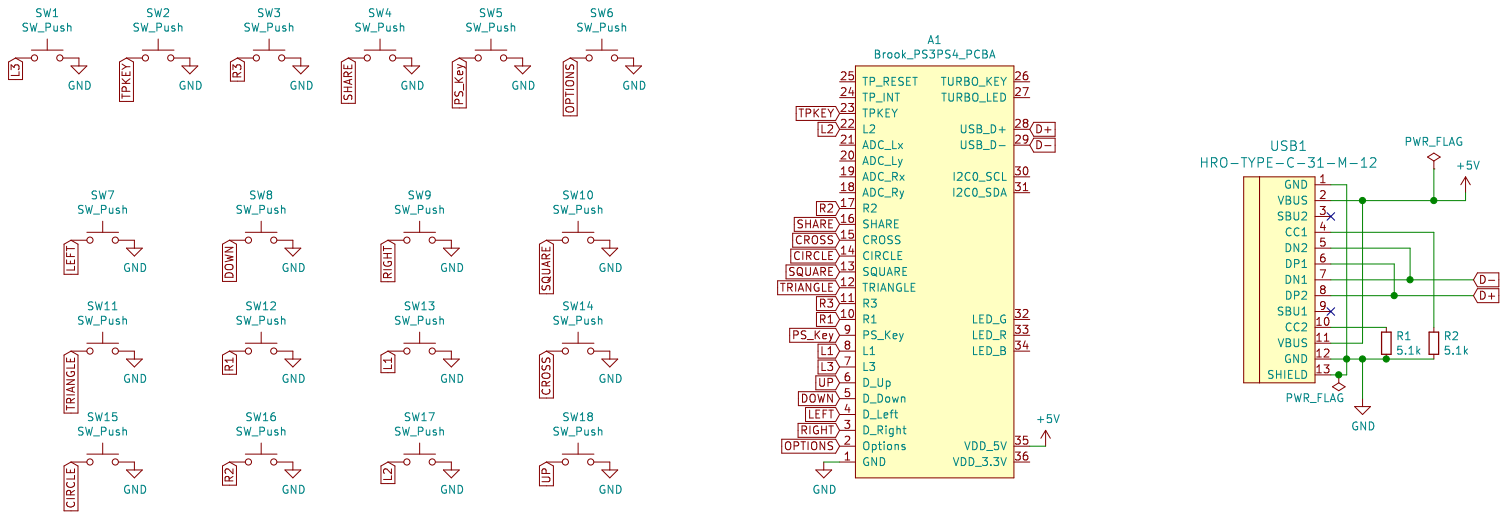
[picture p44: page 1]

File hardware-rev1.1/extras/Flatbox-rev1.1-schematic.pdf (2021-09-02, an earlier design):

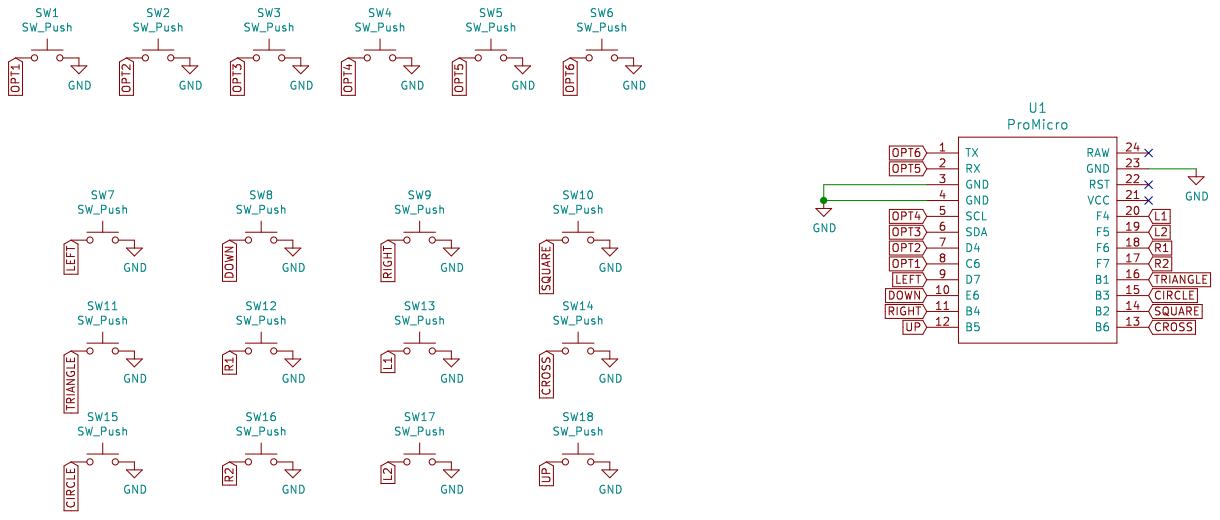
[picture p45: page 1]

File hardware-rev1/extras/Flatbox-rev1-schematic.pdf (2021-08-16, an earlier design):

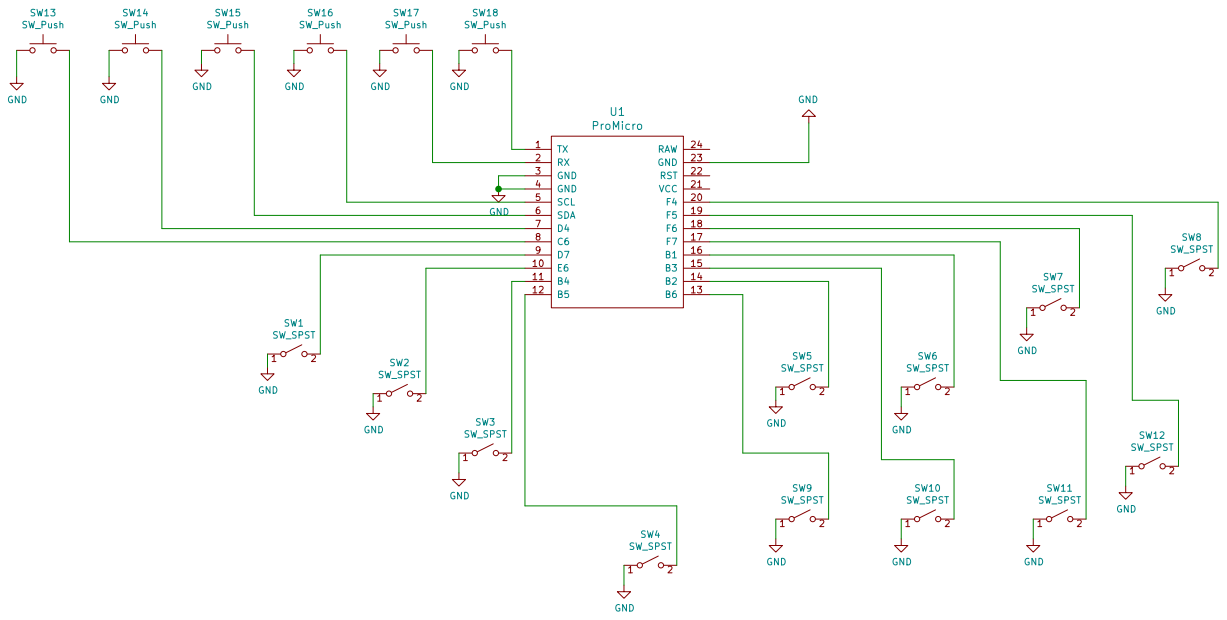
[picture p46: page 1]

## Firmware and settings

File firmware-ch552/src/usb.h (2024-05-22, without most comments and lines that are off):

#pragma once
#include <stdint.h>
#define USB_PID_NULL            0x00  // reserved PID
#define USB_PID_SOF             0x05
#define USB_PID_SETUP           0x0D
#define USB_PID_IN              0x09
#define USB_PID_OUT             0x01
#define USB_PID_ACK             0x02
#define USB_PID_NAK             0x0A
#define USB_PID_STALL           0x0E
#define USB_PID_DATA0           0x03
#define USB_PID_DATA1           0x0B
#define USB_PID_PRE             0x0C
#define USB_GET_STATUS          0x00
#define USB_CLEAR_FEATURE       0x01
#define USB_SET_FEATURE         0x03
#define USB_SET_ADDRESS         0x05
#define USB_GET_DESCRIPTOR      0x06
#define USB_SET_DESCRIPTOR      0x07
#define USB_GET_CONFIGURATION   0x08
#define USB_SET_CONFIGURATION   0x09
#define USB_GET_INTERFACE       0x0A
#define USB_SET_INTERFACE       0x0B
#define USB_SYNCH_FRAME         0x0C
#define HUB_GET_STATUS          0x00
#define HUB_CLEAR_FEATURE       0x01
#define HUB_GET_STATE           0x02
#define HUB_SET_FEATURE         0x03
#define HUB_GET_DESCRIPTOR      0x06
#define HUB_SET_DESCRIPTOR      0x07
#define HID_GET_REPORT          0x01
#define HID_GET_IDLE            0x02
#define HID_GET_PROTOCOL        0x03
#define HID_SET_REPORT          0x09
#define HID_SET_IDLE            0x0A
#define HID_SET_PROTOCOL        0x0B
#define USB_REQ_TYP_IN          0x80  // control IN, device to host
#define USB_REQ_TYP_OUT         0x00  // control OUT, host to device
#define USB_REQ_TYP_READ        0x80  // control read, device to host
#define USB_REQ_TYP_WRITE       0x00  // control write, host to device
#define USB_REQ_TYP_MASK        0x60  // bit mask of request type
#define USB_REQ_TYP_STANDARD    0x00
#define USB_REQ_TYP_CLASS       0x20
#define USB_REQ_TYP_VENDOR      0x40
#define USB_REQ_TYP_RESERVED    0x60
#define USB_REQ_RECIP_MASK      0x1F  // bit mask of request recipient
#define USB_REQ_RECIP_DEVICE    0x00
#define USB_REQ_RECIP_INTERF    0x01
#define USB_REQ_RECIP_ENDP      0x02
#define USB_REQ_RECIP_OTHER     0x03
#define HUB_CLEAR_HUB_FEATURE   0x20
#define HUB_CLEAR_PORT_FEATURE  0x23
#define HUB_GET_BUS_STATE       0xA3
#define HUB_GET_HUB_DESCRIPTOR  0xA0
#define HUB_GET_HUB_STATUS      0xA0
#define HUB_GET_PORT_STATUS     0xA3
#define HUB_SET_HUB_DESCRIPTOR  0x20
#define HUB_SET_HUB_FEATURE     0x20
#define HUB_SET_PORT_FEATURE    0x23
#define HUB_C_HUB_LOCAL_POWER   0
#define HUB_C_HUB_OVER_CURRENT  1
#define HUB_PORT_CONNECTION     0
#define HUB_PORT_ENABLE         1
#define HUB_PORT_SUSPEND        2
#define HUB_PORT_OVER_CURRENT   3
#define HUB_PORT_RESET          4
#define HUB_PORT_POWER          8
#define HUB_PORT_LOW_SPEED      9
#define HUB_C_PORT_CONNECTION   16
#define HUB_C_PORT_ENABLE       17
#define HUB_C_PORT_SUSPEND      18
#define HUB_C_PORT_OVER_CURRENT 19
#define HUB_C_PORT_RESET        20
#define USB_DESCR_TYP_DEVICE    0x01
#define USB_DESCR_TYP_CONFIG    0x02
#define USB_DESCR_TYP_STRING    0x03
#define USB_DESCR_TYP_INTERF    0x04
#define USB_DESCR_TYP_ENDP      0x05
#define USB_DESCR_TYP_QUALIF    0x06
#define USB_DESCR_TYP_SPEED     0x07
#define USB_DESCR_TYP_OTG       0x09
#define USB_DESCR_TYP_IAD       0x0B
#define USB_DESCR_TYP_HID       0x21
#define USB_DESCR_TYP_REPORT    0x22
#define USB_DESCR_TYP_PHYSIC    0x23
#define USB_DESCR_TYP_CS_INTF   0x24
#define USB_DESCR_TYP_CS_ENDP   0x25
#define USB_DESCR_TYP_HUB       0x29
#define USB_DEV_CLASS_RESERVED  0x00
#define USB_DEV_CLASS_AUDIO     0x01
#define USB_DEV_CLASS_COMM      0x02
#define USB_DEV_CLASS_HID       0x03
#define USB_DEV_CLASS_MONITOR   0x04
#define USB_DEV_CLASS_PHYSIC_IF 0x05
#define USB_DEV_CLASS_POWER     0x06
#define USB_DEV_CLASS_PRINTER   0x07
#define USB_DEV_CLASS_STORAGE   0x08
#define USB_DEV_CLASS_HUB       0x09
#define USB_DEV_CLASS_DATA      0x0A
#define USB_DEV_CLASS_MISC      0xEF
#define USB_DEV_CLASS_VENDOR    0xFF
#define USB_ENDP_DIR_MASK       0x80
#define USB_ENDP_ADDR_MASK      0x0F
#define USB_ENDP_TYPE_MASK      0x03
#define USB_ENDP_TYPE_CTRL      0x00
#define USB_ENDP_TYPE_ISOCH     0x01
#define USB_ENDP_TYPE_BULK      0x02
#define USB_ENDP_TYPE_INTER     0x03
#define USB_ENDP_ADDR_EP1_OUT   0x01
#define USB_ENDP_ADDR_EP1_IN    0x81
#define USB_ENDP_ADDR_EP2_OUT   0x02
#define USB_ENDP_ADDR_EP2_IN    0x82
#define USB_ENDP_ADDR_EP3_OUT   0x03
#define USB_ENDP_ADDR_EP3_IN    0x83
#define USB_ENDP_ADDR_EP4_OUT   0x04
#define USB_ENDP_ADDR_EP4_IN    0x84
  #define USB_DEVICE_ADDR       0x02  // default USB device address
  #define DEFAULT_ENDP0_SIZE    8     // default maximum packet size for endpoint 0
  #define DEFAULT_ENDP1_SIZE    8     // default maximum packet size for endpoint 1
  #define MAX_PACKET_SIZE       64    // maximum packet size
  #define USB_BO_CBW_SIZE       0x1F  // total length of command block CBW
  #define USB_BO_CSW_SIZE       0x0D  // total length of command status block CSW
  #define USB_BO_CBW_SIG0       0x55  // command block CBW identification flag 'USBC'
  #define USB_BO_CBW_SIG1       0x53
  #define USB_BO_CBW_SIG2       0x42
  #define USB_BO_CBW_SIG3       0x43
  #define USB_BO_CSW_SIG0       0x55  // command status block CSW identification flag 'USBS'
  #define USB_BO_CSW_SIG1       0x53
  #define USB_BO_CSW_SIG2       0x42
  #define USB_BO_CSW_SIG3       0x53
typedef struct _USB_SETUP_REQ {
    uint8_t  bRequestType;
    uint8_t  bRequest;
    uint8_t  wValueL;
    uint8_t  wValueH;
    uint8_t  wIndexL;
    uint8_t  wIndexH;
    uint8_t  wLengthL;
    uint8_t  wLengthH;
} USB_SETUP_REQ, *PUSB_SETUP_REQ;
typedef USB_SETUP_REQ __xdata *PXUSB_SETUP_REQ;
typedef struct _USB_DEVICE_DESCR {
    uint8_t  bLength;
    uint8_t  bDescriptorType;
    uint16_t bcdUSB;
    uint8_t  bDeviceClass;
    uint8_t  bDeviceSubClass;
    uint8_t  bDeviceProtocol;
    uint8_t  bMaxPacketSize0;
    uint16_t idVendor;
    uint16_t idProduct;
    uint16_t bcdDevice;
    uint8_t  iManufacturer;
    uint8_t  iProduct;
    uint8_t  iSerialNumber;
    uint8_t  bNumConfigurations;
} USB_DEV_DESCR, *PUSB_DEV_DESCR;
typedef USB_DEV_DESCR __xdata *PXUSB_DEV_DESCR;
typedef struct _USB_CONFIG_DESCR {
    uint8_t  bLength;
    uint8_t  bDescriptorType;
    uint16_t wTotalLength;
    uint8_t  bNumInterfaces;
    uint8_t  bConfigurationValue;
    uint8_t  iConfiguration;
    uint8_t  bmAttributes;
    uint8_t  MaxPower;
} USB_CFG_DESCR, *PUSB_CFG_DESCR;
typedef USB_CFG_DESCR __xdata *PXUSB_CFG_DESCR;
typedef struct _USB_INTERF_DESCR {
    uint8_t  bLength;
    uint8_t  bDescriptorType;
    uint8_t  bInterfaceNumber;
    uint8_t  bAlternateSetting;
    uint8_t  bNumEndpoints;
    uint8_t  bInterfaceClass;
    uint8_t  bInterfaceSubClass;
    uint8_t  bInterfaceProtocol;
    uint8_t  iInterface;
} USB_ITF_DESCR, *PUSB_ITF_DESCR;
typedef USB_ITF_DESCR __xdata *PXUSB_ITF_DESCR;
typedef struct _USB_ITF_ASS_DESCR {
    uint8_t  bLength;
    uint8_t  bDescriptorType;
    uint8_t  bFirstInterface;
    uint8_t  bInterfaceCount;
    uint8_t  bFunctionClass;
    uint8_t  bFunctionSubClass;
    uint8_t  bFunctionProtocol;
    uint8_t  iFunction;
} USB_IAD_DESCR, *PUSB_IAD_DESCR;
typedef USB_IAD_DESCR __xdata *PXUSB_IAD_DESCR;
typedef struct _USB_ENDPOINT_DESCR {
    uint8_t  bLength;
    uint8_t  bDescriptorType;
    uint8_t  bEndpointAddress;
    uint8_t  bmAttributes;
    uint16_t wMaxPacketSize;
    uint8_t  bInterval;
} USB_ENDP_DESCR, *PUSB_ENDP_DESCR;
typedef USB_ENDP_DESCR __xdata *PXUSB_ENDP_DESCR;
typedef struct _USB_CONFIG_DESCR_LONG {
    USB_CFG_DESCR   cfg_descr;
    USB_ITF_DESCR   itf_descr;
    USB_ENDP_DESCR  endp_descr[1];
} USB_CFG_DESCR_LONG, *PUSB_CFG_DESCR_LONG;
typedef USB_CFG_DESCR_LONG __xdata *PXUSB_CFG_DESCR_LONG;
typedef struct _USB_HUB_DESCR {
    uint8_t  bDescLength;
    uint8_t  bDescriptorType;
    uint8_t  bNbrPorts;
    uint16_t wHubCharacteristics;
    uint8_t  bPwrOn2PwrGood;
    uint8_t  bHubContrCurrent;
    uint8_t  DeviceRemovable;
    uint8_t  PortPwrCtrlMask;
} USB_HUB_DESCR, *PUSB_HUB_DESCR;
typedef USB_HUB_DESCR __xdata *PXUSB_HUB_DESCR;
typedef struct _USB_HID_DESCR {
    uint8_t  bLength;
    uint8_t  bDescriptorType;
    uint16_t bcdHID;
    uint8_t  bCountryCode;
    uint8_t  bNumDescriptors;
    uint8_t  bDescriptorTypeX;
    uint16_t wDescriptorLength;
} USB_HID_DESCR, *PUSB_HID_DESCR;
typedef USB_HID_DESCR __xdata *PXUSB_HID_DESCR;
typedef struct _UDISK_BOC_CBW {             // command of BulkOnly USB-FlashDisk
    uint8_t mCBW_Sig0;
    uint8_t mCBW_Sig1;
    uint8_t mCBW_Sig2;
    uint8_t mCBW_Sig3;
    uint8_t mCBW_Tag0;
    uint8_t mCBW_Tag1;
    uint8_t mCBW_Tag2;
    uint8_t mCBW_Tag3;
    uint8_t mCBW_DataLen0;
    uint8_t mCBW_DataLen1;
    uint8_t mCBW_DataLen2;
    uint8_t mCBW_DataLen3;                  // uppest byte of data length, always is 0
    uint8_t mCBW_Flag;                      // transfer direction and etc.
    uint8_t mCBW_LUN;
    uint8_t mCBW_CB_Len;                    // length of command block
    uint8_t mCBW_CB_Buf[16];                // command block buffer
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

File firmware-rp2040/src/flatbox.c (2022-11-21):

/* 
 * The MIT License (MIT)
 *
 * Copyright (c) 2021 Jacek Fedorynski
 * Copyright (c) 2019 Ha Thach (tinyusb.org)
 *
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
 */

#include <stdlib.h>
#include <stdio.h>
#include <string.h>

#include "bsp/board.h"
#include "tusb.h"

#include "hardware/gpio.h"

int stickMode = 0;              // 0 = dpad, 1 = left stick

// These IDs are bogus. If you want to distribute any hardware using this,
// you will have to get real ones.
#define USB_VID 0xCAFE
#define USB_PID 0xBABA

#ifdef FLATBOX_REV4

#define PIN_UP        16
#define PIN_DOWN      10
#define PIN_LEFT      9
#define PIN_RIGHT     11
#define PIN_CROSS     19
#define PIN_CIRCLE    24
#define PIN_TRIANGLE  25
#define PIN_SQUARE    18
#define PIN_L1        29
#define PIN_L2        28
#define PIN_R1        27
#define PIN_R2        26
#define PIN_SELECT    3
#define PIN_START     1
#define PIN_L3        6
#define PIN_R3        4
#define PIN_PS        2

#endif

#ifdef FLATBOX_REV5

#define PIN_UP        10
#define PIN_DOWN      12
#define PIN_LEFT      13
#define PIN_RIGHT     11
#define PIN_CROSS     9
#define PIN_CIRCLE    7
#define PIN_TRIANGLE  6
#define PIN_SQUARE    8
#define PIN_L1        2
#define PIN_L2        3
#define PIN_R1        4
#define PIN_R2        5
#define PIN_SELECT    27
#define PIN_START     29
#define PIN_L3        14
#define PIN_R3        26
#define PIN_PS        28

#endif

uint32_t pin_mask = 1 << PIN_UP | 1 << PIN_DOWN | 1 << PIN_LEFT | 1 << PIN_RIGHT | 1 << PIN_CROSS | 1 << PIN_CIRCLE | 1 << PIN_TRIANGLE | 1 << PIN_SQUARE | 1 << PIN_L1 | 1 << PIN_L2 | 1 << PIN_R1 | 1 << PIN_R2 | 1 << PIN_SELECT | 1 << PIN_START | 1 << PIN_L3 | 1 << PIN_R3 | 1 << PIN_PS;

tusb_desc_device_t const desc_device = {
    .bLength = sizeof(tusb_desc_device_t),
    .bDescriptorType = TUSB_DESC_DEVICE,
    .bcdUSB = 0x0200,
    .bDeviceClass = 0x00,
    .bDeviceSubClass = 0x00,
    .bDeviceProtocol = 0x00,
    .bMaxPacketSize0 = CFG_TUD_ENDPOINT0_SIZE,

    .idVendor = USB_VID,
    .idProduct = USB_PID,
    .bcdDevice = 0x0100,

    .iManufacturer = 0x01,
    .iProduct = 0x02,
    .iSerialNumber = 0x00,

    .bNumConfigurations = 0x01
};

// HID report descriptor taken from a HORI Fighting Stick V3
// with feature and output bits omitted
// works out of the box with PC and PS3
// as dumped by usbhid-dump and parsed by https://eleccelerator.com/usbdescreqparser/
uint8_t const desc_hid_report[] = {
    0x05, 0x01,                 // Usage Page (Generic Desktop Ctrls)
    0x09, 0x05,                 // Usage (Game Pad)
    0xA1, 0x01,                 // Collection (Application)
    0x15, 0x00,                 //   Logical Minimum (0)
    0x25, 0x01,                 //   Logical Maximum (1)
    0x35, 0x00,                 //   Physical Minimum (0)
    0x45, 0x01,                 //   Physical Maximum (1)
    0x75, 0x01,                 //   Report Size (1)
    0x95, 0x0D,                 //   Report Count (13)
    0x05, 0x09,                 //   Usage Page (Button)
    0x19, 0x01,                 //   Usage Minimum (0x01)
    0x29, 0x0D,                 //   Usage Maximum (0x0D)
    0x81, 0x02,                 //   Input (Data,Var,Abs,No Wrap,Linear,Preferred State,No Null Position)
    0x95, 0x03,                 //   Report Count (3)
    0x81, 0x01,                 //   Input (Const,Array,Abs,No Wrap,Linear,Preferred State,No Null Position)
    0x05, 0x01,                 //   Usage Page (Generic Desktop Ctrls)
    0x25, 0x07,                 //   Logical Maximum (7)
    0x46, 0x3B, 0x01,           //   Physical Maximum (315)
    0x75, 0x04,                 //   Report Size (4)
    0x95, 0x01,                 //   Report Count (1)
    0x65, 0x14,                 //   Unit (System: English Rotation, Length: Centimeter)
    0x09, 0x39,                 //   Usage (Hat switch)
    0x81, 0x42,                 //   Input (Data,Var,Abs,No Wrap,Linear,Preferred State,Null State)
    0x65, 0x00,                 //   Unit (None)
    0x95, 0x01,                 //   Report Count (1)
    0x81, 0x01,                 //   Input (Const,Array,Abs,No Wrap,Linear,Preferred State,No Null Position)
    0x26, 0xFF, 0x00,           //   Logical Maximum (255)
    0x46, 0xFF, 0x00,           //   Physical Maximum (255)
    0x09, 0x30,                 //   Usage (X)
    0x09, 0x31,                 //   Usage (Y)
    0x09, 0x32,                 //   Usage (Z)
    0x09, 0x35,                 //   Usage (Rz)
    0x75, 0x08,                 //   Report Size (8)
    0x95, 0x04,                 //   Report Count (4)
    0x81, 0x02,                 //   Input (Data,Var,Abs,No Wrap,Linear,Preferred State,No Null Position)
    0x06, 0x00, 0xFF,           //   Usage Page (Vendor Defined 0xFF00)
    0x09, 0x20,                 //   Usage (0x20)
    0x09, 0x21,                 //   Usage (0x21)
    0x09, 0x22,                 //   Usage (0x22)
    0x09, 0x23,                 //   Usage (0x23)
    0x09, 0x24,                 //   Usage (0x24)
    0x09, 0x25,                 //   Usage (0x25)
    0x09, 0x26,                 //   Usage (0x26)
    0x09, 0x27,                 //   Usage (0x27)
    0x09, 0x28,                 //   Usage (0x28)
    0x09, 0x29,                 //   Usage (0x29)
    0x09, 0x2A,                 //   Usage (0x2A)
    0x09, 0x2B,                 //   Usage (0x2B)
    0x95, 0x0C,                 //   Report Count (12)
    0x81, 0x02,                 //   Input (Data,Var,Abs,No Wrap,Linear,Preferred State,No Null Position)
/*
    0x0A, 0x21, 0x26,           //   Usage (0x2621)
    0x95, 0x08,                 //   Report Count (8)
    0xB1, 0x02,                 //   Feature (Data,Var,Abs,No Wrap,Linear,Preferred State,No Null Position,Non-volatile)
    0x0A, 0x21, 0x26,           //   Usage (0x2621)
    0x91, 0x02,                 //   Output (Data,Var,Abs,No Wrap,Linear,Preferred State,No Null Position,Non-volatile)
*/
    0x26, 0xFF, 0x03,           //   Logical Maximum (1023)
    0x46, 0xFF, 0x03,           //   Physical Maximum (1023)
    0x09, 0x2C,                 //   Usage (0x2C)
    0x09, 0x2D,                 //   Usage (0x2D)
    0x09, 0x2E,                 //   Usage (0x2E)
    0x09, 0x2F,                 //   Usage (0x2F)
    0x75, 0x10,                 //   Report Size (16)
    0x95, 0x04,                 //   Report Count (4)
    0x81, 0x02,                 //   Input (Data,Var,Abs,No Wrap,Linear,Preferred State,No Null Position)
    0xC0,                       // End Collection
};

#define CONFIG_TOTAL_LEN (TUD_CONFIG_DESC_LEN + TUD_HID_DESC_LEN)
#define EPNUM_HID 0x81

uint8_t const desc_configuration[] = {
    // Config number, interface count, string index, total length, attribute, power in mA
    TUD_CONFIG_DESCRIPTOR(1, 1, 0, CONFIG_TOTAL_LEN, 0, 100),

    // Interface number, string index, protocol, report descriptor len, EP In address, size & polling interval
    TUD_HID_DESCRIPTOR(0, 0, HID_ITF_PROTOCOL_NONE, sizeof(desc_hid_report), EPNUM_HID, CFG_TUD_HID_EP_BUFSIZE, 1)
};

char const *string_desc_arr[] = {
    (const char[]) {0x09, 0x04},        // 0: is supported language is English (0x0409)
    "Flatbox",                          // 1: Manufacturer
#ifdef FLATBOX_REV4
    "Flatbox rev4",                     // 2: Product
#endif
#ifdef FLATBOX_REV5
    "Flatbox rev5",                     // 2: Product
#endif
};

// HID report
typedef struct __attribute__ ((packed)) {
    uint16_t buttons;           // bits: 0 = square, 1 = cross, 2 = circle, 3 = triangle,
                                // 4 = L1, 5 = R1, 6 = L2, 7 = R2, 8 = select, 9 = start,
                                // 10 = L3, 11 = R3, 12 = PS
    uint8_t dpadHat;            // 0 = up, 1 = up/right, 2 = right etc., 0x0f = neutral
    uint8_t leftStickXAxis;
    uint8_t leftStickYAxis;
    uint8_t rightStickXAxis;
    uint8_t rightStickYAxis;
    uint8_t dpadRightAxis;
    uint8_t dpadLeftAxis;
    uint8_t dpadUpAxis;
    uint8_t dpadDownAxis;
    uint8_t triangleAxis;
    uint8_t circleAxis;
    uint8_t crossAxis;
    uint8_t squareAxis;
    uint8_t L1Axis;
    uint8_t L2Axis;
    uint8_t R1Axis;
    uint8_t R2Axis;
    uint16_t accelerometerXAxis;        // 10 bits (these are guesses BTW)
    uint16_t accelerometerYAxis;        // 10 bits
    uint16_t accelerometerZAxis;        // 10 bits
    uint16_t gyroscopeAxis;             // 10 bits
} hid_report_t;

hid_report_t report;
hid_report_t prevReport;

void dpad(bool up, bool down, bool left, bool right) {
    // SOCD: up+down=up, left+right=neutral seems to be the standard
    if (up && down) {
        down = false;
        // uncomment this instead if you want up+down=neutral:
        //up = down = false;
    }
    if (left && right) {
        left = right = false;
    }

    switch (stickMode) {
    case 0:
        if (up && !right && !left)
            report.dpadHat = 0;
        else if (up && right)
            report.dpadHat = 1;
        else if (right && !up && !down)
            report.dpadHat = 2;
        else if (right && down)
            report.dpadHat = 3;
        else if (down && !right && !left)
            report.dpadHat = 4;
        else if (down && left)
            report.dpadHat = 5;
        else if (left && !down && !up)
            report.dpadHat = 6;
        else if (left && up)
            report.dpadHat = 7;
        else
            report.dpadHat = 0x0f;

        report.dpadRightAxis = right ? 0xff : 0x00;
        report.dpadLeftAxis = left ? 0xff : 0x00;
        report.dpadUpAxis = up ? 0xff : 0x00;
        report.dpadDownAxis = down ? 0xff : 0x00;
        break;
    case 1:
        report.leftStickXAxis = left ? 0x00 : (right ? 0xFF : 0x80);
        report.leftStickYAxis = up ? 0x00 : (down ? 0xFF : 0x80);
        break;
    }
}

void send_hid_report() {
    if (!tud_hid_ready()) {
        return;
    }

    if (memcmp(&prevReport, &report, sizeof(report))) {
        tud_hid_report(0, &report, sizeof(report));
        memcpy(&prevReport, &report, sizeof(report));
    }
}

void hid_task(void) {
    uint32_t pins = ~gpio_get_all() & pin_mask;

    report.buttons = 0x00;
    report.triangleAxis = 0x00;
    report.circleAxis = 0x00;
    report.crossAxis = 0x00;
    report.squareAxis = 0x00;
    report.L1Axis = 0x00;
    report.L2Axis = 0x00;
    report.R1Axis = 0x00;
    report.R2Axis = 0x00;

    dpad(pins & (1 << PIN_UP),
         pins & (1 << PIN_DOWN),
         pins & (1 << PIN_LEFT),
         pins & (1 << PIN_RIGHT));

    if (pins & (1 << PIN_SQUARE)) {
        report.buttons |= 1 << 0;
        report.squareAxis = 0xff;
    }
    if (pins & (1 << PIN_CROSS)) {
        report.buttons |= 1 << 1;
        report.crossAxis = 0xff;
    }
    if (pins & (1 << PIN_CIRCLE)) {
        report.buttons |= 1 << 2;
        report.circleAxis = 0xff;
    }
    if (pins & (1 << PIN_TRIANGLE)) {
        report.buttons |= 1 << 3;
        report.triangleAxis = 0xff;
    }
    if (pins & (1 << PIN_L1)) {
        report.buttons |= 1 << 4;
        report.L1Axis = 0xff;
    }
    if (pins & (1 << PIN_R1)) {
        report.buttons |= 1 << 5;
        report.R1Axis = 0xff;
    }
    if (pins & (1 << PIN_L2)) {
        report.buttons |= 1 << 6;
        report.L2Axis = 0xff;
    }
    if (pins & (1 << PIN_R2)) {
        report.buttons |= 1 << 7;
        report.R2Axis = 0xff;
    }
    if (pins & (1 << PIN_SELECT)) {
        report.buttons |= 1 << 8;
    }
    if (pins & (1 << PIN_START)) {
        report.buttons |= 1 << 9;
    }
    if (pins & (1 << PIN_L3)) {
        report.buttons |= 1 << 10;
    }
    if (pins & (1 << PIN_R3)) {
        report.buttons |= 1 << 11;
    }
    if (pins & (1 << PIN_PS)) {
        report.buttons |= 1 << 12;
    }

    send_hid_report();
}

void pin_init(uint pin) {
    gpio_init(pin);
    gpio_set_dir(pin, GPIO_IN);
    gpio_pull_up(pin);
}

void pins_init(void) {
    pin_init(PIN_UP);
    pin_init(PIN_DOWN);
    pin_init(PIN_LEFT);
    pin_init(PIN_RIGHT);
    pin_init(PIN_CROSS);
    pin_init(PIN_CIRCLE);
    pin_init(PIN_TRIANGLE);
    pin_init(PIN_SQUARE);
    pin_init(PIN_L1);
    pin_init(PIN_L2);
    pin_init(PIN_R1);
    pin_init(PIN_R2);
    pin_init(PIN_SELECT);
    pin_init(PIN_START);
    pin_init(PIN_L3);
    pin_init(PIN_R3);
    pin_init(PIN_PS);

    // if left is held when plugged in, switch to left stick emulation mode
    if (!gpio_get(PIN_LEFT)) {
        stickMode = 1;
    }
}

void report_init(void) {
    memset(&report, 0, sizeof(report));
    report.dpadHat = 0x0f;
    report.leftStickXAxis = 0x80;
    report.leftStickYAxis = 0x80;
    report.rightStickXAxis = 0x80;
    report.rightStickYAxis = 0x80;
    report.accelerometerXAxis = 0x0200; // not sure why 0x02, but that's what HORI Fighting Stick V3 sends
    report.accelerometerYAxis = 0x0200;
    report.accelerometerZAxis = 0x0200;
    memcpy(&prevReport, &report, sizeof(report));
}

int main(void) {
    board_init();
    pins_init();
    report_init();
    tusb_init();

    while (1) {
        tud_task();             // tinyusb device task
        hid_task();
    }

    return 0;
}

// Invoked when received GET DEVICE DESCRIPTOR
// Application return pointer to descriptor
uint8_t const *tud_descriptor_device_cb(void) {
    return (uint8_t const *) &desc_device;
}

// Invoked when received GET HID REPORT DESCRIPTOR
// Application return pointer to descriptor
// Descriptor contents must exist long enough for transfer to complete
uint8_t const *tud_hid_descriptor_report_cb(uint8_t itf) {
    return desc_hid_report;
}

// Invoked when received GET_REPORT control request
// Application must fill buffer report's content and return its length.
// Return zero will cause the stack to STALL request
uint16_t tud_hid_get_report_cb(uint8_t itf, uint8_t report_id, hid_report_type_t report_type, uint8_t * buffer, uint16_t reqlen) {
    return 0;
}

// Invoked when received SET_REPORT control request or
// received data on OUT endpoint ( Report ID = 0, Type = 0 )
void tud_hid_set_report_cb(uint8_t itf, uint8_t report_id, hid_report_type_t report_type, uint8_t const *buffer, uint16_t bufsize) {
}

// Invoked when received GET CONFIGURATION DESCRIPTOR
// Application return pointer to descriptor
// Descriptor contents must exist long enough for transfer to complete
uint8_t const *tud_descriptor_configuration_cb(uint8_t index) {
    return desc_configuration;
}

static uint16_t _desc_str[32];

// Invoked when received GET STRING DESCRIPTOR request
// Application return pointer to descriptor, whose contents must exist long enough for transfer to complete
uint16_t const *tud_descriptor_string_cb(uint8_t index, uint16_t langid) {
    uint8_t chr_count;

    if (index == 0) {
        memcpy(&_desc_str[1], string_desc_arr[0], 2);
        chr_count = 1;
    } else {
        // Note: the 0xEE index string is a Microsoft OS 1.0 Descriptors.
        // https://docs.microsoft.com/en-us/windows-hardware/drivers/usbcon/microsoft-defined-usb-descriptors

        if (!(index < sizeof(string_desc_arr) / sizeof(string_desc_arr[0])))
            return NULL;

        const char *str = string_desc_arr[index];

        // Cap at max char
        chr_count = strlen(str);
        if (chr_count > 31)
            chr_count = 31;

        // Convert ASCII string into UTF-16
        for (uint8_t i = 0; i < chr_count; i++) {
            _desc_str[1 + i] = str[i];
        }
    }

    // first byte is length (including header), second byte is string type
    _desc_str[0] = (TUSB_DESC_STRING << 8) | (2 * chr_count + 2);

    return _desc_str;
}

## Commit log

2021-08-16 Initial commit
    This repository's history has been rewritten. Sorry about that.
    [Buttoncap.stl, ButtoncapBig.stl, Flatbox-rev1b-Bottom-hotswap.stl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]
2021-09-02 Add rev1.1
    [Flatbox-rev1.1-Bottom-hotswap.stl, Flatbox-rev1.1-Bottom.stl, Flatbox-rev1.1-Top.stl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]
2021-09-02 Add rev3
    [Flatbox-rev3-BOM.csv, Flatbox-rev3-Bottom-hotswap.stl, Flatbox-rev3-Bottom.stl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]
2021-09-21 Add rev4
    [Flatbox-rev4-BOM.csv, Flatbox-rev4-Bottom-hotswap.stl, Flatbox-rev4-Bottom.stl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]
2021-09-22 Add KiCad files
2022-01-12 Add STEP files for case designs
    [Flatbox-rev1.1-case.step, Flatbox-rev2b-case.step, Flatbox-rev3-case.step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]
2022-11-10 Update buttoncap models
    Previously buttoncaps had the stems stick out 4mm, new ones stick out
    3mm. This should allow the buttoncap to properly rest on the surface
    of the switch.
    [Buttoncap.stl, ButtoncapBig.stl]
2022-11-10 Add rev5
    Rev5 uses an RP2040-Zero board as an add-on. The Flatbox rev5 PCB
    doesn't need SMT assembly.
    [Flatbox-rev5-Bottom-hotswap.stl, Flatbox-rev5-Bottom.stl, Flatbox-rev5-Top.stl]
2022-11-21 Better compatibility with flash chips
    When building firmware for rev4 and rev5, use slower settings for
    flash that should give better compatibility with different chips or
    even samples of the same chip.
    #define PICO_XOSC_STARTUP_DELAY_MULTIPLIER 64
    #define PICO_BOOT_STAGE2_CHOOSE_GENERIC_03H 1
    #define PICO_FLASH_SPI_CLKDIV 4
2022-11-23 Revert flash speed changes, leave only xosc
    Previous commit changed three board settings in hopes of improving
    compatibility with some rev4 hardware. One of them applied to the
    crystal oscillator and two to the flash chip. After some more tests in
    the field, I now think only the crystal was problematic so this
    reverts the flash speed changes.
    They didn't necessarily hurt anything and let's keep them in mind in
    case we want to use a different flash chip in the future, but for now
    let's stick to the defaults until there's a reason to do otherwise.
2023-09-04 Add rev5 CNC machined case
    [Flatbox-rev5-CNC-Bottom.step, Flatbox-rev5-CNC-Top.step]
2023-09-21 Add hotswap versions of case STEP files
    [Flatbox-rev1.1-case-hotswap.step, Flatbox-rev2b-case-hotswap.step, Flatbox-rev3-case-hotswap.step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]
2024-05-22 Add info on Brook P5 mini Fighting Board
2024-05-22 Add rev6
    [Flatbox-rev6-BOM.csv, Flatbox-rev6-Bottom-hotswap.stl, Flatbox-rev6-Bottom.stl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]
2024-06-25 Add rev7
    [Flatbox-rev7-Bottom.stl, Flatbox-rev7-Top.stl, Flatbox-rev7-case.step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]
2025-03-24 Add rev4.1
    [Flatbox-rev4.1-BOM.csv, Flatbox-rev4.1-Bottom.stl, Flatbox-rev4.1-Top-A.stl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]
2025-03-25 Add rev8
    [Flatbox-rev8-BOM.csv, Flatbox-rev8-Bottom.stl, Flatbox-rev8-Top-A.stl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]
2026-09-09 Add rev7.1
    [Flatbox-rev7.1-Bottom.stl, Flatbox-rev7.1-Top-A.stl, Flatbox-rev7.1-Top-B.stl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]
2026-09-09 Add rev7.2
    [Flatbox-rev7.2-Bottom.stl, Flatbox-rev7.2-Top-A.stl, Flatbox-rev7.2-Top-B.stl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]
